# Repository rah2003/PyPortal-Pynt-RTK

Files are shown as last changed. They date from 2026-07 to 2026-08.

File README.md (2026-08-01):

# PyPortal-Pynt-RTK — Single-Board RTK Field Device

Third build in the RTK series, following the Metro ESP32-S3 build
([`rah2003/SWMaps-propertylines`](https://github.com/rah2003/SWMaps-propertylines),
branch `claude/esp32-rtk-bridge-firmware-yokgan`) and the interim two-MCU
RTK-Feather build (local, `C:\Projects\RTK-Feather`). This build collapses
everything onto one board: an Adafruit PyPortal Pynt drives the ArduSimple
simpleRTK2B Lite (u-blox ZED-F9P) over **F9P UART1**, keeping **UART2 free
for a future plug-in radio**.

## Hardware

| Role | Part |
|---|---|
| MCU + display | Adafruit PyPortal Pynt (#4465) — ATSAMD51J20 @ 120 MHz, 2.4" 320×240 ILI9341 TFT (8-bit parallel), resistive touch, microSD, 8 MB QSPI flash |
| WiFi | ESP32 AirLift co-processor (NINA-W102) on the Pynt, driven over SPI (WiFiNINA) |
| GNSS | ArduSimple simpleRTK2B Lite (u-blox ZED-F9P), UART1 via Pixhawk JST-GH — **moved over from the RTK-Feather rig** |
| Antenna | Calian/Tallysman HC977 helical (33-HC977-35, 35 dB LNA), triple-band + L-band, 3.3 V bias ~21 mA, no ground plane needed |
| Storage | PNY Elite 32 GB microSDHC UHS-I U1 (in the Pynt's slot) |
| Phone | iPhone + **SW Maps over BLE NUS** (Phase 5, verified 2026-07-28) and/or **QField over WiFi TCP** (verified 2026-07-19) — both links run simultaneously |

## Hard constraints (inherited + new)

1. **F9P UART2 / XBee socket is reserved** for a future plug-in radio. No
   firmware function may depend on it. (Base mode may *configure* RTCM3
   output on UART2 — config only, no wiring.)
2. **F9P UART1 is the Pynt's working port** (RTCM3 in; NMEA + UBX out) via
   the Pynt's D3/D4 hardware UART. ⚠ **The Pynt's D3/D4 sockets are
   reportedly silkscreen-swapped** vs. the classic PyPortal — verify with a
   scope/loopback before trusting labels (see `docs/QUESTIONS.md`).
3. ~~The AirLift cannot run WiFi and BLE simultaneously.~~ **Retired
   2026-07-28 (Phase 5):** the AirLift now runs the vendored
   `nina-fw 3.0.1-airlift` module firmware (BLE HCI multiplexed onto the
   SPI link) with the upstream WiFiNINA 2.1.1 + ArduinoBLE 2.1.0 host
   stack — WiFi + BLE simultaneous, proven in a 75-min soak on the
   assembled unit (`docs/coex-bench.md`). The `pynt-rover` env still
   builds the original WiFi-only Adafruit-fork stack, byte-identical,
   as the rollback path; `pynt-rover-coex` is the live configuration.
4. **The ESP32 AirLift and the microSD share the main SPI bus.** NTRIP/TCP
   traffic and RAWX log writes contend — the logging pipeline must tolerate
   SPI stalls (two-stage buffering, ported from the Feather build).
5. **The Lite's USB is an FTDI bridge onto UART1.** Never attach the
   u-center adapter while the Pynt drives UART1 — one driver at a time.

## Architecture (single MCU, cooperative superloop or light RTOS-less tasks)

```
                          ┌──────────── PyPortal Pynt (SAMD51) ────────────┐
 iPhone hotspot ──WiFi──► │ ESP32 AirLift ◄─SPI─► NTRIP client ─┐          │
                          │  (WiFi+BLE coex)                    ▼          │
 QField ◄───TCP/NMEA────► │  TCP server ◄──┬─ NMEA tee ◄─ UART (D3/D4) ◄───┼──► F9P UART1
 SW Maps ◄──BLE NUS─────► │  NUS notify ◄──┘      │       RTCM3 ▲──────────┘   (UART2: radio,
 browser ◄──HTTP :80────► │  web config GUI       │                            untouched)
                          │  UBX extractor ◄──────┘                        │
                          │       ▼                                        │
                          │  microSD (.ubx RAWX, shared SPI)               │
                          │  TFT 320×240 (8-bit parallel) + resistive touch│
                          └────────────────────────────────────────────────┘
```

Module lineage (ported/adapted copies, per the Feather precedent — not
submodules): `ringbuf.h`, `ubx_extractor`, `ntrip_client`, `gnss_config`,
`settings`/serial-menu from RTK-Feather & Metro. The Feather's two-MCU
`status_link` protocol disappears entirely. New modules: TFT/touch UI
(Adafruit_ILI9341 in 8-bit-parallel mode + touch driver), WiFiNINA transport
for NTRIP, TCP NMEA server, SD logger on shared SPI.

## Decisions (2026-07-11)

- **Toolchain:** PlatformIO, Arduino C++ (Adafruit SAMD51 core) — maximizes
  reuse of the proven Metro/Feather modules.
- **v1 scope:** Rover **and** Base mode, with RAWX `.ubx` logging to the
  Pynt's own microSD.
- **Phone link:** ~~SW Maps via WiFi TCP; no BLE ever on this hardware~~
  → since Phase 5: SW Maps over BLE NUS + QField over TCP, concurrently.
- **Touch UI:** status pages (fix quality, correction age, NTRIP state,
  logging, sats/SNR) + touch controls (log start/stop, rover/base switch,
  safe shutdown). Credentials/config via USB serial menu — no on-screen
  keyboard in v1. **Portrait orientation (240×320)** — enclosure comes
  after the electronics and will be built around portrait mounting.
- **Repo:** public GitHub, `PyPortal-Pynt-RTK`. Secrets via gitignored
  `secrets.h` (`secrets.example.h` committed), same as Feather.
- **Inherited defaults (from Metro via Feather):** caster
  `www.acorn-gnss.net:2101` (2026-07-19: the bare apex hostname the Metro
  build used lost its DNS A record — `www.` is the live caster now),
  mounts `VRS_SouthCentral_RTCM3`/`MS_RTCM3`, WiFi
  via iPhone personal hotspot, elevation mask 12°, constellations
  GPS+GLO+GAL+BDS (SBAS/QZSS off), F9P UART1 @ 115200.

## Repository layout

```
docs/
  QUESTIONS.md              Open/answered clarifying questions
  hardware/
    wiring.md               4-wire interconnect, label-swap check, SERCOM recipe
    power.md                Power tree decision (shape A/B) + checks P1-P4
    platform.md             Bus map, SPI contention math, TFT/touch notes
    ucenter-config.md       F9P re-verification (unit moved from Feather rig)
    checklists.md           Per-board bring-up + integration gates
  coex-bench.md             Phase 5 bench: spikes, soaks, findings, rollback
  web-config-spike.md       Web GUI plan + W0-W5 bench results
firmware/
  pynt/bringup/             Phase 1 serial-menu test suite
  pynt/rover/               Rover firmware (superloop: gnss, ntrip, tcp_nmea,
                            ble_nus*, web_config*, sd_logger, ui, serial_menu,
                            settings — * = coex env only)
  nina-fw-airlift/          Vendored arduino/nina-fw 3.0.1 + MOSI-14 patch
                            (the AirLift module firmware; AIRLIFT.md)
  spike/                    Spare-board spikes + esptool passthrough bridges
lib/                        Vendored ArduinoBLE 2.1.0 (patched) + Arduino_SpiNINA
tools/webui/                Web GUI source -> gzipped PROGMEM asset pipeline
platformio.ini              pynt-bringup, pynt-rover (WiFi-only fallback),
                            pynt-rover-coex (live: WiFi+BLE+web), spikes,
                            passthrough-* flash bridges
```

## Phases

- [x] **Phase 0 — Hardware verification pack** (`docs/hardware/`): wiring
      diagram (Pixhawk JST pinout → D3/D4, incl. the label-swap check),
      power tree (single-bank vs two-feed; decision pending measurements
      P1–P4), u-center re-verification checklist, bring-up checklists,
      platform/SPI-contention analysis — **verify wiring against these
      documents and current vendor docs before powering anything**.
- [x] **Phase 1 — Bring-up sketches**: serial test menu covering TFT +
      portrait rotations, touch raw dump, AirLift version/scan/join + TCP
      echo (the SW Maps path), SD write latency, D3/D4 UART loopback +
      TX-socket identify (the label-swap tests), live NMEA echo, free-RAM
      report. **Bench pass complete** (`docs/hardware/bringup-log.md`,
      2026-07-17): silkscreen swap confirmed real (sockets tape-labeled),
      touch pin off-by-one found and fixed (18/19/20/21), rotation 2
      chosen, corner calibration captured, WiFi/TCP/SD all healthy.
- [x] **Phase 2 — Rover firmware**: written and **compiling clean**
      (2026-07-11: RAM 9.7 % / flash 10.3 %, `pynt-rover` env). NTRIP
      state machine (ported Metro→Feather→here, polled instead of tasked)
      → RTCM3 → F9P UART1; GNSS config via SparkFun v3 VALSET; RAWX/SFRBX
      → SparkFun file buffer → time-named `.ubx` on SD (one bounded
      512 B write per loop pass, pre-allocated contiguous files, 8 s
      sync); portrait touch UI (fix-state header, POS/SYS pages, LOG /
      PAGE / PWR buttons with two-tap shutdown confirm); SW Maps TCP NMEA
      server on :10110; SD `/config.txt` settings + serial menu.
      **1-hour full-stack soak PASSED 2026-07-19** (bringup-log.md §3
      gate 4): 66 min, zero resets, RTK FIX from minute 2 to the end,
      NTRIP uninterrupted, 10.8 MB RAWX written (~10 MB/h). Found live:
      caster DNS moved to `www.`, nina-fw TCP accept is data-gated, and
      a client-dedup bug (fixed) — see Q19. Touch buttons + on-screen
      BUFH still unverified (headless soak).
- [x] **Phase 3 — Base mode**: written and **compiling clean** (2026-07-11:
      RAM 9.7 % / flash 11.1 %). Survey-in (dur/acc from settings) or
      fixed-LLH TMODE; RTCM3 out **configured on UART2 only** (MSM4 set
      1005/1074/1084/1094/1124/1230 — config only, the XBee socket stays
      empty and UART2 baud is left for the future radio to decide);
      NAV-SVIN progress in the header + SVIN line; `b_` log prefix; live
      rover/base switch via serial menu (`mode=base`). **Spot check
      PASSED 2026-07-19**: live switch both directions, survey-in valid
      at 300 s / 1.46 m on the defaults, UART2 untouched. (The `b_`
      prefix needed a same-day fix — the log now rotates on a live mode
      switch; rotation re-check pending next bench sit.)
- [ ] **Phase 4 — Polish**: logging analytics, light-sensor auto-dim,
      speaker fix/loss chime. (On-screen config keyboard **descoped** —
      the Phase 6 web GUI covers all credential/config entry.)
- [x] **Phase 5 — WiFi+BLE coexistence — DONE 2026-07-28**
      (`docs/coex-bench.md`, branch `coex/nina-fw-airlift`): vendored
      arduino/nina-fw 3.0.1 with a one-pin AirLift patch (SPI MOSI
      12→14), host stack swapped to upstream WiFiNINA 2.1.1 +
      ArduinoBLE 2.1.0 (vendored, 2-line SPI-HCI transport gate patch)
      + Arduino_SpiNINA. De-risked on a Metro M4 AirLift and a
      hand-wired HUZZAH32 rig before touching the Pynt (stock firmware
      backed up first; §8 rollback keeps `pynt-rover` untouched).
      75-min integration soak on the assembled unit: RAWX + NTRIP +
      TCP + BLE NUS concurrent, zero NTRIP teardowns, 50k TCP
      sentences no drops, ~58 min BLE streaming — **owner ran iOS
      SW Maps live over BLE** (Q19 closed, both phone paths).
      Notable firmware truths found and designed around: data-gated
      `server.available()` (fixed via `accept()`), `WiFi.end()` wedges
      STA rejoin, the NINA socket table leaks across `WiFi.end()`,
      `scanNetworks()` kills any live network, and this Pynt's UF2
      bootloader wedges when parked idle (flash via 1200-touch flow).
- [x] **Phase 6 — Web config GUI — v1 (W0–W5) DONE 2026-07-31**
      (`docs/web-config-spike.md`, branch `web-config`): on-board HTTP
      server (port 80, Basic auth, TRNG-generated passwords shown on
      the TFT WEB page) serving a gzipped-from-PROGMEM SPA — live
      status dashboard, WiFi provisioning with a touch-button AP mode
      (both AP transitions are reboots by design), GNSS tuning (rate /
      dynamic model / mask / GSV via live VALSET), caster management
      (live reconnect), logging control, BLE + System cards (instant
      admin-password rotation). W6 (mDNS, sourcetable browser, SD file
      manager, profiles) deferred.

## Reference builds

| | Metro (primary) | RTK-Feather (interim) | **This build** |
|---|---|---|---|
| MCU | ESP32-S3 (dual core) | HUZZAH32 + M0 Adalogger | SAMD51 (single) |
| WiFi | native | native (HUZZAH32) | ESP32 AirLift co-proc (SPI) |
| Display | — | 128×32 OLED + 3 buttons | 320×240 TFT + touch |
| Logging | on-board | second MCU + SD | on-board microSD (shared SPI) |
| Phone | BLE NUS | deferred | BLE NUS + WiFi TCP, concurrent |
| Config | serial | serial | web GUI + touch + serial |
| Status | Phases 1–3 built | retired (boards are coex spares) | Phases 0–3, 5, 6 done; field-proven |

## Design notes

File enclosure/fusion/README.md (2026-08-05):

# Fusion workflow

`pynt_rtk_enclosure.py` builds the rev A enclosure (Shell + Cover
components) as a fresh parametric document inside Autodesk Fusion. It is
a geometry port of `../pynt_rtk_enclosure.scad`; design rationale lives
in `docs/hardware/enclosure.md`. Edit the constants at the top of the
script and re-run to regenerate — it never touches the active document.

## Run it

1. Fusion → **Utilities → Add-Ins → Scripts and Add-Ins** (Shift+S)
2. Green **+** next to *My Scripts*, browse to this `enclosure/fusion/`
   folder
3. Select `pynt_rtk_enclosure` → **Run**

A dialog reports the key derived numbers (exterior size, pole-shoulder →
antenna-pad height for the SW Maps antenna-height entry).

## Fit-check with vendor CAD

`../vendor/` holds the manufacturers' own models — insert them with
**Insert → Insert CAD** and position against the enclosure:

| File | What | Source |
|---|---|---|
| `pyportal_pynt_4465.step` | PyPortal Pynt | Adafruit_CAD_Parts (GitHub) |
| `simpleRTK2B_Lite-00.step` | simpleRTK2B Lite | ardusimple.com |
| `ardusimple_usbc_carrier.step` | USB-C XBee carrier | ardusimple.com |
| `pyportal_pynt_4465.stl` | Pynt mesh (backup) | Adafruit_CAD_Parts |

The folder is gitignored (large binaries); re-download from the sources
above if missing.

## Test prints

Set `PART = 'base_test'` or `'bezel_test'` at the top of the script and
run — the trimmed body is exported automatically to
`enclosure/prints/<part>.stl`. `base_test` is the bottom 25 mm (nut
pocket fit, USB plug vs boss clearance, SD reach, vent grilles);
`bezel_test` is one top bezel corner (window chamfer vs touch reach,
eyebrow, one top-ear insert pocket). Same regions as the .scad `part`
selector. Print both front-face-down like the shell; `base_test` needs
a local support block under the nut boss's bed-facing face (a plain
90° side overhang — see the print notes in `docs/hardware/enclosure.md`
for why it can't be chamfered), `bezel_test` is support-free.

## Export for printing

Right-click **Shell** / **Cover** in the browser → *Save As Mesh* → STL,
or 3D Print. Print notes (material, orientation, the two test prints)
are in `docs/hardware/enclosure.md`.

## Before printing for real

- Carrier dimensions are settled: the owner's mini-USB FTDI carrier is
  identical to the USB-C carrier except the connector (confirmed
  2026-07-19), so the STEP-derived `CARRIER_*` defaults apply.
- `PYNT_MIRROR = -1` confirmed 2026-07-19: USB on the viewer's left
  looking at the screen.
- Cover screws are plain through-holes — use **pan-head** M3s (no
  countersinks modeled).

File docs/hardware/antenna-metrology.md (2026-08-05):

# Antenna Metrology — ARP & Phase-Center Offsets (2026-08-04)

Closes the 2026-08-03 team review's **P6** finding ("no ARP, no antenna
height, no phase-centre data anywhere"). Owner-confirmed 2026-08-04.

## ARP definition (this build)

**ARP = the nut-boss underside** — the D-shaped ring (679 mm²) around
the Ø17 pole hole at the bottom of the enclosure. It is simultaneously:

- the bottom face of the 5/8"-11 nut pocket's boss,
- the **global lowest surface of the assembled enclosure** (verified by
  exhaustive enumeration of every down-facing face in the as-printed
  meshes `enclosure/prints/b_shell_full.stl` + `b_band_full.stl`:
  zero vertices below it), and
- the **print-bed face** (both rev-B parts print nut-side down).

The pole stud passes through the Ø17 clearance hole; the 5/8"-11 nut is
captured in the hex pocket above; nothing seats internally — the pole
top bears on this same exterior face.

## Enclosure vertical stack (model frame: 0 = housing exterior floor)

| Plane | Height | Source |
|---|---|---|
| ARP (nut-boss face, print bed) | **−17.2** | `BOSS_H = nut 13.9 + 0.3 + floor 3.0` |
| Screw-head seats (recessed in funnel) | −2.0 | mesh |
| Housing exterior bottom (USB/SD face, 756 mm²) | 0.0 | mesh |
| Shell top exterior | +88.6 | `EXT_H` |
| **HC977 seat plane** (Ø44.8 recess floor in the lid pad) | **+89.1** | `EXT_H + pad 1.5 − recess 1.0` |
| Antenna pad top | +90.1 | mesh |

**A = ARP → antenna seat = 89.1 − (−17.2) = 106.3 mm.
Total case height (ARP → pad top) = 107.3 mm.**

Geometry facts (measured from the meshes, not just the source scripts):
pole axis and antenna boresight are **collinear** (hole/recess/SMA
centroids concentric within ≤0.3 mm of tessellation noise), both normal
to the ARP plane — **0° tilt, ~0 horizontal offset**. The axis sits at
X = 0, 31.0 mm behind the front face. Antenna clocking: the a=0 M2.5
hole points dead rearward (antenna "north" away from the screen).

## HC977 phase-center data (Calian datasheet Rev. 202203 + mechanical drawing)

Antenna: Calian/Tallysman **HC977**, part 33-HC977-35 (35 dB LNA),
s/n 20200624 (Q15). PCO along the antenna z-axis from its base
(= our seat plane):

- **L1: 32 mm** · **L2/L5: 37 mm** · PC variation **±3.0 mm** per band
  (note: L1 and L2/L5 are *distinct* nominal phase centers 5 mm apart —
  not one shared PC)
- Sources: datasheet spec table ("PCO (z-axis, mm): 32 (L1), 37 (L2)")
  and `HC977_MECHANICAL_DRAWING.svg` ("L1 = 32 mm, L2 / L5 = 37 mm"),
  both at <https://www.tallysman.com/product/hc977-triple-band-helical-antenna-with-l-band/>
- Antenna: Ø44.2 × 62.4 mm, 42 g, base mount 3× M2.5 (6 mm deep, 120°,
  Ø26.6 BCD) — **no native 5/8"-11 thread**; this enclosure IS the
  5/8"-11 adapter.

## The numbers a surveyor needs

```
ARP → L1  phase center = 106.3 + 32 = 138.3 mm   (±3.0)
ARP → L2/L5 phase center = 106.3 + 37 = 143.3 mm (±3.0)
horizontal PC offset from pole axis ≈ 0 (coaxial, 0° tilt)
```

Antenna height for RTK work = pole/ARP height + the offset above for
the band your software expects (L1 is the usual convention). For RINEX
post-processing of the RAWX logs: ANTENNA: DELTA H = ARP height; apply
the per-band PCOs from this table.

## Verification note (one-time caliper check, still open)

The stack above is **design-nominal from the print meshes**. FDM
first-layer squish and the HC977's base O-ring can move reality a few
tenths of a millimeter. To close: caliper the assembled case —
**ARP face → pad top should read 107.3 mm** (or ARP → recess floor
106.3 with the antenna off). Record the measured value here.

Annotated views (generated from the print meshes):
`pynt-arp-side-annotated.png`, `pynt-arp-top-annotated.png` (this
directory). Design source: `enclosure/` at the repo root.

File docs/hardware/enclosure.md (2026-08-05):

# Enclosure — Design Doc (rev A8, 2026-07-20)

3D-printed handheld/pole-top enclosure for the full stack: PyPortal Pynt
(portrait, rotation 2), simpleRTK2B Lite on its USB carrier board, HC977
helical antenna on the lid, 5/8"-11 survey-pole nut captured in the base.
CAD sources: `enclosure/pynt_rtk_enclosure.scad` (parametric OpenSCAD)
and `enclosure/fusion/pynt_rtk_enclosure.py` (Autodesk Fusion build
script, same geometry — see `enclosure/fusion/README.md`). **The
parameter blocks are the single source of truth for numbers** — keep the
two in sync; this doc explains the *why*. Vendor STEP models for
fit-checks live in `enclosure/vendor/`.

Owner decisions (2026-07-18): printed on owner's FDM printer; handheld
unit with internal survey-pole nut; antenna on top of enclosure via the
owner's SMA extension cable; battery bank external for now (bottom
attachment possible later); light-rain resistant, not sealed.

Rev A1 (2026-07-19, after first Fusion build): interior deepened
41.5 → 52 so the full Ø46 antenna pad (HC977 base Ø44.2) lands on the
lid — rev A truncated it at the back edge. SMA bulkhead hole is plain
round (owner's adapter has no D-flat; lock washer inside for
anti-rotation). Battery provisions moved from the front floor corners
to the rear floor behind the nut prism — at the front they collided
with the Pynt's lower mounting ears.

Rev A2 (2026-07-19, owner assembly critique): `pynt_mirror` confirmed
**−1** — USB lands on the viewer's **left** looking at the screen in
rotation-2 portrait. The Pynt's **bottom ears are now pinned, not
screwed** (Ø2.7 pins into the Ø3.0 ear holes): the bottom cover posts
sit ~1 mm off that screw axis, so neither a driver nor an insert iron
could ever reach; the top two ears keep M2.5 heat-set inserts, which
have straight access past the top posts (14 mm off-axis). Vent slots
became 3-finger **grilles** so they can't be mistaken for ports, and
the SD slot's front edge is aligned with the USB slot's.

Rev A3 (2026-07-19): all printed heat-set inserts standardized to
**M3, Ø4.0 pilot** (owner stocks 4/6/8 mm lengths; per-location
lengths in the BOM) — M3 screws are a close fit through the Pynt's
Ø3.0 ear holes. Bottom-battery provisions **removed**; a future
battery dock will be its own design. Added **3× M2.5 through-holes in
the lid** on the HC977's insert bolt circle for a positive antenna
hold-down, one hole aimed dead rearward as the antenna-north
reference (see 8).

Rev A4 (2026-07-19, first test-print findings): bezel_test PASSED on
screen-flush fit and boss height; base_test failed on the locating
pins (horizontal stubs print badly, won't enter the ear holes) and
the round Ø8 top bosses hit the glass side edge (owner measured
~2.5 mm hole-center→glass). Fixes: top bosses are now rectangular,
trimmed 2.2 mm inboard, wall-merged outboard, 45°-tapered bottoms,
**direct-thread M3 (Ø2.5 pilots, no inserts)**; the bottom edge drops
into a **capture channel** beside the SD body sized for the bottom
edge's 2.9 mm display stack (1.0 less than the glass — owner
measured). PCB plane unchanged → USB/SD slots unchanged. Reprint both
test parts.

Rev A5 (2026-07-19): the eyebrow's 45° underside is now **colinear
with the window's top chamfer** — one continuous plane from the
window's inner top edge to the eyebrow tip. The old shape sat ~1 mm
off the chamfer plane and printed as a visible step / double edge
(bezel_test finding).

Rev A6 (2026-07-19): bottom capture moved from the board's bottom edge
to the **ears** — two slots at the side walls with a 2.0 mm gap for
the bare 1.6 mm PCB tabs (0.2 clearance per side) and a 45° rear
lead-in. Assembly is now: **slide the board straight down** until the
ears seat, then drive the two top screws. The rev-A4 bottom-edge
channel beside the SD body is deleted (its 2.9 mm bottom-stack
measurement stays recorded in the component table). Same day: rear
wall reworked — vertical capture face to y 5.7 with the lead-in bevel
halved (owner request: give the board's rear real vertical backing),
outboard gap end filled for print support.

Rev A7 (2026-07-20, base_test fit findings): **zero board standoff**
— the Pynt's bottom edge now sits ON the interior floor (`pynt_y0 =
floor_t`; any gap made USB/SD unreachable — everything keyed to the
board moves down with it, so the frame stays correct). **Bottom wall
halved to 1.4** (`floor_t`) for plug/card reach — combined the
connectors sit ~2.9 closer to the outside face. **SD slot widened
2 mm toward the enclosure center only** (slot read ~2 mm off
outboard). **Teardrop profiles** on all horizontally-printed round
holes (pole, SMA, 3 antenna holes — apex up in the front-face-down
print) so their tops print uncompressed. Ear slots re-referenced to
the floor; the base fill under the ear is gone (no gap remains).
Caveat: the nut load path now crosses a 1.4 floor — verify on the
base_test reprint before trusting pole mounting.

Rev A8 (2026-07-20, owner decision): the REFERENCE print orientation
for **both enclosures is now NUT-SIDE DOWN** (bottom-up). The nut
boss prints flat on the bed (no more support patch under it — that
whole problem disappears); pole / SMA / antenna holes are vertical
now, so they reverted to plain round (a teardrop notch would spoil
the SMA gasket seat); the **teardrops moved to the z-axis holes**
(light pinhole, Pynt pilots, cover-post pilots), which print
horizontally in this orientation. Supports still needed in rev A
bottom-up: the shell's interior lid ceiling (a large flat span) and
the window's top edge (long bridge). The cover still prints flat.

## Rev B — the "D" shell (owner-specified, 2026-07-20)

`enclosure/fusion/pynt_rtk_enclosure_b.py` (Fusion-only; rev A kept).
Owner's markup, implemented literally: **plan view is a "D"** — the
front/Pynt half is identical to rev A (all vertical walls stay
vertical, zero edits to the front), and the square rear corners are
removed. From the **antenna centerline (z 31)** the full-width sides
transition via straight **tangent lines** to a rear **arc R26.8 about
the pole axis** (= the current antenna→body rear standoff, so the
rear-most point stays at z 57.8 and the antenna footprint is always
covered).

- **Case back** = a curved band, same 2.8 thickness, constant profile
  down the entire height, flush with the outer surface. Captured on
  all four edges: it stands on the shell floor; its top edge rides in
  a 1.0 groove under the integral lid; its vertical end edges carry
  **half-thickness tongues (R24–25.4, 3.6° span)** that slide into
  matching grooves rebated into the tangent walls — full-height
  lateral support both sides (first band test read loose — groove
  clearances **halved** to 0.075 radial per side, +0.2/+0.35° angular
  padding; **re-print confirmed a good fit**, 2026-07-25). Behind each
  band end a **1.0 anti-flex ledge** stands proud of the interior face
  (same 0.075 stop gap) so the band bears on it instead of deflecting
  inward; the rib hooks ~0.6 into the tangent wall past the groove end
  so it's braced full-height, and prints support-free nut-side down; and 2× M3×8 come up from BELOW through
  the floor (heads face down — rain-safe) into **M3×4 heat-set
  inserts** (Ø4.0 pilots) in bosses welded to the band — inserts set
  from the boss undersides before the band goes in. Pull the band
  straight back for full-width service access.
- **Carrier**: mount plane z 48.5 (assembly finding 2026-07-26: +1.0
  more standoff needed; gusset undersides steepen to ~51°, still
  support-free) — originally moved inside so
  the M3×4 teardrop pockets keep ≥1.0 outer skin (shallower bosses
  let the cuts show through the back — owner catch), and the grid is
  **raised 2.5** (`carrier_y0` 8.5) so the lower bosses clear the
  case-back insert bosses (interference — owner catch). Every boss
  carries a **45° gusset fin** tapering to the band's inner face, so
  the horizontal bosses print support-free. Stack front z 34.2; radio
  void intact.
- The old rear corner posts are gone with the corners. The **nut boss
  is a mini-D echoing the shell**: flat front at z 16.5 (USB plug
  clearance preserved), straight sides to the pole axis, rounded back
  R16.5 — same 2.4–2.5 walls around the hex pocket as the old prism.
  A **D-shaped funnel skirt** lofts from the boss bottom out to the
  housing outline at the base plane: planar tapers on the flats
  (~51°), lofted arc taper on the back (~59°), shared flat front
  plane at z 16.5 so the USB/SD/vent strip stays clear — and the
  underside becomes self-supporting in the bottom-up print. The
  case-back screws pass straight through the funnel as **plain
  clearance holes with Ø6.6 counterbores** (no added bosses — owner
  decision): at z 48.8 the head seat at y −2 is a complete ring, and
  the bore columns are cut clear down to **below the funnel surface's
  deepest point** (a shallower cut leaves an uncut crescent shelf
  inside the bore that blocks the screw head — owner caught it as a
  non-round mouth). Verified: Ø5.7–6.0 pan head travels the clean
  Ø6.6 column to the seat and back with ≥0.3 radial clearance.
  M3×8 reaches ~4 mm into the inserts. **Sharp exterior edges are
  chamfered**: 1.2 on the front vertical corners and top rim, 0.6 on
  the front strip's 90° edges (bottom line, strip sides, strip↔funnel
  crease at z 16.5 — owner markup); the shallow funnel/wall creases
  are excluded (any chamfer there fails to compute, and at ~40° they
  aren't truly sharp). Test-fit prints:
  `enclosure/prints/b_base_test.stl` (bottom 30 — funnel, boss,
  counterbores, ear slots, USB/SD, tongue grooves) and
  `b_band_test.stl` (band segment with insert bosses + tongues).
  All bottom penetrations and the whole front half carry over from
  rev A8 unchanged; lid pad/SMA/BCD holes unchanged on the pole axis.
- **Print**: both parts nut-side down. The band is a constant-section
  tube segment — zero support; the shell keeps rev A's caveats
  (interior lid ceiling + window top edge). Full print files:
  `enclosure/prints/b_shell_full.stl` (57.8 cm³) and
  `b_band_full.stl` (14.4 cm³), pre-oriented Z-up for the slicer;
  MK4S/PETG settings incl. the lid-ceiling support plan in
  `enclosure/prints/print-settings-mk4s-petg.md` (paint-only
  enforcers: interior ceiling, front strip underside, window lintel;
  0.25 contact Z, snug style, extract the block through the rear
  aperture).

## Concept

```
            HC977 helical (Ø44 base, 62 mm tall)
                 │  screws onto ↓
        ┌── SMA bulkhead jack through lid, on the pole axis ──┐
  ┌─────┴──────────────────────────────┐  ← lid/top face      │
  │  JST headroom (D3/D4 harness U-turn)│                      │
  │ ┌───────────┐  ┌──────────────────┐│                      │
  │ │ PyPortal  │  │ carrier + Lite   ││  ← removable back    │
  │ │ Pynt      │  │ stack on the     ││    cover (4× M3)     │
  │ │ portrait, │  │ back cover;      ││                      │
  │ │ screen in │  │ XBee radio void  ││                      │
  │ │ front face│  │ above the Lite   ││                      │
  │ └───────────┘  └──────────────────┘│                      │
  │  USB out ↓   SD ↓   [5/8-11 nut]───┼── pole axis ─────────┘
  └─────────────────┬──────────────────┘
                    └─ external hex boss under the base, nut captured
                       inside; survey pole threads in from below
```

- **Pole axis** (X = width center, 31 mm behind the front face) carries
  both the 5/8-11 nut below and the SMA bulkhead above, so the antenna
  sits plumb over the pole. It lands behind the box's geometric depth
  center because the bottom boss must clear the USB/SD exits at the
  front of the base — slightly nose-heavy in hand, irrelevant on a pole.
- **All signal wiring is internal.** Only four penetrations exist: SMA
  bulkhead (top, gasket-washer sealed — proper rain-proof joint),
  micro-USB power slot (bottom, faces down), microSD slot (bottom, faces
  down), light-sensor pinhole (front bezel). No side penetrations.

## Component facts the geometry is built on

All verified from vendor CAD unless flagged. Sources: Adafruit
`Adafruit PyPortal Pynt.brd` + `4465 PyPortal Pynt.step`
(github.com/adafruit/Adafruit-PyPortal-PCB, Adafruit_CAD_Parts);
ArduSimple `simpleRTK2B_Lite-00.STEP` + USB-C carrier
`AS-ADP-USBC-TO-XBEE-00-R00.step` (ardusimple.com); Calian HC977
datasheet Rev 202203.

| Component | Numbers that matter |
|---|---|
| PyPortal Pynt (#4465) | Body 66.8 × 43.2 × 1.57 mm — **not** the classic-PyPortal outline. Envelope incl. 4 mounting ears 66.8 × 53.2. Holes Ø3.0 on a 61.72 × 47.88 grid (M2.5). Stack: touch overlay +3.90 front / JSTs +4.80 back → 10.27 total. Viewing window 50.25 × 38.6, centered on the body. Micro-USB + microSD on one short edge (down, in rotation 2), D3/D4 JSTs on the other (up). Reset faces **backward**; light sensor looks through the PCB to the **front**. Owner-measured 2026-07-19: display stack at the bottom edge is 2.9 (1.0 less than the 3.9 glass stack); glass side edges ≈2.5 mm from the top ear hole centers. |
| simpleRTK2B Lite | PCB 27.68 × 41.53 × 1.0. Edge-launch SMA jack protrudes 9.5 past the SMA edge. JST-GH tallest top-side part (+4.35). Underside XBee pins protrude **5.97 below** the PCB. 3× Ø2.1 holes (unused here — the carrier is the mount). |
| USB carrier (ArduSimple XBee FTDI carrier, mini-USB variant) | PCB 41.0 × 26.0 × 1.6; 4 corner holes ~Ø3.6 on a **35.0 × 20.0** grid, 3 mm from each edge. Assembled carrier+Lite stack ≈ 15.3 tall incl. underside solder tails; Lite overhangs the non-USB end, SMA tip ≈ 17.2 past the carrier edge. Dimensions taken from the USB-C variant's STEP (AS-ADP-USBC-TO-XBEE-00) — **owner confirmed 2026-07-19 the mini-USB board is identical except the connector itself**, which is internal-only here, so the USB-C numbers apply as-is. |
| HC977 (33-HC977-35) | Radome: base Ø44.2, top Ø38.8, h 62.4, IP69K, 42 g. SMA male on base underside + 3× M2.5 inserts, 6 deep, 120°, on a **Ø26.6 bolt circle** (Calian mechanical drawing, confirmed 2026-07-28; O-ring on the base underside). Phase center above base: 32 mm (L1) / 37 mm (L2). 2.5–16 V bias — a passive SMA extension passes the F9P's 3.3 V untouched. |
| 5/8"-11 hex nut (steel) | Across flats 23.8, across corners ≈ 27.5, thickness ≈ 13.9. Plastic never carries the thread. |

## Layout decisions

1. **Pynt mounting (rev A4)**: the **top two ears screw** — M3×6
   **threading directly into Ø2.5 pilots** (no inserts: the glass side
   edge is only ~2.5 mm from the hole center, so there is no room for
   an insert-sized boss; M3 is a close fit through the Pynt's Ø3.0
   ear holes; driven from the back with the cover off, straight
   access 14 mm clear of the top posts). Bosses are **rectangular,
   trimmed to 2.2 mm inboard** of the hole center (≈1 mm wall beside
   the pilot, ~0.3 mm clear of the glass), merged into the side walls
   outboard, 45° taper on the bottom face (support-free in any print
   orientation). The **bottom ears slide down into capture slots** at
   the side walls: each slot is a 2.0 mm gap (0.2 clearance per side
   of the 1.6 PCB tab) between a front block (z 3–7.2, trimmed 2.0 mm
   inboard of the hole center to clear the glass) and a rear wall
   with a **vertical capture face (z 9.2) up to y 5.7** — real rear
   backing for the PCB's lower 1.4 mm — topped by a **halved 45°
   lead-in** (y 5.7 → 7.3) for the slide-down entry. The outboard end
   of the gap (past the ear tip, ~0.9 mm from the side wall) is
   filled to anchor the rear wall's printed underside; the remaining
   ~1.6 mm underside overhang over the gap prints clean. **End stops
   relieved to ±27.3 (2026-07-26)**: the first assembly bound one top
   screw — the symmetric stops centered the board while the pilots
   follow the STEP's hole grid (midpoint 0.19 off the body
   centerline), and M3 through the Ø3.0 ear holes has ~zero slop, so
   two conflicting datums can't coexist. The slots now only capture
   the ears vertically; the board centers laterally on the screws
   (start both before tightening). On the USB
   side the rear pieces also stop 0.25 mm outboard of the USB slot so
   the plug path stays clear (the front block, z ≤ 7.2, never
   conflicts — the USB slot spans z 8–13); the vent grilles sit at
   centers ±14.5 to clear the slot blocks. Assembly:
   slide the board straight down until the ears seat, then drive the
   top screws. No bottom screws or pins — the
   bottom cover posts sit ~1 mm off the ear screw axis (no driver
   access) and printed pins don't survive printing. Slots + top
   screws fully constrain the board; the PCB plane stays at z 7.4, so
   the USB/SD slots are unchanged. Standoff height 4.4 mm puts the
   touch overlay ~0.5 mm behind the front wall's inner face
   (foam-tape shim closes the gap and keeps rain from wicking around
   the glass edge) — confirmed flush on the bezel_test print.
2. **Carrier + Lite mount on the back cover**, not the shell: the cover
   prints flat with four M3 bosses at the carrier's 35 × 20 grid, so the
   whole GNSS stack comes out with the cover for service. Lite's SMA
   points **up** (toward the lid bulkhead), which puts the carrier's USB
   end **down** — u-center access is: remove cover, unplug the D3/D4
   pigtail (contention rule in `wiring.md`), plug USB. The port is
   deliberately *not* reachable from outside; opening the back puts the
   pigtail in your hand as a physical reminder of the one-driver rule.
3. **XBee radio void**: ≥12 mm is reserved above the Lite's top face for
   a future socketed XBee-format radio (a whip-antenna radio needs
   25–30 mm and would take a reprinted or bulged cover — accepted).
4. **D3/D4 harness** exits the Pynt's top edge into ~14 mm of headroom
   under the lid, U-turns, and drops to the Lite's JST-GH on the back
   cover. Sized for JST-PH plug depth (~7 mm) plus bend.
5. **Reset has no external hole** (rain win). Field reset = USB power
   cycle; bootloader double-tap happens on the bench with the cover
   off. The button faces the service side, reachable with a stick past
   the carrier.
6. **Light sensor pinhole** (Ø2.5) in the bezel's bare strip below the
   window — needed if Phase 4 auto-dim ever ships; plug it with a dab
   of clear epoxy if rain paranoia wins.
7. **Rain strategy**: eyebrow ridge across the front face above the
   screen window — its 45° underside is colinear with the window's
   top chamfer, one continuous plane with no step; window walls
   chamfered outward so the recessed overlay sheds; cover skirt overlaps the shell in a labyrinth; all
   other penetrations face down; two bottom 3-finger vent grilles
   (heat from the AirLift) double as drains — grille fingers so they
   read as vents, not ports.
8. **Antenna seat**: the lid carries a raised Ø46 pad with the SMA
   bulkhead jack (female, gasket washer outside, nut inside) at its
   center; the HC977's base lands on the pad so side loads don't ride
   on the connector alone. The pad is a **full circle** — the interior
   depth is sized so it fits ahead of the back face (axis 31 + r 23 +
   1 margin = 55 shell depth) and the antenna's whole base is
   supported. The bulkhead hole is **plain round** (Ø6.8 printed):
   the owner's SMA adapter has no D-flat, so anti-rotation comes from
   the lock washer under the inside nut. **Antenna hold-down +
   orientation**: 3× Ø3.1 through-holes on the HC977's insert bolt
   circle — **Ø26.6 per the Calian mechanical drawing** (3× M2.5,
   6 deep, 120°; corrected 2026-07-28 from the 28.0 placeholder that
   made it into the first full shell print — those holes sit 0.7 out
   and need ~0.5 elongated inward to salvage) — taking M2.5×8 screws
   from inside the lid into the antenna's own inserts. One hole aims
   dead **rearward** (+z): mount the antenna with its north reference
   at that screw so antenna-north faces opposite the screen. The HC977
   has no published NGS/IGS calibration or formal north-reference
   point — if the radome carries no N mark, designate the insert
   nearest the cable label as the reference and keep it consistent
   between sessions (azimuth PCV error is small but repeatable).
9. **Pole nut**: external hex boss under the base; the nut drops into a
   hex pocket through the interior floor opening (cover off), and a
   Ø17 clearance hole in the boss floor admits the pole stud. Load
   path: pole shoulder → boss floor → bottom wall. The boss's front
   face sits at z = 16.5, behind both the USB plug body (rear ≈ z 14.5
   for a typical overmold) and the SD card path — that clearance is
   what pushed the pole axis to 31 mm (the interior depth is set by
   the antenna pad instead — see 8).
   **Dry-fit your actual USB cable against a `base_test` print before
   committing** (fat overmolds exceed the 2 mm margin; a right-angle
   cable is the fallback).
10. **Battery attachment: removed** (rev A3, owner decision). A future
    battery dock will be a separate design; the nut boss flats and the
    pole thread remain the natural docking features. The rev A1/A2
    provisions (rear-floor bosses + cover lip notches) are deleted.

## Budget (from the .scad defaults — regenerate after any param change)

- Interior: 55.0 W × 83.0 H × 52.0 D
- Exterior shell: 60.6 W × 88.6 H × 57.8 D (plus 17.2 mm nut boss below,
  1.5 mm antenna pad above)
- Depth stack, front→back: 3.0 wall · 0.5 foam · 3.9 glass · 1.6 PCB ·
  4.8 JSTs · ~16 air · 12 radio void ending at the Lite's top face ·
  carrier+Lite stack 15.3 on 3.5 cover bosses · 2.8 cover (the radio
  void sits over the Lite's socket footprint; the JST-GH and SMA poke
  forward of it at the top edge — not a linear sum). Depth is set by
  the antenna pad (see 8), not the electronics stack.
- Any common printer bed fits it standing on the front face or split.

## Antenna height bookkeeping (for SW Maps)

Pole-shoulder plane (boss underside) → lid pad top ≈ 107 mm (read the
exact value from the .scad echo), + bulkhead/antenna-base stack ≈ 2 mm,
+ 32 mm L1 phase-center offset. So **APC ≈ pole length + ~141 mm** —
recompute from the final print + measured bulkhead stack and put the
result in SW Maps' antenna-height field, per the datasheet offsets.

## Print & hardware notes

- **Material: PETG or ASA** (outdoor UV + parked-car heat; PLA will
  creep at the nut boss). 40 %+ infill or 5 perimeters around the nut
  boss and screw bosses; 2.8 mm walls elsewhere.
- Shell prints front-face-down (window bridges are short; the eyebrow's
  45° underside chamfer is modeled, support-free). Cover prints flat,
  bosses up. **The nut boss is a plain prism** — its bed-facing front
  face (~33 × 17 mm at z 16.5) is a true 90° side overhang and needs a
  **local support block** (paint-on support in the slicer). 45° blends
  are geometrically impossible here: an additive wedge forward of the
  boss sits in the USB/SD plug path, and a subtractive chamfer (any
  direction) breaches the hex-pocket walls (2.4 mm). Everything else
  prints support-free. Applies to `base_test` too — same orientation,
  same support patch.
- Hardware BOM — printed inserts are **M3 heat-set, Ø4.0 pilot**
  (owner stock 4/6/8 mm): **M3×4** in the carrier bosses (blind
  pockets — longer inserts would break out), **M3×6 or ×8** in the
  cover posts (9 mm pilots). The Pynt top ears use **no inserts**:
  M3×6 screws thread directly into Ø2.5 pilots (no room for an insert
  beside the glass; the board is rarely removed). Screws: 2× M3×6
  (Pynt top ears), 4× M3×6 (carrier), 4× M3×10 pan (cover). Plus 3×
  M2.5×6 (antenna hold-down, into the HC977's *own* inserts — verify
  insert depth; through-thickness at the holes is 3.3 mm), 1× steel
  5/8"-11 hex nut, 1× SMA male↔female-bulkhead extension (owner has),
  foam tape for the glass perimeter, optional silicone washer under
  the bulkhead.

## Open items before first full print

- [x] ~~Caliper the carrier~~ — resolved 2026-07-19: owner confirmed the
      mini-USB carrier matches the USB-C carrier except the connector,
      so the STEP-derived `carrier_*` defaults stand. (Sanity-check the
      hole grid at the cover dry-fit anyway — it's a 10-second check
      with the screws in hand.)
- [x] ~~Confirm portrait handedness~~ — resolved 2026-07-19: USB is on
      the **viewer's left** looking at the screen (`pynt_mirror = -1`).
- [ ] Measure inserted-SD-card protrusion (Adafruit doesn't model it) →
      finger-recess depth.
- [x] ~~Measure the HC977 insert bolt circle~~ — resolved 2026-07-28
      from the **Calian mechanical drawing: BCD Ø26.6** (3× M2.5 deep
      6, 120°); `ant_bcd` corrected in all three models. The drawing
      does dimension it — the earlier "not in the datasheet" note was
      wrong (only the spec page omits it). Still check the radome for
      a north/index mark at mounting time.
- [ ] Reprint `base_test` (rev A6: ear capture slots, slide-down
      assembly) → ear slot fit + slide feel, nut pocket fit, USB plug
      clearance, SD reach. First prints confirmed USB/SD slot
      alignment.
- [ ] Reprint `bezel_test` (rev A4: trimmed tapered bosses,
      direct-thread Ø2.5 pilots) → boss-vs-glass clearance and M3
      direct-thread feel. First print confirmed screen-flush fit and
      the 4.4 boss height.
- [x] ~~P3/P4 power checks~~ — passed 2026-07-18 (P3 = 4.77 V under
      load, 30-min soak clean; `bringup-log.md` §3). The remaining
      pre-entombment gate is the Phase 2 **1-hour full-stack soak**.

## Antenna metrology (2026-08-04, owner-confirmed)

ARP = the nut-boss underside (print-bed face) — the global lowest
surface of the assembly (mesh-verified, nothing below it). Stack: ARP
−17.2 → HC977 seat +89.1 ⇒ **A = 106.3 mm**; total case height 107.3.
HC977 PCOs from the seat: L1 32 / L2·L5 37 (±3.0). **ARP → L1 PC =
138.3 mm; ARP → L2/L5 PC = 143.3 mm; coaxial with the pole, 0° tilt,
~0 lateral.** Full derivation + caliper-check protocol:
repo `docs/hardware/antenna-metrology.md`.

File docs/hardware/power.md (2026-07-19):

# Power Tree — decision doc (QUESTIONS.md Q8)

## Loads (measured/vendor figures)

| Load | Current | Source |
|---|---|---|
| SAMD51 @ 120 MHz | ~65 mA | typical M4 figure — measure at bring-up |
| TFT backlight (2.4") | ~40–80 mA | measure; PWM-dimmable (auto-dim is a Phase 4 feature) |
| ESP32 AirLift | ~250 mA peak (WiFi TX bursts), ~80 mA active | [Adafruit AirLift docs](https://learn.adafruit.com/adafruit-airlift-breakout) |
| ZED-F9P (Lite) | ~130 mA | ArduSimple/u-blox |
| HC977 antenna | ~21 mA typ (35 dB variant) | [Calian datasheet](https://www.tallysman.com/product/hc977-triple-band-helical-antenna-with-l-band/) |
| microSD write bursts | ~50–100 mA momentary | typical SDHC |

**System total ≈ 500–600 mA peak, ~350–450 mA typical.** Any single USB
bank port rated 1 A carries this with margin, and it is far above the
~50–100 mA auto-off threshold of picky banks — no keep-alive worries.

## Candidate shapes

### A. Single bank port, Lite fed through the Pynt (adopted — checks passed)

```
USB battery bank (1 port, ≥1 A)
 └── USB cable ──► Pynt micro-USB (5V VBUS)
                     ├── Pynt 3V3 reg ──► SAMD51 + TFT + AirLift + microSD
                     └── D4 JST VCC pin ──► Lite JST pin 1 (5V_IN)
                                              └── Lite's own 3V3 reg ──► F9P + antenna
Ground: D4 JST GND pin ──► Lite JST pin 6 (wired, not assumed)
```

One cable in the field, one thing to charge. The Lite regulates its own
3.3 V, so the ~150 mA GNSS load never touches the Pynt's 3.3 V regulator —
it only transits the Pynt's **5 V/VBUS copper**.

**Power/ground now come off the D4 JST connector itself** (not the I2C
STEMMA port as originally planned) — P1 below confirmed D3/D4 VCC reads
the same 5V as the STEMMA port, and D4 already carries a signal wire to
the Lite, so routing power off the same connector means the STEMMA port
stays fully unpopulated (this project has no I2C use). See `wiring.md`
for the full wire list.

**Blocking checks (completed at bring-up, 2026-07-17 —
`docs/hardware/bringup-log.md`):**

- [x] **P1 — D3/D4 JST power-pin voltage.** Measured 5V on both D3 and D4
      VCC pins, board powered from USB. This is what unlocked shape A's
      final form above — power sourced from D4 directly instead of a
      separate STEMMA connection.
- [x] **P2 — I2C STEMMA port 5 V confirmed.** Also measured 5V (jumper
      untouched, defaults intact) — but the port ended up unused per the
      D3/D4 decision above.
- [ ] **P3 — voltage drop under load.** Not yet done — do this at the
      power-only integration gate (Lite + antenna running, WiFi active,
      backlight full): measure at Lite JST pin 1, must stay ≥ 4.5 V.
- [ ] **P4 — 30-minute soak.** Not yet done — no brownout resets (SAMD51
      or F9P), no warm connectors.

### B. Two-feed fallback (zero doubt, more cabling)

```
USB battery bank (2 ports)
 ├── Port 1 ──► Pynt micro-USB
 └── Port 2 ──► USB breakout/pigtail ──► Lite JST pin 1 (5V_IN) + pin 6 (GND)
Common ground: REQUIRED — Lite pin 6 to Pynt GND (UART reference).
```

Adopt if any of P2–P4 fails. Port 2's ~150 mA load is above most banks'
auto-off floor but nearer to it — soak-test the actual bank (the Feather
project's bank-auto-off caution applies).

## Rules

1. **Never** feed the Lite from a Pynt 3.3 V pin (P-rail budget) or into
   the XBee socket VCC (it's an output).
2. The Pynt has **no battery charger** — there is no LiPo UPS story here.
   If the bank dies, everything dies together. Firmware treats "GNSS
   stream stopped" and undervoltage as flush-and-close triggers for the
   SD log regardless.
3. u-center USB adapter power is fine simultaneously with other supplies
   (ArduSimple-sanctioned) — the simultaneous-**data** prohibition in
   `wiring.md` is what matters.

## Smoke-test order (stop at any failure)

1. Bank + Pynt alone: boots, TFT lights, WiFi joins, SD mounts.
2. u-center pass on the Lite via its USB adapter, Pynt disconnected
   (`ucenter-config.md`) — config verified, adapter unplugged.
3. Bank + Pynt + Lite, **power wires only** (1 and 4): Lite power LED on,
   Pynt unaffected, run checks P2–P3.
4. Add data wires 2 and 3: NMEA visible in the Pynt's serial console.
5. Check P4 soak, then full-stack field-sim soak: NTRIP + logging +
   backlight 1 h; SD file grows; no resets.

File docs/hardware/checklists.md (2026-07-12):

# Per-Board Bring-Up Checklists

Work through these before any inter-board wiring. Sources cited so items
can be re-verified against current vendor docs.

## simpleRTK2B Lite (ZED-F9P) — moved from the RTK-Feather rig

- [ ] Physical inspection after de-rigging from the Feather stack: JST-GH
      connector intact, SMA snug, no bent XBee-header pins.
- [ ] JST **pin 1 marking** located (white square / printed "1"); pigtail
      pin-1 end tagged. Wire colors untrusted
      ([Pixhawk cable notes](https://www.ardusimple.com/product/pixhawk-cable-set/)).
- [ ] **Top XBee socket empty** and kept empty (UART2 = future radio;
      socket VCC is a 3.3 V output — never feed power in).
- [ ] HC977 antenna on SMA: hand-tight + ⅛ turn, sky view for fix tests.
      No ground plane needed (helical).
- [ ] u-center **re-verification** pass done (`ucenter-config.md`),
      config survives power cycle, adapter unplugged afterward.

## PyPortal Pynt

- [ ] Board boots on USB; CircuitPython or prior contents noted, then
      Arduino bootloader confirmed working (double-tap reset → PORTALBOOT
      drive). Record bootloader version (UF2 boot screen); update via
      Adafruit's bootloader-updater UF2 if older than the Arduino-core
      minimum.
- [ ] **Power measurements P1 + P2** (`power.md`): D3/D4 JST power-pin
      voltage recorded; I2C STEMMA port pin measures ~VBUS (5 V default
      jumper intact, [pinouts](https://learn.adafruit.com/adafruit-pyportal/pinouts)).
- [ ] TFT smoke test: fill screens, text at `setRotation(0)` and `(2)` —
      pick the portrait rotation whose "up" matches the planned cable
      exit; record it.
- [ ] Touch smoke test: raw X/Y ADC values at the four corners recorded
      (calibration constants for Phase 2).
- [ ] AirLift check: `WiFi.firmwareVersion()` ≥ NINA 1.7.7; hotspot join;
      TCP echo to a laptop on the hotspot network (proves the SW Maps
      path before SW Maps enters the picture).
- [ ] microSD: PNY Elite 32 GB formatted FAT32; SdFat init at
      `SD_CS` (pin 32); **card latency test** — 4 MB in 512 B appends,
      histogram of per-write latency, record worst case (feeds the
      `platform.md` buffer numbers with real data).
- [ ] **D3/D4 label-swap + UART loopback test** (`wiring.md`) — sockets
      tape-labeled from measurement, SERCOM0 recipe compiles and echoes.
- [ ] Free-RAM high-water mark printed by the bring-up sketch recorded.

## Integration gates (in order, from `power.md` smoke-test)

1. Pynt alone healthy (all items above).
2. Lite alone healthy on u-center.
3. Power-only union (wires 1+4) — checks P3/P4.
4. Data union (wires 2+3) — NMEA in the Pynt console at 115200.
5. 1 h full-stack soak: NTRIP + logging + backlight; no resets; SD grows.

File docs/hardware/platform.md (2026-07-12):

# Pynt Platform Notes — buses, contention, display, touch

## Bus map (who owns what)

| Bus | Peripherals | Notes |
|---|---|---|
| SERCOM0 UART (D3/D4) | ZED-F9P UART1 | ours; recipe in `wiring.md` |
| SERCOM2 SPI | **ESP32 AirLift + microSD** (separate CS) | the contention point — see below |
| SERCOM4 UART (`Serial1`/`SerialNina`) | ESP32 bootstrap/BLE serial | leave alone |
| SERCOM5 I2C (STEMMA) | ADT7410 temp sensor onboard; port unused by us (5 V pin doubles as the Lite's power source, `power.md` shape A) | free |
| 8-bit parallel (PA16–23 + ctrl) | ILI9341 TFT | dedicated — display traffic never touches SPI |
| Analog | resistive touch YD/XL/YU/XR = pins 17/18/19/20 | 4-wire, polled ADC |
| QSPI | 8 MB flash | available for config/assets if ever needed |

The TFT being on its own parallel bus is the Pynt's structural advantage:
UI refreshes cost CPU but zero SPI bandwidth.

## SPI contention analysis (AirLift × microSD)

Single superloop, one SPI transaction at a time — WiFiNINA socket reads
(NTRIP RTCM3 in, TCP NMEA out) and SdFat writes serialize naturally. The
risk is **latency, not corruption**: a slow SD write blocks NTRIP/TCP
servicing, and vice versa.

Budget, worst case:

- F9P UART1 output at 115200 ≈ 11.5 KB/s ceiling; actual RAWX + SFRBX +
  NMEA @ 1 Hz ≈ 1–2.5 KB/s in ~burst-per-epoch shape.
- The PNY Elite U1 card can stall a single write **100–250 ms**
  (class-U1 worst case; measured value comes from the Phase 1 card test).
- 250 ms stall at 11.5 KB/s ⇒ ≤ ~2.9 KB must buffer in the UART RX ring.

With 256 KB of RAM (vs. the Adalogger M0's 32 KB and ~6.7 KiB headroom),
we allocate a **32 KB UART RX ring buffer** (≈ 2.8 s at full line rate)
and a **32 KB SD staging buffer**, and the problem the Feather build had
to engineer around ceases to be tight. Two-stage buffering (UART ISR ring
→ staging → pre-allocated contiguous file, 512-byte aligned writes) is
still ported from Feather because it is the right shape, not because the
margins demand it.

NTRIP side of the same coin: RTCM3 in is ~0.5–1 KB/s; WiFiNINA's internal
socket buffer on the NINA side absorbs SD-write windows. Correction age
tolerance is seconds — a 250 ms hiccup is invisible.

## Display: ILI9341 over 8-bit parallel

- Bus: 8 data lines (Arduino 34–41 = PA16–23) + control (5–12, 24–26
  region; exact defines from
  [variant.cpp](https://github.com/adafruit/ArduinoCore-samd/blob/master/variants/pyportal_m4/variant.cpp)).
  SPI mode exists only via solder-jumper surgery — not planned.
- Driver: `Adafruit_ILI9341` has a parallel constructor
  (`tft8bitbus`, used by Adafruit's own PyPortal Arduino demos); fallback
  is `Adafruit_Arcada`, which knows the PyPortal variant wholesale.
  **Verify at first compile** — this is Q11's remaining tail.
- **Portrait 240×320** (owner decision, 2026-07-11): `setRotation(0)` or
  `setRotation(2)` — pick when cable-exit direction is known (enclosure
  comes after electronics). All UI layout targets 240 (w) × 320 (h).

## Touch: 4-wire resistive

- Pins: TOUCH_YD=17 (PB00), TOUCH_XL=18 (PB01), TOUCH_YU=19 (PA06),
  TOUCH_XR=20 (PB08) — plain ADC polling via `Adafruit_TouchScreen`.
- PA06 is also SERCOM0/PAD[2]; our UART uses only pads 0/1 — **no
  conflict** (noted so nobody "optimizes" the UART onto pads 2/3 later).
- Resistive + gloves = works (field-relevant); calibration constants and
  a debounce/hysteresis pass are Phase 2 UI work. Touch targets sized
  ≥ 48 px for field use.

## CPU/RAM budget sanity

120 MHz M4F, 256 KB RAM, 1 MB flash. Feather's HUZZAH32 rover build used
17 % RAM / 66 % flash on a 520 KB-RAM ESP32 doing strictly more radio
work (native WiFi stack in-MCU; ours lives on the NINA co-processor).
The Pynt adds the TFT framebuffer-less GFX path (no full framebuffer —
ILI9341 is drawn-through) and WiFiNINA's modest footprint. No red flags;
the Phase 1 bring-up sketch prints free-RAM high-water marks to confirm.

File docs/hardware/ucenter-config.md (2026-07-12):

# F9P Re-Verification Checklist (u-center over the Lite's USB adapter)

This Lite **moves over from the RTK-Feather rig** — it may already carry
the correct flash config. Re-verify rather than assume: run this checklist
as VALGET spot-checks first; only VALSET what differs.

**Bench rule (read first):** the Lite's XBee-to-USB adapter is an FTDI
bridge to **UART1** — the same port the Pynt uses. Do this with the
**JST-GH pigtail unplugged**. Never both. See `wiring.md`.

Setup: Lite on the XBee-to-USB adapter → classic u-center. Connection
baud: **115200 if the Feather-era config took; 38400 (F9P default) if the
board was ever factory-reset.** Use View → Generation 9 Configuration View
(VALSET/VALGET); apply to RAM, verify, then RAM+BBR+Flash.

## 1. Identity / firmware

- [ ] UBX-MON-VER: record FW version (want HPG 1.32+). Should match the
      Feather project log — if it doesn't, this is a different board.

## 2. UART1 port

| Key | ID | Value |
|---|---|---|
| `CFG-UART1-BAUDRATE` | `0x40520001` | **115200** |
| `CFG-UART1INPROT-UBX` | `0x10730001` | 1 (config/poll from the Pynt) |
| `CFG-UART1INPROT-NMEA` | `0x10730002` | 0 |
| `CFG-UART1INPROT-RTCM3X` | `0x10730004` | **1** (corrections in) |
| `CFG-UART1OUTPROT-UBX` | `0x10740001` | 1 |
| `CFG-UART1OUTPROT-NMEA` | `0x10740002` | 1 |
| `CFG-UART1OUTPROT-RTCM3X` | `0x10740004` | 0 (Rover; Base uses UART2) |

## 3. Raw-data messages on UART1 (for the Pynt's SD logger)

| Key | ID | Value |
|---|---|---|
| `CFG-MSGOUT-UBX_RXM_RAWX_UART1` | `0x209102a5` | 1 |
| `CFG-MSGOUT-UBX_RXM_SFRBX_UART1` | `0x20910232` | 1 |
| `CFG-MSGOUT-UBX_TIM_TM2_UART1` | (look up in Config View) | 1 — optional |

## 4. NMEA set on UART1 (SW Maps TCP + GGA-to-caster)

- [ ] GGA = 1, RMC = 1, GSA = 1, GST = 1 (accuracy figures for SW Maps)
- [ ] GSV = 1
- [ ] VTG = 0 unless wanted
- [ ] `CFG-NMEA-HIGHPREC` = 1 (7-digit lat/lon minutes)

## 5. Rates, dynamics, constellations

- [ ] `CFG-RATE-MEAS` = 1000 ms, `CFG-RATE-NAV` = 1 → 1 Hz.
- [ ] `CFG-NAVSPG-DYNMODEL`: 0 (portable) default.
- [ ] Elevation mask `CFG-NAVSPG-INFIL_MINELEV` = **12°** (inherited
      Metro answer).
- [ ] Constellations: GPS + GLO + GAL + BDS enabled; SBAS/QZSS off
      (inherited Metro answer) — spot-check `CFG-SIGNAL-*` group.

## 6. Ports we deliberately leave alone

- [ ] **UART2: do not disable, do not reconfigure** — Base mode will later
      configure RTCM3 output here (config only; socket stays empty).
- [ ] I2C/USB blocks: leave at defaults.

## 7. Save and verify

- [ ] Apply full set to Flash (RAM+BBR+Flash, Send).
- [ ] Power-cycle; reconnect at 115200; VALGET spot-check from the
      **Flash** layer (RAWX_UART1, BAUDRATE).
- [ ] Packet console: RAWX + SFRBX + NMEA set at 1 Hz, no other chatter.
- [ ] **Unplug the USB adapter before connecting the JST pigtail.**

## Recovery

Mis-configured into silence → USB adapter, UBX-CFG-CFG "Revert to default
configuration", then redo this checklist (reconnect at 38400 after reset).

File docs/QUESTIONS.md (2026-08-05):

# Open Questions

Status legend: ❓ needs owner answer · 📄 resolve from vendor docs in Phase 0 ·
✅ answered.

## Answered at kickoff (2026-07-11)

1. ✅ **Toolchain** — PlatformIO Arduino C++ (port Metro/Feather modules).
2. ✅ **v1 scope** — Rover + RAWX logging + Base mode, all in v1.
3. ⚠️ **Phone link** — SW Maps over WiFi TCP; BLE permanently out (AirLift
   can't do WiFi+BLE together). **Re-opened 2026-07-19 (see Q19): iOS
   SW Maps turns out to be Bluetooth-only — the TCP half of this answer
   doesn't exist on iPhone.** The firmware's TCP NMEA server stands; the
   phone app has to change.
4. ✅ **Repo** — public GitHub, `PyPortal-Pynt-RTK`.
5. ✅ **Touch UI depth** — status pages + touch controls; config stays on
   the USB serial menu (no on-screen keyboard in v1).
6. ✅ **Inherited defaults** — Metro's answers carry over wholesale: caster
   `acorn-gnss.net:2101` (mounts `VRS_SouthCentral_RTCM3`/`MS_RTCM3`),
   iPhone hotspot, 12° mask, GPS+GLO+GAL+BDS.

7. ✅ **Same Lite or second Lite?** — Answered 2026-07-11: the Lite +
   antenna **move over** from the RTK-Feather rig. F9P config largely
   carries over (UART1 @115200, constellations); re-verify with u-center
   before first bring-up rather than assuming flash contents.

## Open

8. 📄 **Power shape** — decision framework written
   (`docs/hardware/power.md`): shape A (single bank port, Lite fed 5 V
   from the Pynt's I2C STEMMA port) is preferred **pending bench
   measurements P1–P4**; shape B (two-feed) is the fallback. Closes when
   the measurements are recorded at bring-up.
9. 📄 **Pynt D3/D4 label swap** — forum reports say the Pynt's D3/D4
   sockets are silkscreened swapped vs. the classic PyPortal. Verify by
   loopback/scope during Phase 1 bring-up before wiring the Lite.
10. ✅ **D3/D4 SERCOM mapping in Arduino** — Resolved from
    [variant.cpp](https://github.com/adafruit/ArduinoCore-samd/blob/master/variants/pyportal_m4/variant.cpp)
    (2026-07-11): D3=PA04/D4=PA05, `PIO_SERCOM_ALT` → **SERCOM0 pads
    0/1**, which is free (`Serial1` = SERCOM4 → ESP32, SPI = SERCOM2,
    Wire = SERCOM5). Custom `Uart` recipe in `docs/hardware/wiring.md`;
    Phase 1 loopback is the ground-truth check.
11. ✅ **TFT driver in 8-bit parallel mode** — Resolved on paper
    (2026-07-11): data PA16–23 (pins 34–41) + control pins per variant;
    `Adafruit_ILI9341` `tft8bitbus` constructor (Adafruit's own PyPortal
    Arduino demos use it), `Adafruit_Arcada` as fallback. **Compiled clean
    2026-07-11** (Adafruit_ILI9341 1.6.3) — remaining tail is pixels on
    glass at bring-up.
12. 📄 **SPI contention budget** — Analysis written
    (`docs/hardware/platform.md`): 32 KB UART ring + 32 KB SD staging on
    the SAMD51's 256 KB makes the Feather's tight-margin problem roomy;
    closes when Phase 1 measures the real card's worst-case write latency
    with WiFi active.
13. ✅ **Cable stock** — Answered 2026-07-11: cabling will be on hand
    (JST-GH pigtail for the Lite, D3/D4-side leads). Exact connector
    inventory gets confirmed against the Phase 0 wiring diagram.
14. ✅ **microSD card** — Answered 2026-07-11 (photo): PNY Elite 32 GB
    microSDHC, UHS-I **U1** (≥10 MB/s sustained). Plenty of throughput for
    RAWX, but U1 cards can throw long single-write latency spikes — the
    Phase 1 slow-card burst test and the two-stage buffer sizing (Q12) are
    the guard.
15. ✅ **GNSS antenna** — Answered 2026-07-11 (photo): Calian/Tallysman
    **HC977 triple-band + L-band helical**, part 33-HC977-35 (35 dB LNA
    variant), s/n 20200624. Bias 2.2–16 VDC → fine on the F9P's 3.3 V
    antenna feed; ~21 mA typ; IP67; SMA. Helical → **no ground plane
    needed**. **Metrology recorded 2026-08-04** (closes review P6):
    ARP/phase-center offsets + enclosure stack in
    `docs/hardware/antenna-metrology.md` (ARP→L1 PC 138.3 mm,
    →L2/L5 143.3 mm, coaxial with the 5/8"-11 pole mount).
16. ✅ **Enclosure / assembly** — Answered 2026-07-11: enclosure gets
    built **after** the electronics work, and **portrait** is the optimal
    orientation → all touch-UI layout is designed for 240×320 portrait
    (`tft.setRotation()` — which of the two portrait rotations depends on
    cable exit, decided with the wiring diagram).
17. ✅ **RTK-Feather rig post-move** — Mooted by Q7: with the Lite and
    antenna moving over, the Feather rig loses its GNSS and is effectively
    retired as a complete rover (boards remain available as spares).
18. 📄 **Simultaneous WiFi + BLE on the AirLift** (owner question,
    2026-07-12). Arduino solved WiFi/BLE coexistence on NINA-W102 boards
    by moving BLE HCI onto the SPI link
    ([nina-fw 3.0.0 PR #111](https://github.com/arduino/nina-fw/pull/111);
    needs nina-fw 3.0.1 + WiFiNINA 2.0.0 + ArduinoBLE 2.0.0 —
    [CNX article](https://www.cnx-software.com/2026/03/06/wifi-and-bluetooth-le-can-now-be-used-simultaneously-on-arduino-boards-with-nina-w102-esp32-module/)).
    **Verified 2026-07-12: Adafruit's nina-fw fork (v3.3.0) has NOT
    adopted it** — its BLE HCI is still UART-only and mode-exclusive, and
    our host stack (Adafruit WiFiNINA fork for `setPins`) has no matching
    protocol. Decision: BLE stays out; the kickoff constraint stands.
    **Re-evaluate if** adafruit/nina-fw merges the HCI-over-SPI transport
    — the payoff scenario is the future UART2 radio (corrections by
    radio, phone by BLE, no hotspot). Note: the Pynt is not pin-blocked
    for a hybrid (ESP32 HCI UART is wired to SERCOM4 pins 0/1, separate
    from SPI) — the blocker is firmware, not wiring.
    **Update 2026-07-19 — scoped as Phase 5 (README)** rather than
    waiting on Adafruit: flash Arduino's nina-fw 3.x ourselves. The Pynt
    wires ESP32_GPIO0 (pin 6) + ESP32_RESETN (pin 7), so the documented
    AirLift passthrough-flash path works and the move is reversible.
    Three-part scope: nina-fw 3.x build/flash, host swap to Arduino
    WiFiNINA 2.0.0 (needs PyPortal pin defines — no setPins), ArduinoBLE
    2.0.0 SPI-transport patch + NUS peripheral for SW Maps. Became more
    attractive when Q19 found iOS SW Maps is BLE-only.
    **Update 2026-07-26 (branch `coex/nina-fw-airlift`):** stopped
    waiting for adafruit/nina-fw — arduino/nina-fw 3.0.1 is vendored
    with a one-pin AirLift patch (MOSI 12→14) in
    `firmware/nina-fw-airlift/`, host stack moves to upstream WiFiNINA
    2.1.1 + ArduinoBLE 2.1.0 (vendored, 2-line transport-gate patch) +
    Arduino_SpiNINA 0.0.2. De-risking on spare boards first
    (`docs/coex-bench.md`); the assembled Pynt keeps stock firmware and
    the `pynt-rover` env until Spikes A–C pass.
19. ✅ **iOS survey app for the TCP NMEA link** — **Answered 2026-07-19:
    QField connected to the Pynt's :10110 server and streamed NMEA on the
    first try** (it evidently transmits on connect, satisfying the
    data-gated accept below), so QField is the v1 phone app. SW Maps
    remains the Phase 5 payoff (BLE NUS). Original findings kept for the
    record:
    - **iOS SW Maps has no TCP/IP instrument support — Bluetooth LE
      only** (per SparkFun's RTK iOS guide). The kickoff Q3 answer
      assumed it; nobody had checked the iOS app. Apps that DO act as
      TCP clients to an NMEA server on iOS: **QField** (free),
      ArcGIS Survey123 / QuickCapture (Esri licensing).
    - **The AirLift's TCP accept is data-gated**: nina-fw does not
      surface a connected socket to `server.available()` until the
      client sends ≥1 byte (confirmed live: a silent client sat
      unaccepted for minutes; sending one test message accepted it
      instantly). A pure listen-only client may never be accepted, so
      whichever app is chosen must be tested for send-on-connect
      behavior. If the chosen app is listen-only too, fallback options:
      NMEA over **UDP broadcast** (no accept step at all; QField
      supports UDP), or documenting a "send anything once" step.
    Closes when an app is picked and verified streaming on the iPhone.
    **Root cause found 2026-07-27 (coex branch, from source):** the
    data-gating lives in the host library's `server.available()` path —
    `availServer(sock, accept=false)` makes nina-fw take its legacy
    data-gated branch on EVERY firmware, including 3.0.1. nina-fw 3.x
    adds a true-accept branch (`accept=1`), reached only via upstream
    WiFiNINA 2.x's new `server.accept()` API. Verified live on the
    HUZZAH32 soak rig: `available()` never surfaced a silent client;
    `accept()` surfaced it instantly. The coex rover build now uses
    `accept()` (gated in `tcp_nmea.cpp`); the shipping Adafruit-fork
    stack has no `accept()`, so QField's send-on-connect (or the UDP
    fallback) remains required there. Note: the Spike B bench note
    claiming silent accept worked was a misread — its test client
    pinged on connect.
    **CLOSED 2026-07-28 — both phone paths verified on the Pynt:**
    QField over TCP (2026-07-19, stock stack) and now **iOS SW Maps
    over BLE NUS** — owner connected SW Maps to `PyntRTK-rover` during
    the §7.5 coex soak (~58 min streaming, 37,628 sentences notified,
    clean reconnects; docs/coex-bench.md). The "Phase 5 payoff"
    originally deferred to the radio scenario arrived early via the
    coex firmware.
    **Bench corollary (2026-07-19):** u-center 25.06 can also join as a
    TCP network client (`tcp://<pynt-ip>:10110`) — but it connects
    silently, so the data-gated accept leaves it uncounted until it
    transmits once: poll any message (Messages View → UBX-MON-VER →
    Poll) and the stream starts. Note it is a **one-way NMEA monitor**
    there — the firmware discards inbound TCP bytes by design (network
    clients must not reconfigure the receiver), and the tee carries no
    UBX. If listen-only bench clients become routine, a UDP broadcast
    tee (no accept step) is the candidate Phase 4 polish item.
    **Update 2026-07-26 (Spike B):** the data-gated accept is a
    stock-Adafruit-1.7.x behavior — upstream nina-fw 3.0.1 accepted a
    silent client immediately (docs/coex-bench.md bench notes). If the
    Pynt moves to the coex stack (Q18/Phase 5), the workaround and the
    UDP-tee motivation largely evaporate; re-verify at section 7 step 2.

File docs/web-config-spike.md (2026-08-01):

# Web Config GUI — W0 spike + increment plan

Branch `web-config` (off `coex/nina-fw-airlift` — W5's BLE card needs
the coex stack). Locked decisions:

- **v1 scope = W0–W5** (Status, WiFi provisioning, GNSS, Corrections,
  BLE, Logging, System). W6 (mDNS, sourcetable browser, SD file
  manager, profiles) deferred.
- **AP provisioning entry: touch button only** (TFT WEB page → AP
  button). Never an automatic fallback.
- **Admin auth ON by default.** No hardcoded default passwords: the
  admin password and the AP WPA2 key are **generated on-device (SAMD51
  TRNG) at first web boot** and displayed on the TFT WEB page (PAGE
  button cycles POS → SYS → WEB). User "admin". Changeable from the
  web System card (W5); `adminpass=` / `appass=` in /config.txt.
- **STA web server always-on while surveying**, port **80**. Compile
  flag `ENABLE_WEB_CONFIG` (only `pynt-rover-coex` sets it) exists as
  the gate if the §7.5 concurrency soak ever demands it.
- Web GUI supersedes the previously-planned on-screen-keyboard touch
  work (descoped). The touch UI adds only: the WEB info page, and the
  AP-mode button.

Increment status:

| Increment | State |
|---|---|
| W0 spike | **sketch + this doc ready — needs the bench pass below** |
| W1 status dashboard | implemented (`web_config.cpp`, `tools/webui/`) |
| W2 WiFi provisioning + AP flow | **DONE — full round trip verified on the Pynt 2026-07-31** |
| W3 GNSS + Corrections cards | **DONE — benched on the Pynt 2026-07-31** |
| W4 Logging card | **DONE — benched on the Pynt 2026-07-31** |
| W5 BLE + System cards | **DONE — benched on the Pynt 2026-07-31** |

## W0 bench (Metro M4 AirLift, custom nina-fw already flashed)

```
pio run -e metro-spike-web -t upload && pio device monitor -b 115200
```

Menu: `1` STA+HTTP · `2` AP+HTTP · `b` BLE toggle · `h` hostname · `s` status.
Needs `firmware/spike/secrets.h` and the hotspot up. Record everything
in the results table at the bottom.

### W0.1 — HTTP serve + gzip-from-PROGMEM (browsers)

`1`, then from a phone browser: `http://<ip>/`.

- [ ] **iOS Safari** renders the dashboard page (tabs visible; footer
      says "connection lost — retrying…" — expected, `/api/status`
      only exists on the rover) → gzip + Content-Length path works
- [ ] **Android Chrome** same
- [ ] `curl -sv http://<ip>/ -o page.html` shows
      `Content-Encoding: gzip` and the file gunzips to the page

### W0.2 — accept behavior for HTTP

The spike uses `server.accept()` (the data-gated `available()` trap is
already proven — coex-bench notes 2026-07-27). Verify HTTP is happy:

- [ ] `nc <ip> 80` then wait 5 s, then type `GET / HTTP/1.1` + Enter
      twice — connection is accepted immediately (server responds after
      the request arrives; no data-gating stall)

### W0.3 — concurrent sockets

From a laptop: `curl -s http://<ip>/api/ping & curl -s http://<ip>/api/ping & curl -s http://<ip>/api/ping & wait`

- [ ] All three return JSON (serialized one-at-a-time is fine — no
      hangs, no connection-refused). Record how many parallel curls
      start failing (nina-fw socket budget; expect ~4-8 usable).
      **This bounds the W1 single-connection design's safety margin.**

### W0.4 — throughput

`curl -so /dev/null -w "%{speed_download}\n" http://<ip>/big` ×5.

- [ ] ≥ 20 KB/s sustained, no stalls/resets (the serial log prints the
      device-side ms for each). Record best/worst. 16 KiB is ~3× the
      whole real UI, so 20 KB/s ⇒ page interactive in ~1 s.

### W0.5 — AP mode on the custom firmware  ← W2 design gate

`2`. Expect `beginAP -> 7` (WL_AP_LISTENING).

- [ ] Phone sees WPA2 network **PyntRTK-setup** (pass `pynt-spike-99`),
      joins, browser loads `http://192.168.4.1/`
- [ ] Record the AP-mode IP the serial prints (expect 192.168.4.1)

### W0.6 — AP + BLE coexistence  ← W2 design gate

Still in AP mode: `b`.

- [ ] Record whether `BLE.begin()` succeeds and the phone (nRF Connect)
      sees **PyntRTK-web-spike** while the AP is up and serving HTTP
- [ ] Also run the STA variant: `1` then `b` (should match Spike B —
      expected PASS)
- Either W0.6 outcome is workable: PASS ⇒ W2 keeps BLE alive in AP
  mode; FAIL ⇒ W2 stops BLE NUS while provisioning (it's a minutes-long
  on-demand mode, entered by button — acceptable). **W2 is not designed
  until this answer is recorded.**

### W0.7 — setHostname

`h`, then `1` to rejoin, then check the router/hotspot's client list.

- [ ] Device appears as `pynt-w0-spike` (or record that the hotspot
      ignores DHCP option 12 — some phone hotspots do; then hostname is
      cosmetic-only and mDNS stays a W6 topic)

## W1 design (implemented this increment)

`firmware/pynt/rover/web_config.{h,cpp}`, eighth superloop module,
polled LAST (lowest-priority residual). Hand-rolled HTTP/1.1 state
machine: `server.accept()` → read request line + headers (bounded 512 B
per pass, 2 s deadline) → route → stream response (≤1 KiB per pass,
`Connection: close`, 8 s deadline) → next connection. One connection at
a time by design; W0.3 tells us how gracefully extras queue.

Routes: `GET /` (gzipped SPA, PROGMEM via
`tools/webui/build_assets.py` → `web_assets.h`, gitignored generated
file), `GET /api/status` (~450 B JSON snapshot of
g_gnss/g_link/g_log + uptime/mode). Everything else: 501 JSON stubs
(`/api/wifi|scan|gnss|ntrip|ble|log|system`) so the surface is visible.
HTTP Basic auth on every route.

New /config.txt keys (existing vocabulary/style, all gated so the
shipping build is byte-identical): `webenable webport hostname
adminpass appass measrate dynmodel nmeagsv` (+ coex-only `bleenable
blename`). Pre-existing keys reused as-is: `wifi1..4`/`pass1..4`
(the plan's wifi2/3 already existed), `ggaperiod` (= the plan's
gga_upload_s), `logubx` (= log_auto), `caster port mount user password
tcpport mode svindur svinacc fixedlat/lon/alt elevmask`.
**Persistence is SD `/config.txt` + optional secrets.h seed — there is
no NVS on this platform** (plan assumption corrected).

## Results (bench run 2026-07-28, Metro/COM8, scripted driver)

| Test | Result | Notes |
|---|---|---|
| W0.1 gzip serve | **PASS** (curl + iOS Safari) | `Content-Encoding: gzip`, 2197 B wire → 5719 B page; owner confirmed the dashboard renders in iOS Safari over the AP. Android: no device on hand — deferred (iOS is the target platform), re-check opportunistically |
| W0.2 accept | **PASS** | 5 s silent connect → request → 200 OK |
| W0.3 parallel curls | **FAIL in spike form** — 0/3, 0/6 | Sequential is solid; simultaneous connects all die against the spike's blocking one-at-a-time handler. Re-characterize against the rover's non-blocking module before drawing design conclusions; the SPA's 1 Hz retry masks transient failures either way |
| W0.4 /big throughput | **PASS** — 57.8–71.2 KB/s | 3× the 20 KB/s bar; whole UI (2.2 KB) ≪ 1 s |
| W0.5 beginAP | **PASS** — code 7 (WL_AP_LISTENING), IP 192.168.4.1 | Owner joined PyntRTK-setup (WPA2) from the iPhone and loaded the page at 192.168.4.1 |
| W0.6 AP+BLE | **PASS (both sides)** — `BLE.begin()` OK + advertising while AP up and serving; owner's nRF Connect saw AND connected to PyntRTK-web-spike while joined to the AP | **W2 unblocked: BLE need not stop during provisioning.** (nRF shows no data stream — correct: the spike advertises a bare peripheral, no NUS service; BLE data was proven on the rover during the §7.5 soak) |
| W0.7 hostname | **BLOCKED** by the `WiFi.end()` finding below | `setHostname()` accepted; rejoin never completed so no DHCP lease to inspect |

### Critical finding — `WiFi.end()` wedges STA rejoin

Two clean experiments, same session:

1. Unconditional `WiFi.end()` before the *first* `begin()` → **every
   join fails** (5/5). Guarding it (`if (netMode) WiFi.end()`) → first
   join succeeds instantly.
2. After a legitimate `end()` (mode switch path) → STA rejoin fails
   **5/5 again**, while `beginAP()` still works (code 7) and BLE is
   unaffected. So on nina-fw 3.0.1 + upstream WiFiNINA 2.1.1,
   **`WiFi.end()` permanently wedges STA-join until module reset**;
   AP bring-up survives.

Consequences:

- The **rover is unaffected** — ntrip.cpp never calls `WiFi.end()`
  (its retry loop just calls `begin()` again).
- **W2's AP↔STA transition must not use `WiFi.end()`.** Design options
  to test: `beginAP()` directly after STA (no end — worked in this
  session's sequence), and STA-after-AP via module reset (drive
  RESETN / SpiDrv re-init) as the exit path from provisioning. A
  reboot-into-STA after saving credentials is also acceptable UX for
  an on-demand provisioning mode and may be the simplest correct
  answer.
- W0.7 retest rides on whichever transition design wins.

## W2 bench — 2026-07-31, on the Pynt (pynt-rover-coex)

Full stack live during all of this: NTRIP connected, 3D fix ~25 SV,
RAWX logging, BLE advertising.

| Check | Result |
|---|---|
| Auth | **PASS** — 401 bare, 200 with creds (per-request recompute verified via serial `adminpass=` override) |
| GET / + /api/status | **PASS** — gzipped SPA + live JSON (all fields incl. ssid/ap) |
| **W0.3 re-test: parallel connects** | **RESOLVED — PASS**: 3/3 and 6/6 parallel requests return 200 against the non-blocking module; the spike's 0/3 was its blocking handler, not the firmware |
| POST /api/wifi | **PASS** — slot 4 saved to SD, listed, cleared |
| GET /api/scan in STA | **FINDING**: `scanNetworks()` during an active association DROPS the STA link (self-heals via the ntrip retry loop in ~30–60 s). Now gated: 409 in STA, allowed in AP mode; SPA surfaces the message. Verified 409 + association intact after the fix |
| W0.7 hostname | `setHostname("pynt-rtk")` applied before join — **owner: check the router's DHCP client table** |
| Boot | Clean with triage markers; hardened TRNG (bounded wait) — first-boot hang did not reproduce |

Flash-recovery note for this Pynt (bootloader quirk, worth knowing):
its UF2 bootloader goes bulk-transfer-dead when left IDLE in bootloader
mode (SAM-BA silent, MSC mounts but reads/writes hang — two different
copy tools, fresh double-taps, known-good cable all failed). The
reliable flash path is the **touch-flow**: boot the app (single reset
if needed), then `pio run -e pynt-rover-coex -t upload --upload-port
<app COM>` — PIO's 1200-touch + immediate bossac write works every
time (~12 s). Avoid parking this board in its bootloader.

Remaining W2 items (owner, phone in hand):
- TFT: PAGE → WEB page shows IP/HOST/ADMN/APSS/APPW; AP button enters
  provisioning (BLE stays up); join `pynt-rtk-setup` with the APPW
  key, browse http://192.168.4.1/, WiFi tab: scan (allowed there),
  save a network, then AP button again = exit + reboot to STA.
- Router DHCP table shows `pynt-rtk` (W0.7 close-out).
- Note: admin password currently overridden to a bench value; clear
  `adminpass=` in /config.txt (or wait for the W5 System card) to
  regenerate a TRNG one.

## W2 AP-flow bench — 2026-07-31, on the Pynt (three sessions, two findings)

**Final design: BOTH AP transitions are reboots.** The TFT AP button
saves a one-shot `bootap=1` to /config.txt and resets; at the next boot
`webConfigInit` clears the flag (crash/power-pull lands in STA), runs
the pre-AP scan (below), then `beginAP()` on the freshly reset module.
Exit = plain reboot. Entry/exit each cost a boot (~2 min with the SD
free-scan) — acceptable for an on-demand provisioning mode.

Two findings forced this design:

1. **The NINA's socket table does not survive `WiFi.end()`.** Switching
   STA→AP live left `WiFiServer::begin()` with no socket (`getSocket`
   starved by the STA session's leaked server/client socks):
   `srvStatus=0` (CLOSED) and `accept()` then returns phantom clients
   (~100/s flood, 38k–49k observed) — nina-fw's `availDataTcp` indexes
   its socket arrays with the host's stale sock number, out of bounds.
   Pre-stopping the server didn't help; only a module reset empties the
   table reliably. (Also seen: `WiFi.status()` leaking STA events —
   `WL_CONNECTION_LOST`, `WL_SCAN_COMPLETED` — while the AP runs, so
   AP-mode serving now ignores the status register entirely.)
2. **`scanNetworks()` kills whatever network is live — both modes.**
   STA: drops the association (recovers via the retry loop). AP: stops
   the AP beaconing permanently (`st` stuck at WL_SCAN_COMPLETED; the
   phone sees the network vanish; owner hit exactly this). The ONLY
   safe window is the AP-entry boot before `beginAP()` — radio idle.
   `/api/scan` now serves a cache filled in that window (12 entries,
   SSID/RSSI/enc); no live scan path exists anymore, in any mode.

**Round-trip verification (owner + wire log):** STA boot → AP button →
reboot → pre-AP scan cached 4 networks → `pynt-rtk-setup` up,
`srvStatus=1` (LISTEN) → phone joined (WPA2 key from TFT), Basic-auth
login, dashboard live over the AP (63 clean accepts ≈ the SPA's 1 Hz
poll) → Scan button returned the cached list instantly → saved the
owner's hotspot to slot 2 (`[web] wifi slot 2 updated`, persisted —
visible in /config.txt and /api/wifi after reboot) → AP button →
reboot → STA rejoined, NTRIP reconnected, GUI reachable at the STA IP.

W2 residuals: W0.7 hostname check (router DHCP table, owner);
Android-browser render (no device on hand); `WEB_AP_DEBUG` triage
prints remain in web_config.cpp behind their flag (off) for future
benches.

## W3 bench — 2026-07-31, on the Pynt

GNSS card: GET/POST `/api/gnss` (measrate 1/2/5 Hz, dynmodel
0/2/3/4/5/6, elevmask 0–45, GSV toggle) — POST persists to SD and
re-applies the full VALSET via the existing gnssRequestModeApply()
path; verified live (2 Hz/pedestrian/15°/GSV-off applied and read
back, then restored to project defaults). gnss_config now consumes
measRateHz/dynModel/nmeaGsv under ENABLE_WEB_CONFIG (shipping build
keeps the fixed 1 Hz/GSV-5 constants, byte-identical).

Corrections card: GET/POST `/api/ntrip` (caster/port/mount/user, blank
password = unchanged and never echoed, GGA period) — POST persists and
calls the new ntripRequestReconnect() (gated): drop socket, retry at
1 s. Verified live: reconnected to the caster with RTCM flowing within
8 s of the POST.

## W4+W5 bench — 2026-07-31, on the Pynt — v1 scope (W0–W5) COMPLETE

- **W4 `/api/log`**: GET live state (file/size/free/buffer high-water);
  POST toggles via the same sdLoggerSetEnabled path as the LOG touch
  button and persists `logubx` as the boot default. Verified: stop
  closed the file, start reopened logging.
- **W5 `/api/ble`**: GET state + linesTx/drops; POST saves
  bleenable/blename (applies at restart — no clean ArduinoBLE re-init
  on this transport). ble_nus now consumes both settings.
- **W5 `/api/system`**: GET hostname/port/uptime/build/AP-SSID; POST
  hostname (re-derives the AP SSID + setHostname live), admin password,
  AP password (min 8), and `regen=1` (TRNG both, read off the TFT).
  **Live password change verified: old creds 401 / new creds 200 on
  the very next request** — the per-request auth recompute at work.
  Browser re-prompts, as the card warns.

The web GUI v1 is feature-complete: status, WiFi provisioning with the
reboot-AP flow, GNSS tuning, caster management, logging control, and
system identity/access — all from a phone. W6 (mDNS, sourcetable
browser, SD file manager, profiles) remains deferred. Residuals: W0.7
router-DHCP hostname check (owner), Android render check, bench admin
password still set (regen from the System card when done benching).

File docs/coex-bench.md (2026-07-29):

# WiFi + BLE Coexistence Bench

Working doc for branch `coex/nina-fw-airlift`. Goal: prove simultaneous
WiFi + BLE on AirLift hardware with custom module firmware, de-risked on
spare boards before the assembled Pynt. Companion to
`firmware/nina-fw-airlift/AIRLIFT.md` (module firmware) and the
`VENDORED.md` notes in `lib/`.

> **STATUS 2026-07-27.** Spikes A and B **PASSED** on the Metro
> (sections 4–5, bench notes below). Spike C (Feather Wing soak) is
> **SUPERSEDED** by owner decision — see section 6 — and its
> SD-contention question folds into the Pynt integration soak. The
> Pynt may now be flashed, **only** via the section 7 sequence:
> backup first, rollback per section 8. The shipping `pynt-rover` env
> was never modified and remains the instant fallback.

Order of operations:

1. ~~Build the module firmware (section 2)~~ — **done 2026-07-26**.
2. ~~Metro M4 AirLift Lite: backup, flash, Spike A, Spike B~~ —
   **done 2026-07-26, all gates green**.
3. Pynt integration (section 7): backup → flash → `pynt-rover-coex`
   re-verification → BLE NUS module → combined integration soak.
4. Rollback at any point: section 8.

## 1. Pinned version set

| Piece | Version | Where |
|---|---|---|
| Module firmware | arduino/nina-fw **3.0.1** (`57d12f4`) + MOSI 12→14 | vendored `firmware/nina-fw-airlift/` |
| ESP-IDF (builds it) | **v4.4.8**, installed in WSL2 Ubuntu-22.04 at `/opt/esp-idf-v4.4.8` (Docker `espressif/idf:v4.4.8` equivalent) | this machine / AIRLIFT.md |
| WiFiNINA (host) | **2.1.1** (`272159c`) | `platformio.ini` git-tag pin |
| ArduinoBLE (host) | **2.1.0** (`281377b`) + 2-line gate patch | vendored `lib/ArduinoBLE/` |
| Arduino_SpiNINA (host) | **0.0.2** (`200cc35`), unpatched | vendored `lib/Arduino_SpiNINA/` |
| Adafruit SAMD core | **1.7.16** (PIO `framework-arduino-samd-adafruit 1.10716.0`) | pinned by platform `atmelsam` |
| esptool | **5.3.1** (dash-form commands: `read-flash`, `write-flash`); on the bench machine it lives in a scratch venv, driven via `flash_via_bridge.py` | laptop |

Rollback binaries: per-board `esptool read-flash` dumps (primary) and
stock `NINA_W102-1.7.x.bin` from
<https://github.com/adafruit/nina-fw/releases> (secondary).

## 2. Build the module firmware (no hardware needed)

**Done 2026-07-26** on this machine via WSL2 Ubuntu-22.04 + ESP-IDF
v4.4.8 (setup + exact commands: `firmware/nina-fw-airlift/AIRLIFT.md`).
Output already sits at
`firmware/nina-fw-airlift/NINA_W102-3.0.1-airlift.bin` — exactly
2,097,152 bytes, `0xE9` image magic at 0x1000 and 0x30000, "3.0.1"
version string embedded, committed on the branch. One image for all
boards, flashed at offset 0x0.

To rebuild from scratch: WSL path in AIRLIFT.md (verified), or Docker
`espressif/idf:v4.4.8` (equivalent, untested here). Either way the
flashable file is combine.py's **`_ALL.bin`** output.

## 3. Flashing procedure (any board)

The ESP32's serial bootloader is mask ROM — an interrupted or bad flash
is **always** recoverable by redoing this section. Reflash-risk, not
brick-risk.

1. `pio run -e passthrough-<board> -t upload` — the sketch straps the
   ESP32 into its ROM loader (GPIO0 low through a reset pulse) and
   bridges USB↔NINA UART at a fixed 115200.
2. Note the board's COM port (Device Manager, or `pio device list`).
3. **Backup first** (~3 min at 115200), then write. On Windows the stock
   esptool CLI does NOT work through the SAMD bridge — esptool forces
   DTR/RTS low and the CDC core then drops device→host bytes, and
   compressed writes die mid-stream (bench notes, 2026-07-26). Use the
   wrapper, from `firmware/nina-fw-airlift/`:

   ```bash
   python flash_via_bridge.py COMx read-flash 0 0x200000 <board>-stock-backup.bin
   ```

   ```bash
   python flash_via_bridge.py COMx write-flash --no-compress 0 NINA_W102-3.0.1-airlift.bin
   ```

   (On a non-Windows host the plain CLI form with
   `--before no_reset --after no_reset --baud 115200` may work as-is;
   the wrapper is always safe.)

4. After flashing, upload the next firmware env — its own boot resets
   the module into the new NINA firmware.

Per-board passthrough envs: `passthrough-metro`, `passthrough-feather`
(Wing pins via build flags), `passthrough-pynt` (used by the section 7
sequence).

## 4. Spike A — upstream WiFi stack alone (Metro) — PASSED

Prereqs: custom firmware flashed (section 3);
`firmware/spike/secrets.h` created from `secrets.example.h`; hotspot up.

```
pio run -e metro-spike-wifi -t upload && pio device monitor -b 115200
```

Pass gates — all four, else stop and debug before any BLE work:

- [x] No `AirLift not responding` (SPI link alive through the new firmware
      → the MOSI 12→14 patch is right)
- [x] `NINA firmware: 3.0.1` (stock would say 1.7.x)
- [x] Scan lists the hotspot SSID
- [x] Join succeeds; IP + RSSI keep printing at 5 s cadence, no drops
      while parked next to the phone

**All four passed 2026-07-26** — see bench notes below.

## 5. Spike B — WiFi + BLE simultaneously (Metro) — PASSED

```
pio run -e metro-spike-coex -t upload && pio device monitor -b 115200
```

Then, at the same time:

- Laptop on the hotspot: `nc <metro-ip> 10110` (or PuTTY raw) — expect
  the 1 Hz `COEX up=...` line; typed bytes echo back.
- Phone: nRF Connect / LightBlue → connect to **PyntRTK-coex** →
  subscribe to characteristic `6E400003-...` (NUS TX) — expect the same
  1 Hz line as notifications.

Pass gates:

- [x] TCP stream and BLE notifications run **concurrently** ≥ 15 min
- [x] `up=` counter never restarts (no watchdog/brownout resets)
- [x] `drops=0`, or any WiFi drop re-joins by itself
- [x] BLE disconnect/reconnect mid-run doesn't disturb the TCP side
- [x] Serial line stays clean (no SPI timeout spew)

**All five passed 2026-07-26** — see bench notes below.

## 6. Spike C — SUPERSEDED (folded into the section 7 soak)

**Owner decision 2026-07-27: not run standalone.** No SD breakout on
hand and no soldering the Wing's GPIO0 jumper; the shared-SPI
contention check moves into the Pynt integration soak (section 7.5).

Why this is acceptable risk rather than a skipped gate:

- **SD + AirLift WiFi contention on the Pynt is already proven** on the
  stock stack: the 1-hour Phase 2/3 rover soak passed with RAWX logging
  + NTRIP + TCP live (convbin RINEX verification, zero gaps), and the
  SPI-contention timing is documented in `docs/hardware/platform.md`
  and the bringup log (93.6 ms worst write, WiFi-only).
- **What coex adds is only BLE HCI multiplexed onto the same SPI
  command channel** — and exactly that multiplexing ran clean for
  34 minutes on real AirLift hardware in Spike B (zero SPI errors,
  zero resets). The Feather rig would have re-proven the combination
  on *different* silicon than the target; the Pynt soak proves it on
  the actual unit.
- **The Pynt is reflash-recoverable, not brickable** (mask-ROM
  bootloader, section 3), and the section 7 sequence takes a full
  stock-firmware backup before writing anything, with the section 8
  rollback returning to the known-good `pynt-rover` state in minutes.

The original standalone procedure is preserved in **Appendix A.1** for
anyone who later has the Wing on the bench and a soldering iron for its
GPIO0 jumper. The `feather-soak-coex` and `passthrough-feather` envs
remain in `platformio.ini` and compiling.

**Update 2026-07-27 — optional no-soldering path:** Spike C is
runnable after all, with a hand-wired **HUZZAH32** standing in for the
Wing (same ESP32 silicon family, same `NINA_W102-3.0.1-airlift.bin`,
flashed trivially over the HUZZAH32's own USB). Procedure, wiring
table, and a **do-NOT-stack** warning: **Appendix A.2**, env
`feather-soak-coex-huzzah`.

**Update 2 (same day): RUN AND PASSED** — 72-minute soak on the A.2
rig, all gates green (bench note below). Spike C is no longer a gap;
the section 7.5 integration soak now re-proves the same combination on
the target unit rather than proving it first.

## 7. Pynt integration (unlocked 2026-07-27)

Run the steps in order; stop at any failure and consult section 8.

### 7.1 Back up the Pynt's stock NINA firmware

```
pio run -e passthrough-pynt -t upload
```

then, from `firmware/nina-fw-airlift/` (note the Pynt's COM port; the
wrapper is required on Windows — see section 3):

```bash
python flash_via_bridge.py COMx read-flash 0 0x200000 pynt-stock-backup.bin
```

Sanity-check the dump before proceeding: 2,097,152 bytes, `0xE9` at
offset 0x1000. **Keep this file safe** — it is the primary rollback
(gitignored; park a copy off-machine).

### 7.2 Flash the custom firmware

```bash
python flash_via_bridge.py COMx write-flash --no-compress 0 NINA_W102-3.0.1-airlift.bin
```

Wait for `Hash of data verified` (~3 min uncompressed).

### 7.3 Switch to the coex env and re-verify WiFi-only behavior

```
pio run -e pynt-rover-coex -t upload
```

`pynt-rover-coex` builds the same rover source against the upstream
stack — WiFiNINA 2.1.1 + patched ArduinoBLE 2.1.0 + vendored
Arduino_SpiNINA, selected by `-DCOEX_UPSTREAM_NINA` (compiles out the
Adafruit-fork `WiFi.setPins()`; pins come from the pyportal_m4 variant
macros) and `-DBLE_NINA_SPI_TRANSPORT` (enables ArduinoBLE's SPI-HCI
transport). The shipping `pynt-rover` env is untouched.

Short attended bench (not the soak yet) — re-verify the behaviors that
were characterized against the Adafruit 1.x fork:

- [x] Boot clean: F9P detected, SD up, WiFi joins, NTRIP connects,
      RTK fix arrives, display sane
- [ ] `WiFi.begin()` stall window: RAWX timeline across a forced
      rejoin (hotspot off/on) shows only the bounded gap the 4096-byte
      SERCOM ring was sized for
- [x] **Silent-TCP-client accept — RESOLVED from source 2026-07-27,
      verify on the Pynt:** `server.available()` is data-gated on every
      nina-fw (the gate lives in the host's `availServer(accept=false)`
      call); upstream's new `server.accept()` API takes nina-fw 3.x's
      true-accept path. `tcp_nmea.cpp` now uses `accept()` under
      `COEX_UPSTREAM_NINA` (verified live on the soak rig). Bench
      check: a listen-only client (u-center / `nc` without typing)
      connects to :10110 and streams immediately. Details in Q19.
- [x] Serial `status` healthy: worst-loop time and free RAM in line
      with the stock-stack numbers

### 7.4 Add the BLE NUS rover module — WRITTEN 2026-07-27, needs bench

Implemented as `firmware/pynt/rover/ble_nus.{h,cpp}` — the seventh
polled superloop module, `FEATURE_BLE`-gated (default 0; only
`pynt-rover-coex` sets `-DFEATURE_BLE=1`). Spike B's proven service,
verbatim where it matters: same NUS UUIDs, one-sentence-per-notification
framing (120-byte characteristic, sentences never split), advertising as
**PyntRTK-rover**. NMEA reaches it through a tee in `tcp_nmea.cpp`'s
existing drain — BLE runs ALONGSIDE the TCP server (QField on TCP, iOS
SW Maps on BLE), including when WiFi is down (the future radio
scenario). Discipline: the tee only queues into an 8-line drop-oldest
ring; all SPI work happens in `bleNusPoll()` after gnss/ntrip/tcp, max
3 notifications per pass, zero bus traffic with no subscriber;
`BLE.begin()` failure degrades to WiFi-only with a log line. Status
surfaces as the POS page's ninth line (`BLE off/advert/conn/stream`)
and in the serial `status` report (state + linesTx + drops).

Verified compiling: `pynt-rover` byte-identical footprint
(140184 B RAM / 120044 B flash, unchanged); `pynt-rover-coex`
142868 B RAM (54.5 %) / 149772 B flash (+~2.7 KB / +~29 KB for
ArduinoBLE + module).

Bench items for this module (fold into 7.3/7.5):

- [ ] `BLE.begin()` succeeds after `ntripInit()` on the Pynt (Spike B
      proved the ordering on the Metro; confirm on this unit)
- [ ] iOS SW Maps discovers **PyntRTK-rover**, connects as a BLE GNSS
      instrument, and gets a position — the actual Q19 payoff
- [ ] Full NMEA set at 1 Hz (~8–12 sentences/epoch) drains within the
      3-per-pass cap with `bleDrops` staying ~0 while subscribed (the
      loop runs kHz-fast, so an epoch's burst should clear in
      milliseconds — verify, don't assume)
- [ ] Worst-loop time with a subscriber attached stays in line with the
      stock numbers (each notify is one bounded SPI command)

### 7.5 Integration soak — the combined gate (replaces Spike C)

Everything at once, ≥ 1 hour: **SD RAWX logging** (rover cadence:
bounded 512 B writes per loop pass, 8 s sync) + **NTRIP corrections
over WiFi** (live caster, RTK fix held) + **TCP NMEA** (QField or a
logging `nc` client) + **BLE NUS to a phone** (SW Maps on iOS if it
accepts the stream, else nRF Connect logging NUS TX).

Pass metrics — all of them, measured, recorded in the bench notes:

- [x] **≥ 60 min**, uptime monotonic — zero watchdog/brownout resets
- [ ] **SD integrity:** post-soak, the `.ubx` parses clean in u-center
      / RTKLIB `convbin` (every UBX frame checksum-valid — this is the
      CRC check on every payload) with **zero epoch gaps** outside
      documented WiFi-rejoin windows; file size consistent with the
      logged duration
- [x] **NTRIP:** zero correction-stale teardowns while the hotspot is
      up; any genuine hotspot handoff recovers unaided; correction age
      < 10 s steady-state; RTK fix (or float, per sky view) held
- [x] **TCP:** client stays connected the full soak, zero dropped
      connections; silent-accept behavior as verified in 7.3
- [x] **BLE:** stays connected/subscribed throughout (operator-initiated
      bounces allowed, must reconnect and must not perturb TCP/NTRIP —
      the Spike B gate, now under load); notify latency bounded — 1 Hz
      NMEA lines arrive within ~2 s, no multi-second stalls
- [ ] **Memory/loop stability:** free RAM flat across the hour (no
      monotonic decline = no leak) and worst-loop time bounded, both
      via the serial `status` report at start / mid / end
- [ ] **Worst SD write latency recorded:** `______ ms` (WiFi-only
      baseline was 93.6 ms; expect the same order with BLE HCI added
      to the bus)

All green ⇒ the coexistence stack is proven on the target unit; Phase 5
(SW Maps polish, UART2 radio scenario) proceeds on this branch. Any
red ⇒ section 8, analyze from the logs, re-approach.

## 8. Rollback (any time, in minutes)

The two halves are independent — module firmware and host env — and
both revert cleanly; the shipping env was never modified on this
branch.

1. **Module firmware back to stock:** `pio run -e passthrough-pynt -t
   upload`, then from `firmware/nina-fw-airlift/`:

   ```bash
   python flash_via_bridge.py COMx write-flash --no-compress 0 pynt-stock-backup.bin
   ```

   (No backup at hand? Secondary: the stock `NINA_W102-1.7.x.bin` from
   <https://github.com/adafruit/nina-fw/releases>, same command.)

2. **Host back to the shipping stack:**

   ```
   pio run -e pynt-rover -t upload
   ```

   `pynt-rover` still builds against the pinned Adafruit WiFiNINA fork
   exactly as it passed the Phase 2/3 soak — byte-identical env, never
   touched by the coex work.

That pair restores the unit to its last known-good field state.

## Bench notes / results

(append dated notes here as sections close, bringup-log style)

### 2026-07-28 — Section 7 run: Pynt flashed, §7.3 green, §7.5 soak PASS

**7.1/7.2.** Stock backup `pynt-stock-backup.bin` taken via
`passthrough-pynt` + `flash_via_bridge.py` (2,097,152 B, 0xE9 @0x1000;
embedded version string shows the Pynt shipped with Adafruit nina-fw
**1.6.1** — the bringup-log blank, finally filled). Custom
`NINA_W102-3.0.1-airlift.bin` written `--no-compress`, hash verified.

**7.3.** `pynt-rover-coex` boot: SD ok, F9P detected, WiFi joined,
TCP bound, **BLE advertising as PyntRTK-rover**, RAWX logging.
Silent-TCP-accept: **PASS on target** — pure listener received 106
NMEA sentences in 10 s without sending a byte (`server.accept()`
path). Two operational notes: the Pynt's SD had **no /config.txt**
(credentials re-entered via serial menu, persisted), and first boot
stalls ~20 s in the 32 GB card's free-space scan before the loop
starts — benign, don't mistake it for a hang.

**7.5 integration soak — 75 min, RAWX + NTRIP + TCP + BLE NUS all
concurrent:**

- **NTRIP:** connected once, **zero reconnects/teardowns** the whole
  run; corrections applied continuously (GGA quality field: 994 s
  DGPS → 3,506 s **FLOAT**; RTK-fixed not reached — bench antenna sky
  view, gate wording "fix or float per sky view" satisfied; re-attempt
  fixed with open sky).
- **TCP:** 50,304 NMEA lines to a silent listener, **zero reconnects,
  max inter-line gap 1.0 s**.
- **BLE NUS:** three streaming sessions ≈ 58 min total with two
  bounces, every reconnect clean, **37,628 sentences notified**;
  `bleDrops=224` (~0.6 %, drop-oldest at epoch bursts coinciding with
  SD stalls — §7.4's "verify don't assume" item answered: not zero,
  functionally invisible to a live-position consumer; bump
  kQueueLines/kMaxNotifyPerPass if it ever matters).
- **SD:** same file all run, 5,045,080 B written (matches the ~1.1
  kB/s RAWX rate × 4,500 s); post-soak convbin parse = optional
  owner step.
- **Loop health:** 75/75 one-per-minute worst-loop reports (no
  resets); median worst-pass ≈ 132 ms, max 512 ms (SD latency spikes,
  bounded, no growth trend; 32 KiB SERCOM ring ≈ 13 s of margin).

**Simultaneous WiFi + BLE is proven on the assembled Pynt.** Q18's
original constraint is dead on this branch.

**Owner confirmation (same day): the soak's BLE client was iOS
SW Maps** connected to `PyntRTK-rover` as a Bluetooth GNSS instrument
— the Q19 payoff, delivered. Q19 closed with both phone paths live
(QField/TCP + SW Maps/BLE).

### 2026-07-26 — Metro flashed (section 3) + Spike A PASS (section 4)

Metro M4 AirLift Lite, app port **COM9** (bootloader enumerates
separately as COM7).

**Flashing.** The section 3 esptool commands failed as written on this
host, twice over, both host-side — the module and procedure are fine:

1. *CLI can't connect through the bridge.* esptool on Windows forces
   DTR+RTS low before opening the port (`loader.py` "avoid unwanted
   chip reset"); the Adafruit SAMD CDC core discards device→host bytes
   while neither line is asserted, so the ROM loader's sync replies
   never reach esptool ("No serial data received"). Proven by raw
   pyserial probe with DTR/RTS asserted: loader answers instantly.
   Fix: `flash_via_bridge.py` (parked next to the bin) — opens the port
   itself, then `esptool.main(esp=...)`.
2. *Compressed write dies deterministically.* `write-flash` (default
   deflate) aborted at exactly compressed offset 294912 (block 19) on
   two runs, even with 30 s timeouts — content-dependent transport
   failure somewhere in the host→device path. `--no-compress` wrote all
   2,097,152 bytes clean, ~188 s, `Hash of data verified`.

Backup `metro-stock-backup.bin` taken first (2,097,152 B, 0xE9 magic at
0x1000, ~192 s read). esptool 5.3.1 in a scratch venv (NOT on PATH on
this machine, contrary to the section 1 table).

**Spike A.** `metro-spike-wifi` + 240 s scripted capture
(`spikeA-metro-2026-07-26.log` next to the bin):

- `NINA firmware: 3.0.1` at t=1.0 s; no SPI errors at any point.
- Scan listed hotspot `Airport` (−82 dBm) — plus a scan-print cosmetic
  quirk: the neighboring printer's long SSID ran into the next entry on
  one line (`...9120eAirport`), worth re-checking string termination in
  the scan path if it ever matters; per-entry RSSI was sane.
- Join → IP 192.168.0.168 at t=9.6 s.
- 47/47 status lines at 5 s cadence over 240 s, `drops=0`, RSSI
  −73…−87 dBm, uptime counter monotonic (no resets).

Spike B (`metro-spike-coex`) is next; it needs the phone running nRF
Connect / LightBlue plus a laptop `nc` client on the hotspot, so it
wasn't run unattended.

### 2026-07-26 — Spike B PASS (section 5): WiFi + BLE simultaneous

34-minute attended soak, same Metro/COM9. Logs parked next to the bin
(`spikeB-metro-serial-2026-07-26.log`, `spikeB-metro-tcp-2026-07-26.log`).
Serial side: scripted capture from boot; TCP side: scripted client from
this PC (wired side of the Airport LAN), 1 Hz stream logged + a ping
sent every 60 s to prove two-way echo. BLE side: phone on nRF Connect,
subscribed to NUS TX on **PyntRTK-coex**.

- Boot: NINA 3.0.1, WiFi join at t=4.9 s (IP 192.168.0.168), TCP server
  bound, `BLE.begin()` OK and advertising at t=5.3 s — WiFi + BLE
  co-resident on the one SPI link, no mode switch.
- `up=` monotonic 5 s → 2075 s, zero non-monotonic steps (no watchdog /
  brownout resets). `drops=0` the whole run. RSSI −72…−84 dBm.
- TCP: connected at up≈32 s, **zero disconnects over 33 min**, 2002
  1 Hz lines received, **34/34 pings echoed**.
- BLE: connected up=177 s → 1239 s (17.7 min continuous, concurrent
  with TCP — gate met on that stretch alone), user-initiated bounce,
  reconnected up=1291 s → end. The bounce didn't perturb TCP at all
  (echo + stream continuous through the window).
- Serial: only the boot banner and expected events — zero SPI timeout
  spew across 2071 consecutive status lines.
- ~~**Bonus finding:** the TCP client was accepted **without sending a
  byte** — upstream nina-fw 3.0.1's `server.available()` is NOT
  data-gated.~~ **CORRECTED 2026-07-27:** misread — the Spike B test
  client pinged on connect, which is what satisfied the (still
  data-gated) `available()` path. The real mechanism, found from
  source during the A.2 soak bring-up: `server.available()` sends
  `accept=false` and is data-gated on ALL nina-fw versions; nina-fw
  3.x's true accept is reached only via upstream's new
  `server.accept()` API. See Q19 and the 7.3 checklist item.

### 2026-07-27 — Decision: Spike C superseded, Pynt unlocked

Owner call (no SD breakout on hand, no soldering the Wing's GPIO0
jumper): the standalone Feather soak is dropped and its SD-vs-radio
contention check folds into the section 7.5 integration soak on the
Pynt itself. Rationale recorded in section 6; original procedure
preserved in Appendix A. Sections 7 (step-by-step unlock) and 8
(rollback) rewritten accordingly.

### 2026-07-27 — Spike C PASS via the A.2 HUZZAH32 rig (72-min soak)

Rig: Feather M0 Adalogger (COM4) + hand-wired HUZZAH32 (COM3) running
`NINA_W102-3.0.1-airlift.bin` (flashed over its own USB after a full
4 MB stock backup, `huzzah32-stock-backup.bin`). Bring-up needed the
`feather-wire-probe` twice (miswired CS, then a disturbed READY wire)
and surfaced the `server.accept()` finding (separate bench note).
Monitors: scripted serial capture + a pure-listener TCP client from
this PC; BLE via phone (nRF Connect on **PyntRTK-soak**).

All A.1 gates green over **72 min** (final: `writes=4369 up=4376s`):

- **No resets:** writes counter monotonic across all 144 reports;
  1 write/s ≈ uptime throughout.
- **SD:** `sdErrors=0`; **worst write 109.7 ms** (vs 93.6 ms Pynt
  WiFi-only baseline — same order, one U1-class latency spike; well
  inside the platform.md buffer margins).
- **WiFi:** `drops=0` for the entire run; RTCM-sized TCP traffic
  unaffected.
- **TCP:** one connection held 70+ min — **4262 lines at 1 Hz, zero
  reconnects, max inter-line gap 1.6 s**; accepted as a silent
  listener via `server.accept()` within one loop pass.
- **BLE:** five connect sessions totaling ≈48 min (longest 20.5 min
  continuous), interleaved with deliberate bounces — every disconnect
  re-advertised and re-accepted, TCP/SD/WiFi undisturbed through all
  of them.
- `soak.bin` post-read on a card reader (expected ≈ 2.24 MB =
  4369 × 512 B): left to the owner, optional — the CRC-stamped records
  and `sdErrors=0` already cover the integrity gate's intent.

**Consequence: the shared-SPI contention question is answered on spare
hardware after all — SD + WiFi + BLE coexist cleanly on one bus with
the custom firmware and upstream stack. Section 7 (Pynt) proceeds with
one less unknown.**

## Appendix A — standalone Spike C procedures

### A.1 — original AirLift FeatherWing procedure

<details>
<summary>Superseded 2026-07-27 — kept for a future bench that has the
AirLift FeatherWing with its GPIO0 jumper soldered closed and a spare
SD-equipped host. The <code>feather-soak-coex</code> and
<code>passthrough-feather</code> envs still build.</summary>

This was the Pynt's dress rehearsal: SD writes + WiFi TCP + BLE notify
contending on one SPI bus for an hour, on spare silicon.

Hardware prep:

- [ ] **Close the Wing's GPIO0 solder jumper.** Needed twice over: the
      passthrough uses GPIO0 (pin 10) to enter the ROM loader, and
      WiFiNINA 2.x polls GPIO0 as the module's data-ready IRQ during
      normal operation (stock Adafruit stack never did — this is new).
- [ ] Wing stacked on the Adalogger (Wing CS/BUSY/RESET/GPIO0 =
      pins 13/11/12/10; onboard SD CS = 4).
- [ ] FAT32 microSD in the Adalogger slot (a spare — `soak.bin` gets
      truncated each boot).
- [ ] Flash the **Wing's** ESP32: `passthrough-feather` + section 3
      commands (own backup file: `wing-stock-backup.bin`).

Run:

```
pio run -e feather-soak-coex -t upload && pio device monitor -b 115200
```

Connect a `nc` client and a BLE subscriber (device name **PyntRTK-soak**)
as in Spike B, then leave it for ≥ 60 min.

Pass gates:

- [ ] ≥ 60 min, `up=` never restarts
- [ ] `sdErrors=0`, writes ≈ uptime seconds (one 512 B record/s + sync
      every 8th — the rover's cadence)
- [ ] Worst SD write latency recorded here: `______ ms` (Pynt bench saw
      93.6 ms WiFi-only; expect same order under coex)
- [ ] WiFi drops recover unaided; BLE stays subscribable throughout
- [ ] `soak.bin` readable afterwards, size ≈ writes × 512

</details>
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

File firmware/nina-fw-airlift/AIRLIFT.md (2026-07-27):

# nina-fw 3.0.1-airlift — vendored ESP32 module firmware

Vendored copy of **arduino/nina-fw, tag `3.0.1`** (commit `57d12f460aceb0d4f81102a7186ddfdbebe0bd5e`), the firmware that runs *on the AirLift's ESP32 (NINA-W102)*, not on the SAMD host.

Why this exists: nina-fw 3.0.x is where Arduino made WiFi + BLE
**simultaneous** — no boot-time WiFi-or-BLE strap, BLE controller in VHCI
mode, BLE HCI multiplexed onto the same SPI command server WiFi uses, and
ESP-IDF software coexistence on (`CONFIG_SW_COEXIST_ENABLE=y` /
`CONFIG_ESP32_WIFI_SW_COEXIST_ENABLE=y` in `sdkconfig`). Adafruit's own
nina-fw fork never adopted any of that (see `docs/QUESTIONS.md` Q18).

## The one source change

`arduino/libraries/SPIS/src/SPIS.cpp`, last line: SPI slave **MOSI 12 → 14**.
Adafruit AirLift boards route host-MOSI to ESP32 GPIO14 (GPIO12 is the
MTDI flash-voltage strap on their layout); MISO 23, SCK 18, CS 5 and
READY/BUSY 33 are identical to upstream. The image carries no other
host-board knowledge, so **one .bin serves the Metro M4 AirLift Lite, the
AirLift FeatherWing, and the PyPortal Pynt**.

## Building the monolithic .bin

Toolchain: **ESP-IDF v4.4.8** (the 3.0.1 README's manual instructions
still name the ancient IDF v3.3.1; its Docker tag `espressif/idf:v4.4.8`
is authoritative for 3.0.x). The build needs Linux — this is the legacy
GNU-make IDF build, which was never supported on native Windows.

**Verified path (2026-07-26, WSL2 Ubuntu-22.04, this repo's tree):**
one-time setup as root inside WSL —

```bash
apt-get install -y git wget flex bison gperf python3 python3-pip python3-setuptools python3-venv cmake ninja-build ccache libffi-dev libssl-dev dfu-util libusb-1.0-0 build-essential
git clone --depth 1 --branch v4.4.8 --recursive --shallow-submodules https://github.com/espressif/esp-idf.git /opt/esp-idf-v4.4.8
/opt/esp-idf-v4.4.8/install.sh esp32
```

then per build (copy the tree onto the Linux filesystem — building
straight on `/mnt/c` is slow):

```bash
cp -r /mnt/c/Projects/PyPortal-Pynt-RTK/firmware/nina-fw-airlift /root/nina-build
cd /root/nina-build && . /opt/esp-idf-v4.4.8/export.sh
RELEASE=1 make -j$(nproc)
python combine.py NINA_W102-3.0.1-airlift
cp NINA_W102-3.0.1-airlift_ALL.bin /mnt/c/Projects/PyPortal-Pynt-RTK/firmware/nina-fw-airlift/NINA_W102-3.0.1-airlift.bin
```

Docker alternative (same toolchain, untested here): from this directory,
`docker run --rm -v "$PWD":/data espressif/idf:v4.4.8 sh -c 'cd /data && RELEASE=1 make && python combine.py NINA_W102-3.0.1-airlift'`.
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

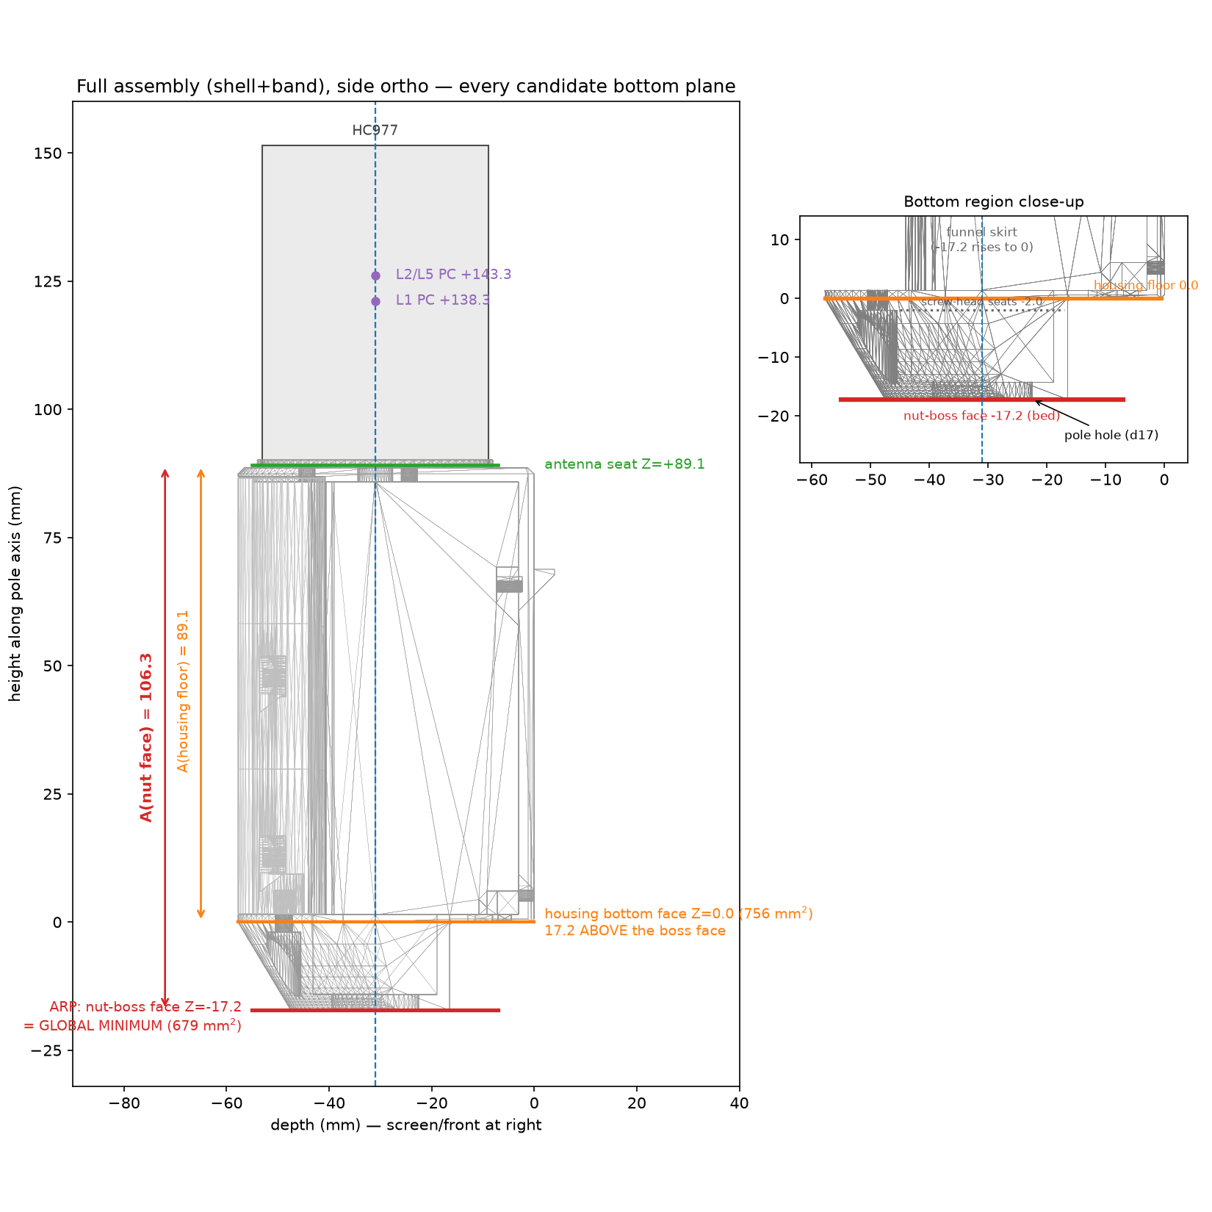
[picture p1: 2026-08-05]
docs/hardware/pynt-arp-side-annotated.png

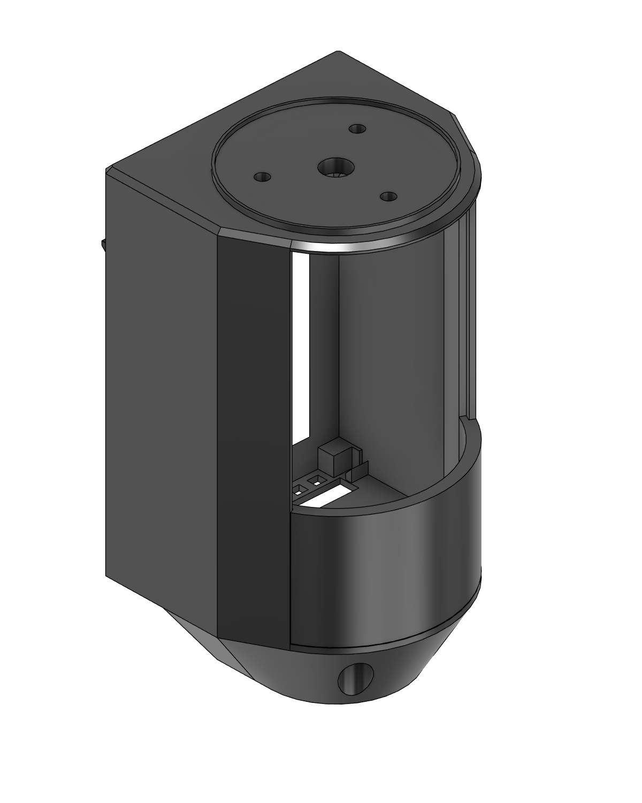
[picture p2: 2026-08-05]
docs/hardware/enclosure-d-rear.png

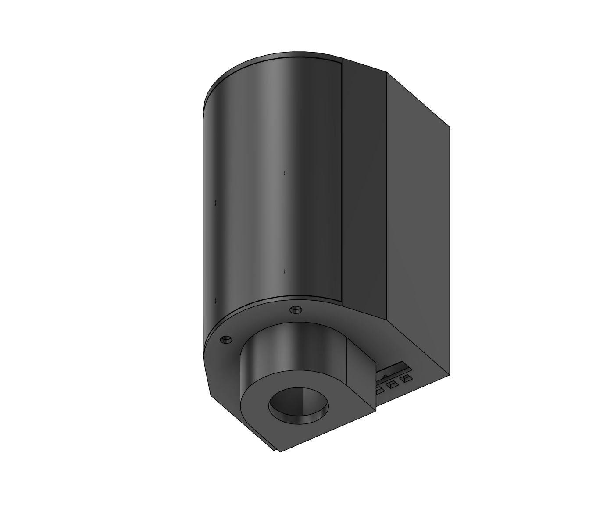
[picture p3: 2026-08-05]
docs/hardware/enclosure-d-bottom-iso.png

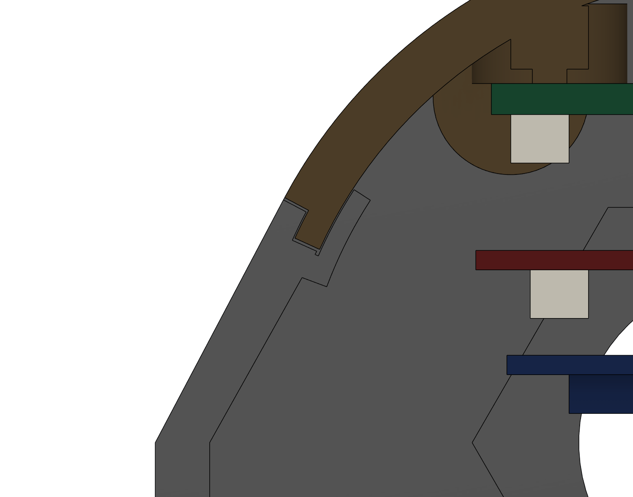
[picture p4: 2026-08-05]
docs/hardware/enclosure-d-ledge-closeup.png

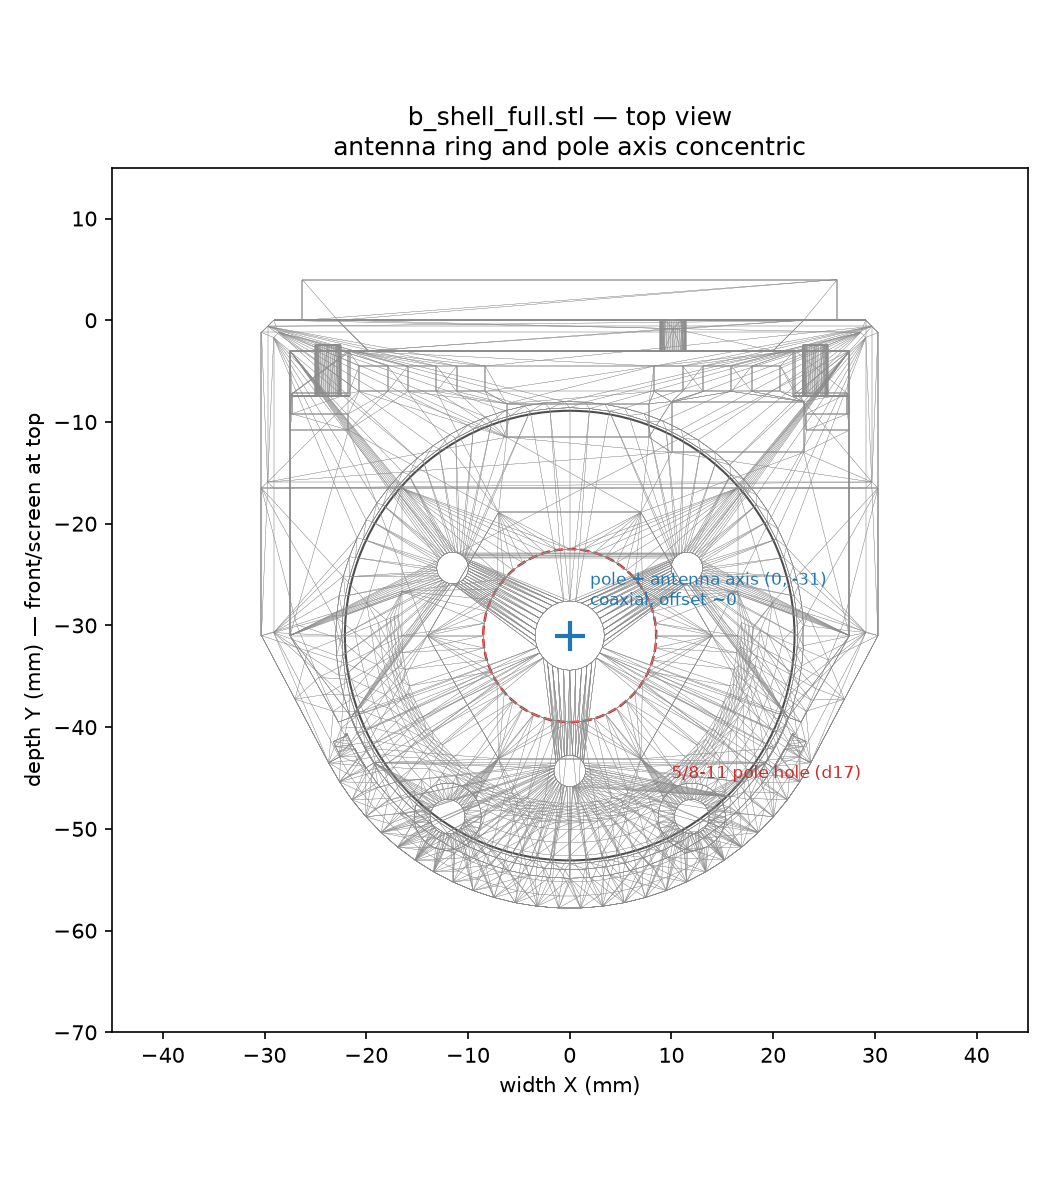
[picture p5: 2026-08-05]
docs/hardware/pynt-arp-top-annotated.png

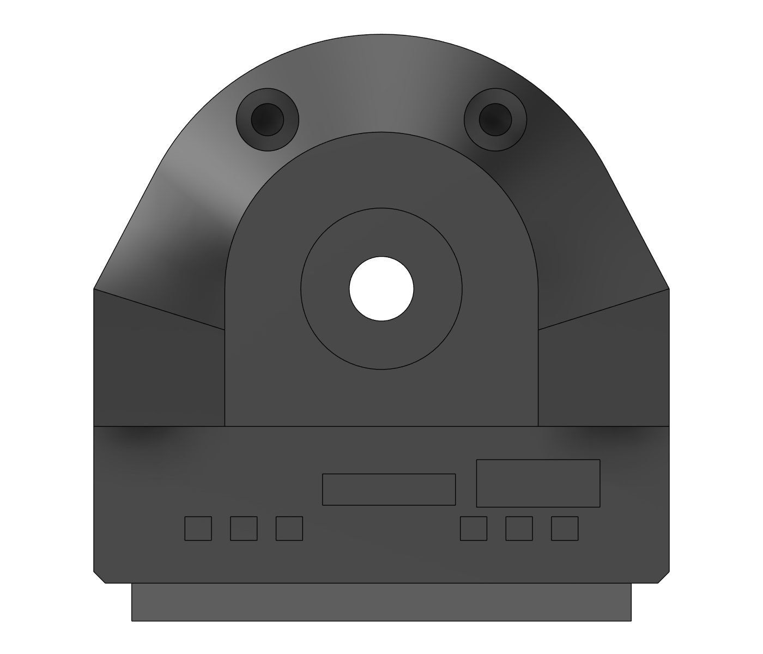
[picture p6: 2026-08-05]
docs/hardware/enclosure-d-bottom.png

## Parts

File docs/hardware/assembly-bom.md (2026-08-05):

# Final assembly — full parts list (rev B "D" enclosure)

Status 2026-07-28: full shell + band print confirmed good on the MK4S in
PETG (organic supports). ANT_BCD resolved from the Calian drawing:
**Ø26.6** — the first full shell printed with the 28.0 placeholder, so
its 3 antenna holes sit 0.7 mm out (salvage: elongate ~0.5 inward, or
reprint from the corrected `b_shell_full.stl`).

## Printed parts (PETG, nut-side down)

| # | Qty | Part | Source |
|---|---|---|---|
| P1 | 1 | Shell D — main enclosure (integral lid, D-funnel, nut boss) | `enclosure/prints/b_shell_full.stl` |
| P2 | 1 | Case back D — curved band with carrier bosses | `enclosure/prints/b_band_full.stl` |

## Electronics

| # | Qty | Part | Notes |
|---|---|---|---|
| E1 | 1 | Adafruit PyPortal Pynt | slides into the ear slots, screen at the front window |
| E2 | 1 | ArduSimple simpleRTK2B **Lite** (ZED-F9P) | plugs into the carrier's XBee headers |
| E3 | 1 | ArduSimple XBee-to-USB carrier (**mini-USB** FTDI) | mechanical mount for the Lite, screwed to the band; USB is internal/service-only (one-driver rule — never together with the JST link) |
| E4 | 1 | HC977 helical GNSS antenna | on the lid, full Ø46 base supported; north hole aims rearward |

## RF chain

| # | Qty | Part | Notes |
|---|---|---|---|
| R1 | 1 | SMA female bulkhead adapter, plain round thread | through the lid hole; anti-rotation via lock washer (no D-flat) |
| R2 | 1 | bulkhead nut + lock washer | comes with R1 |
| R3 | 1 | SMA extension cable | bulkhead (inside) → Lite's SMA jack |

## Fasteners & inserts

| # | Qty | Part | Where |
|---|---|---|---|
| F1 | 6 | M3×4 heat-set insert (Ø4.0 pilots) | 2 in the band's floor-screw bosses (set from the undersides, **before** the band goes in), 4 in the carrier bosses |
| F2 | 2 | M3×8 pan-head | up through the funnel counterbores into F1 — clamps the band to the floor |
| F3 | 4 | M3×6 pan-head | carrier board → carrier boss inserts |
| F4 | 2 | M3×6 pan-head | Pynt top ears → direct-thread into the Ø2.5 pilots (no inserts — no room beside the glass) |
| F5 | 3 | M2.5×8 | through the lid into the HC977's integral inserts — BCD **Ø26.6**, 6 mm deep, 120° (Calian drawing); ~4.7 mm engagement |
| F6 | 1 | 5/8"-11 hex nut (survey standard) | dropped into the boss pocket before pole mounting; captured, not glued |

## Cables & power

| # | Qty | Part | Notes |
|---|---|---|---|
| C1 | 1 | Pixhawk JST-GH ↔ D3/D4 harness (built, tape-labeled) | 4 conductors: Lite pin 1/6 → D4 VCC/GND (5 V power), Lite pin 3 (TX) → D3 signal, D4 signal → Lite pin 2 (RX) — see `wiring.md` |
| C2 | 1 | USB cable, micro-B | power bank → Pynt micro-USB, through the bottom USB slot |
| C3 | 1 | USB battery bank, 1 port ≥1 A | external — carried, not enclosed (future dock is a separate design) |

## Future / not installed

| Part | Why listed |
|---|---|
| XBee radio in the Lite's top socket | UART2 + the socket are reserved for it; the enclosure's radio void already clears the stack |
| mini-USB cable for the carrier | service/u-center config only, case open, JST link disconnected first |

## Assembly order

1. Set all 6 heat-set inserts (F1) into the printed parts.
2. Drop the 5/8"-11 nut (F6) into the boss pocket.
3. Bulkhead (R1/R2) into the lid, lock washer inside; connect the SMA
   extension (R3) and leave it dangling.
4. Slide the Pynt (E1) down the ear slots; **start both top screws
   (F4) before tightening either** — the board centers on the screws
   (the slots no longer end-stop it laterally).
5. Connect the D3/D4 harness (C1) to the Pynt.
6. Screw the carrier (E3) to the band bosses (F3); seat the Lite (E2);
   connect its JST end of C1 and the SMA extension (R3).
7. Band in: top edge up into the lid groove, tongues into the side
   grooves (anti-flex ledges back them), drop onto the floor; 2× M3×8
   (F2) up through the funnel.
8. Antenna (E4) on the lid pad, north rearward, 3× M2.5×8 (F5).
9. Route C2 through the USB slot to the power bank.

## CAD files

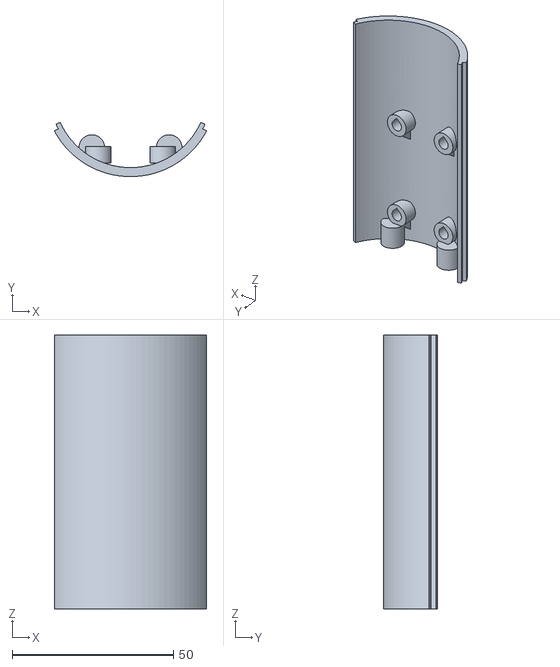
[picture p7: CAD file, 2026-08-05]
enclosure/prints/b_band_full.stl
47.3 x 16.8 x 85.0

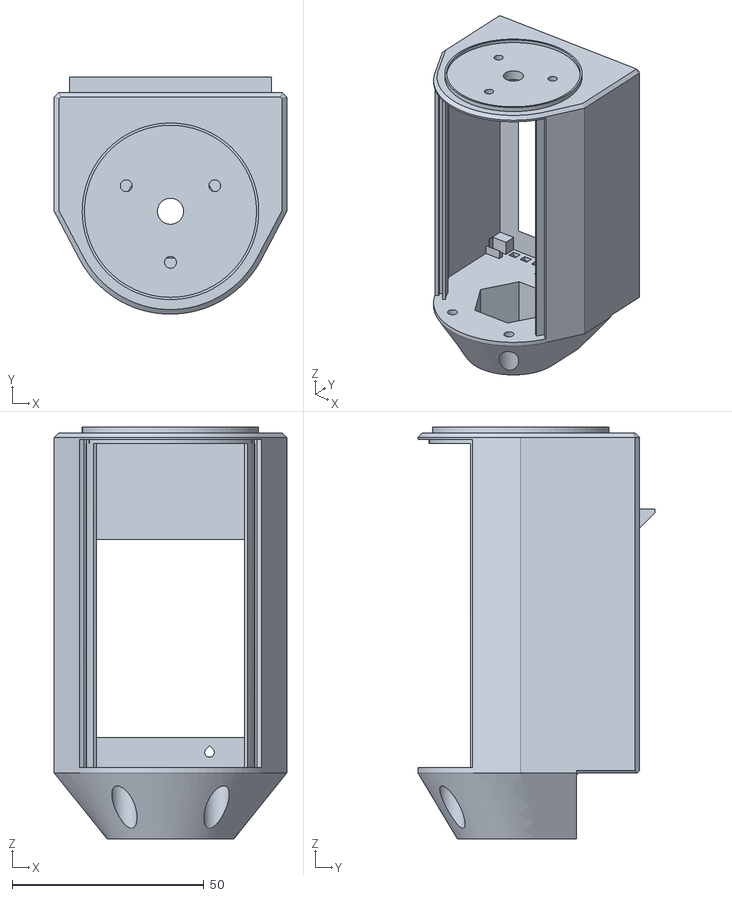
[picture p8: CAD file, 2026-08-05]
enclosure/prints/b_shell_full.stl
60.6 x 61.8 x 107.3

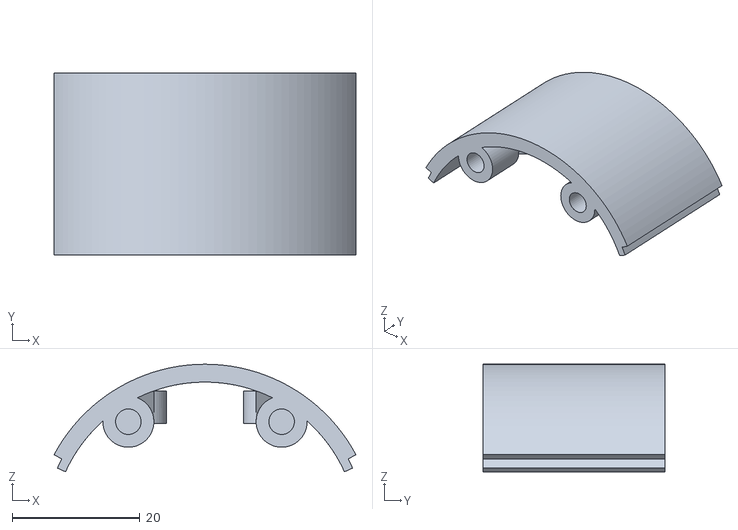
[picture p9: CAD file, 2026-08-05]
enclosure/prints/b_band_test.stl
47.3 x 28.5 x 16.8

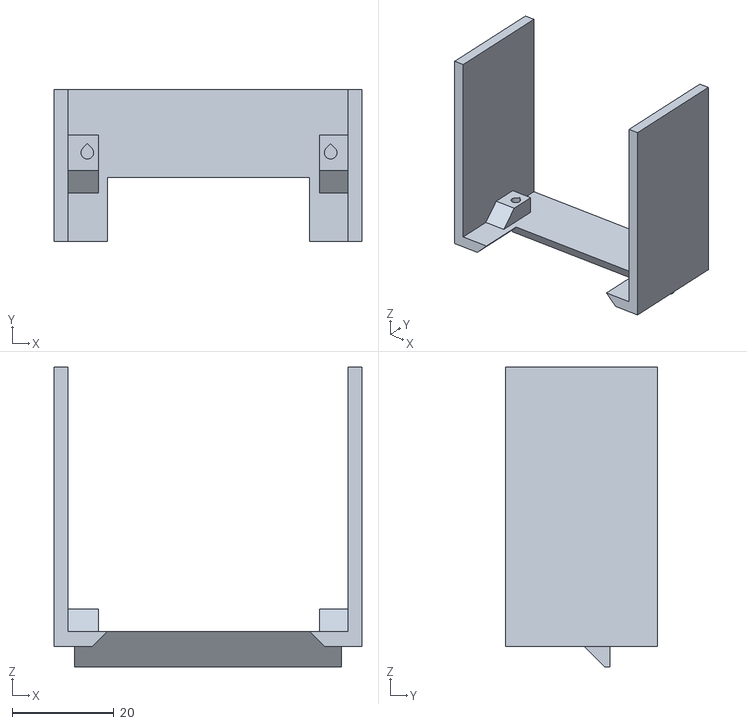
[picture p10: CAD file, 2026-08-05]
enclosure/prints/bezel_test.stl
60.6 x 30.0 x 59.0

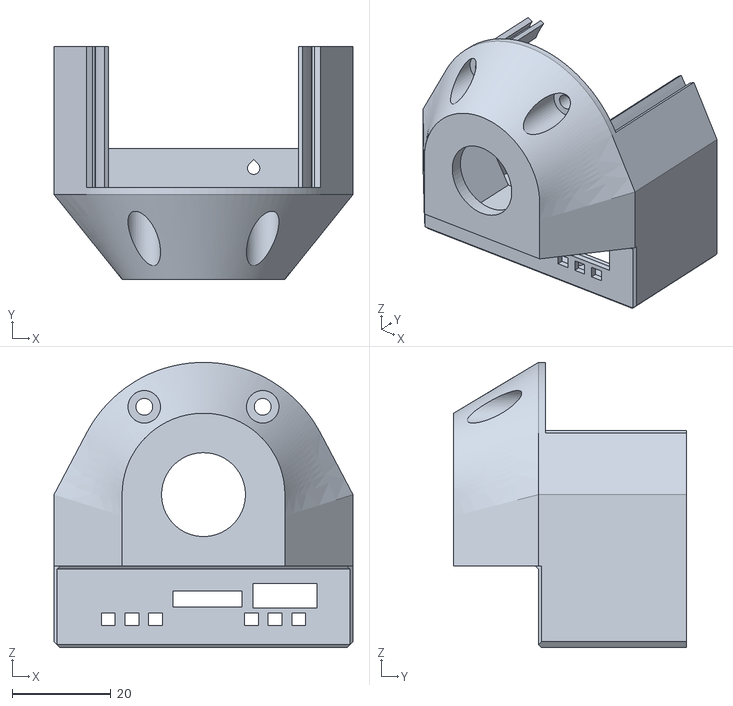
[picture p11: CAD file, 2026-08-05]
enclosure/prints/b_base_test.stl
60.6 x 47.2 x 57.8

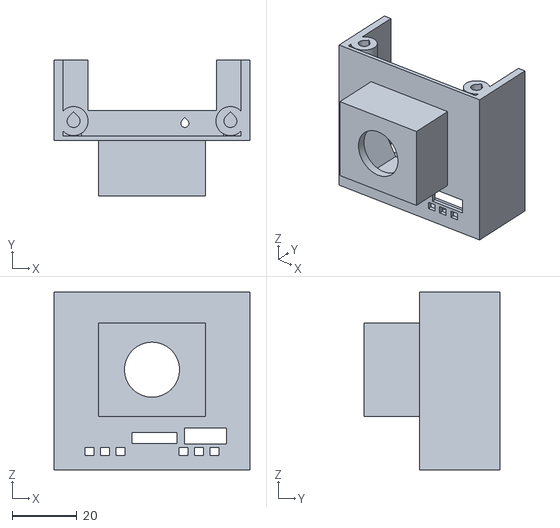
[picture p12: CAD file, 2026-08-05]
enclosure/prints/base_test.stl
60.6 x 42.2 x 55.0

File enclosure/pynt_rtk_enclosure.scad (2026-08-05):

// PyPortal Pynt RTK — enclosure rev A
// Parametric OpenSCAD. See docs/hardware/enclosure.md for rationale.
//
// Frame: X = width (0 at center), Y = height (0 at exterior bottom face,
// +up), Z = depth (0 at exterior front face, +rearward).
// Render: set `part` below (or -D 'part="shell"' on the CLI), F6, export STL.
//
// Dimension provenance: Adafruit PyPortal Pynt .brd/.step, ArduSimple
// simpleRTK2B Lite + USB-C carrier .step, Calian HC977 datasheet 202203.
// carrier_* comes from the USB-C carrier STEP; owner confirmed 2026-07-19
// the mini-USB board on hand is identical except the connector itself.

part = "assembly"; // "shell" | "cover" | "assembly" | "base_test" | "bezel_test"

$fn = 64;
fudge = 0.15;          // printer XY compensation per side, tune to your machine

/* ---------- shell ---------- */
wall     = 2.8;
front    = 3.0;        // front (bezel) wall
cover_t  = 2.8;
floor_t  = 1.4;        // rev A7: bottom wall halved for USB plug / SD card reach
int_w    = 55.0;
int_h    = 83.0;
int_d    = 52.0;       // fits the full Ø46 antenna pad: axis_z + 23 + 1 <= shell_d

ext_w    = int_w + 2*wall;            // 60.6
ext_h    = int_h + 2*wall;            // 88.6
shell_d  = front + int_d;             // 55.0
total_d  = shell_d + cover_t;         // 57.8

/* ---------- pole / antenna axis ---------- */
// Behind the front face. Chosen so the nut boss's front face (axis_z - 14.5)
// clears both the SD card path (z<11.5) and the USB plug body (z<14.5).
axis_z   = 31.0;

/* ---------- PyPortal Pynt (#4465), exact from Adafruit CAD ---------- */
// Board frame: Xb along the 66.8 edge (0 = USB/SD edge, faces DOWN in
// rotation 2), Yb along the 43.2 edge. Ears: Yb -5.207..48.006.
pynt_mirror   = -1;    // confirmed 2026-07-19: USB lands on the viewer's
                       // LEFT (+x) looking at the screen in D2 portrait
pynt_len      = 66.802;
pynt_body_w   = 43.180;
pynt_yc       = pynt_body_w/2;        // 21.59, mirror line
pynt_y0       = floor_t;              // rev A7: ZERO standoff — board bottom edge
                                      // sits ON the floor (USB/SD reach)
pynt_holes_Xb = [2.540, 64.262];
pynt_holes_Yb = [-2.540, 45.339];
// depth stack
foam_gap      = 0.5;   // foam tape between glass perimeter and front wall
glass_h       = 3.9;   // PCB front face -> top of touch overlay
pcb_t         = 1.6;
z_pcb_front   = front + foam_gap + glass_h;   // 7.4
z_pcb_back    = z_pcb_front + pcb_t;          // 9.0
pynt_back_h   = 4.8;   // JST sockets, tallest back-side parts
// viewing window (bezel opening), board coords + margin
win_Xb = [8.49, 58.74];
win_Yb = [2.19, 40.79];
win_margin = 0.6;
// features on the bottom (USB/SD) edge, board Yb coords
usb_Yb_c   = 5.08;   usb_slot_w = 13.0;  usb_slot_z = [8.0, 13.0];
sd_Yb_c    = 19.8;   sd_slot_w  = 12.0;  sd_slot_z  = [8.2, 11.5];  // front edge aligned w/ USB
lightsensor_XbYb = [3.94, 11.43];      // pinhole through front wall

function bx(Yb) = pynt_mirror * (Yb - pynt_yc);   // board Yb -> enclosure X
function by(Xb) = pynt_y0 + Xb;                   // board Xb -> enclosure Y

/* ---------- carrier + Lite stack (mounted on the back cover) ---------- */
carrier_l       = 41.0;   // along Y, USB end DOWN
carrier_w       = 26.0;   // along X, centered
carrier_hole_dy = 35.0;   // hole grid (3 mm in from each edge)
carrier_hole_dx = 20.0;
carrier_y0      = 6.0;    // bottom edge of carrier above interior floor
carrier_boss_h  = 3.5;    // clears 1.35 mm solder tails
stack_h         = 15.3;   // carrier PCB bottom -> Lite JST-GH top (from CAD)
lite_top_off    = 9.6;    // carrier PCB bottom -> Lite PCB top face
radio_void      = 12.0;   // reserved fwd of Lite top for future XBee radio

/* ---------- antenna / SMA bulkhead (lid) ---------- */
sma_hole_d   = 6.5;      // round bulkhead — owner's adapter has no D-flat
ant_pad_d    = 46.0;     // HC977 base is 44.2
ant_recess_d = 44.8;
ant_pad_h    = 1.5;
ant_recess_h = 1.0;
ant_bcd      = 26.6;     // HC977 3x M2.5 insert bolt circle, per the Calian
                         // mechanical drawing (3x M2.5 deep 6, 120 deg)

/* ---------- 5/8"-11 pole nut boss ---------- */
// Hex pocket axis along Y; hexagon corners point along ±X, flats face ±Z
// (that combination clears the USB plug in Z and keeps 2.4 mm walls).
nut_af       = 23.83;    // across flats
nut_t        = 13.9;
nut_pocket_af= nut_af + 0.4;
nut_R        = nut_pocket_af / sqrt(3);   // circumradius ≈ 13.99 (±X extent)
boss_floor   = 3.0;
boss_h       = nut_t + 0.3 + boss_floor;  // 17.2 below the base
boss_hx      = 16.5;     // half-width  (pocket corners 13.99 + wall)
boss_hz      = 14.5;     // half-depth  (pocket flats 12.11 + wall)
pole_hole_d  = 17.0;     // clearance for the 5/8-11 stud

/* ---------- cover ---------- */
lip_h       = 3.0;
lip_t       = 2.0;
post_d      = 9.0;
post_h      = 12.0;
post_x      = int_w/2 - 3.25;             // corner posts, buried into the walls
post_dy     = int_h/2 - 3.25;
insert_d_m3  = 4.0;    // ALL printed inserts are M3 (owner stock: 4/6/8 mm
                       // lengths; 4 mm in Pynt/carrier bosses, 6-8 in posts)

/* ---------- derived / sanity checks ---------- */
z_lite_top = shell_d - carrier_boss_h - lite_top_off;    // Lite top face
echo("EXTERIOR W x H x D", ext_w, ext_h, total_d);
echo("pole shoulder -> antenna pad top (mm)", boss_h + ext_h + ant_pad_h);
echo("Lite top at z", z_lite_top, "; radio void reaches z", z_lite_top - radio_void);
assert(z_lite_top - radio_void > z_pcb_back + pynt_back_h + 1,
       "radio void collides with the back of the Pynt");
assert(axis_z - boss_hz > usb_slot_z[1] + 1.5, "nut boss too close to the USB plug");
assert(axis_z - boss_hz > sd_slot_z[1] + 1.5,  "nut boss blocks the SD card path");
assert(axis_z + boss_hz <= total_d + 0.01,     "nut boss past the cover's back face");
assert(axis_z + ant_pad_d/2 + 1 <= shell_d + 0.01,
       "antenna pad hangs past the shell's back face");
assert(ant_bcd/2 + 2 < ant_recess_d/2, "antenna screw holes outside the recess");

/* ================= modules ================= */

module rrect(w, h, r) { offset(r) offset(-r) square([w, h], center=true); }
module post_positions() {
  for (sx=[-1,1], sy=[-1,1])
    translate([sx*post_x, ext_h/2 + sy*post_dy, 0]) children();
}
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

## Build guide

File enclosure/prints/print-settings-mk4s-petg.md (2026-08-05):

# Rev B full print — Prusa MK4S / PETG settings

Files (pre-oriented: Z-up = print orientation, both land nut-side /
floor-side down in the slicer — no manual rotation needed):

| File | Part | Volume | Height on bed |
|---|---|---|---|
| `b_shell_full.stl` | Shell D (main enclosure, integral lid + funnel + boss) | 57.8 cm³ | 107.3 mm |
| `b_band_full.stl` | Case back D (curved band + carrier bosses) | 14.4 cm³ | 85.1 mm |

Profiles: **Original Prusa MK4S, 0.4 nozzle, "0.20mm SPEED"** structural
base (drop to 0.15 QUALITY if you want a crisper window edge — adds ~2 h).
Filament: **Prusament PETG defaults** — nozzle 240 °C, bed 85 °C, fan
20–50 %, no cooling first 3 layers.

| Setting | Value |
|---|---|
| Perimeters | 3 (2.8 walls = 3 loops + light infill) |
| Top / bottom layers | 5 / 4 |
| Infill | 15 % gyroid |
| Brim | **5 mm** on the shell (it stands on the ~33 mm boss footprint until the funnel widens — tall part, small first contact); 4 mm on the band |
| Seam | Rear, aligned/painted on the rear arc centerline (hidden against the pole) |
| Supports mode | **"For support enforcers only"** — paint them; do NOT use auto/everywhere |

## Supporting the top of the main enclosure (the lid ceiling)

The integral lid's **interior ceiling** is the one large flat overhang:
a ~55 × 51 mm D-shaped roof at **103 mm above the bed**, spanning the open
cavity. Supports for it tower ~84 mm up from the interior floor, so they
must be allowed to land **inside the part** ("support on build plate
only" = OFF).

Paint an enforcer across the whole interior ceiling, then:

| Support setting | Value | Why |
|---|---|---|
| Style | **Organic** (owner-confirmed on the full print) or Snug | Organic printed the ceiling cleanly on the MK4S; Snug remains the fallback if a future print's ceiling reads ropey |
| Top contact Z distance | **0.25 mm** (go 0.30 if it still welds) | PETG fuses to PETG at the default 0.2 |
| Interface layers | 3 top / 2 bottom | Flat ceiling needs a dense roof to avoid sag between pillars |
| Interface pattern spacing | 0.2 mm | Near-solid interface under the ceiling |
| Support/object XY separation | **0.8 mm** | Keeps pillars from bonding to the interior walls and bosses |
| Interface loops | Off | Easier extraction |
| Pattern spacing | 2.5 mm | Stiff enough at 84 mm tall without becoming a solid brick |

**Extraction path:** print the shell *without* the band installed slot —
the whole rear arc aperture is open, so after printing the support block
tilts and slides out **rearward** through the case-back opening in one
piece. Don't fish it through the window.

Two smaller enforcer zones while you're painting:

- **Front strip underside** (the USB/SD/vent strip, first 16.5 mm behind
  the front face): it's a flat downward face 17 mm above the bed —
  outside the funnel's footprint, so it gets no material below it. Paint
  it; these supports stand on the build plate and snap off easily.
- **Window lintel** (top edge of the screen opening + eyebrow): ~47 mm
  span in the vertical front wall. PETG will bridge it, but the visible
  edge sags; a thin painted strip keeps it crisp.

**Do NOT support** (all designed self-supporting nut-side down — add
blockers if the slicer sneaks anything in):

- D-funnel and boss flanks (≥45° slopes) and the screw counterbores
- Hex nut pocket ceiling (bridges the Ø17 pole-hole ring — proven on the
  base test)
- Teardrop holes (that's what the teardrops are for)
- Band tongue grooves, lid top groove, anti-flex ledge gaps — supports in
  the 0.075 clearances would ruin the confirmed fit; drop blockers in
- Carrier bosses on the band (gusset fins carry them)
- SMA bulkhead, pole and antenna holes (plain round by design — gasket
  seats, and they print vertically here anyway)

## Case back band

No supports at all — it's a constant cross-section arc standing on its
bottom edge; carrier bosses are carried by their 45° gussets and the
insert bosses sit at the bottom. Just give it the 4 mm brim (tall, thin
footprint) and keep it inboard on the sheet so the arc doesn't catch the
nozzle wipe.

## After the print

- 6× M3×4 heat-set inserts: 2 in the band's floor-screw bosses (set from
  the boss undersides) + 4 in the carrier boss pockets.
- Check the band tongue fit dry before inserts — clearances are the
  confirmed 0.075 set; if this batch of PETG shrinks differently, scale
  the band X/Y by +0.1–0.2 % rather than reprinting the shell.

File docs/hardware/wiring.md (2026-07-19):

# Full-System Wiring — Pynt ↔ simpleRTK2B Lite

Only **four conductors** connect the two boards (power, TX, RX, ground) —
the Feather build's parallel tap and status link are gone; the Pynt does
everything on one MCU.

**Inherited vendor facts (verified for the Feather build, unchanged):**

- The Lite has **no native USB** — its XBee-to-USB adapter is an FTDI
  bridge onto **UART1**, the same F9P port the Pynt uses. The Pixhawk JST,
  bottom XBee header, and "USB/u-center" are all one port
  ([hookup guide](https://www.ardusimple.com/simplertk2blite-hookup-guide/),
  [ArduSimple Q&A](https://www.ardusimple.com/question/xbee-to-usb-adapter-connection-to-simplertk2blite/)).
- JST-GH pinout, from the F9P's perspective: **1 = 5V_IN, 2 = UART1 RX
  (F9P input), 3 = UART1 TX (F9P output), 4/5 = NC, 6 = GND**. Pin 1 is
  the white square / printed "1" on the PCB; **never trust pigtail wire
  colors** ([Pixhawk cable notes](https://www.ardusimple.com/product/pixhawk-cable-set/)).
- No I2C pads on the Lite — UART1 is the only MCU data path.

## System diagram

```mermaid
graph LR
  subgraph LITE["simpleRTK2B Lite (ZED-F9P)"]
    JST["Pixhawk JST-GH<br/>1:5V_IN 2:U1RX 3:U1TX 6:GND"]
    XBTOP["Top XBee socket = UART2<br/>EMPTY — reserved for future radio"]
    SMA["SMA → HC977 helical<br/>(3.3V bias, ~21 mA)"]
  end
  subgraph PYNT["PyPortal Pynt (SAMD51)"]
    D3["D3 JST — tape-labeled RX<br/>signal (PA04), SERCOM0 pad 0<br/>GND + VCC pins unused"]
    D4["D4 JST — tape-labeled TX<br/>signal (PA05), SERCOM0 pad 1<br/>GND + VCC pins carry power"]
    USB["micro-USB ← battery bank"]
  end

  JST -- "NMEA + UBX (RAWX/SFRBX) → 3.3V" --> D3
  D4 -- "RTCM3 + UBX cfg → 3.3V" --> JST
  D4 -- "5V (VCC pin)" --> JST
  D4 -- "GND pin" --- JST
```

**I2C STEMMA port is left fully unpopulated** — this project has no I2C
use, and D3/D4's own VCC/GND pins measured the same 5V as the STEMMA
port's (bring-up P1/P2, `docs/hardware/bringup-log.md`), so there's no
reason to route a third connector.

## Wire list (every conductor — sourced from just the D3 and D4 connectors)

| # | From | To | Signal | Level |
|---|---|---|---|---|
| 1 | Pynt **D4 JST VCC pin** (pin 2) | Lite JST **pin 1** (5V_IN) | power | 5 V, measured (Lite accepts 4.5–5.5 V) |
| 2 | Pynt **D4 JST GND pin** (pin 1) | Lite JST **pin 6** | ground | 0 V |
| 3 | Lite JST **pin 3** (F9P UART1 **TX**) | Pynt **D3 JST signal pin** (PA04, tape-labeled RX) | NMEA + UBX (RAWX/SFRBX) | 3.3 V |
| 4 | Pynt **D4 JST signal pin** (PA05, tape-labeled TX) | Lite JST **pin 2** (F9P UART1 **RX**) | RTCM3 corrections + UBX config | 3.3 V |

Wires 1 and 2 both come off the D4 connector alongside its signal wire —
three wires off one JST pigtail. D3's own GND/VCC pins go unused; only
its signal pin is wired. This replaces the earlier I2C-STEMMA-for-power
plan in `power.md` shape A now that D3/D4 VCC is confirmed 5V on
hardware — see `power.md` for the updated diagram.

Signal-integrity note: the Pynt's D3/D4 lines each pass through a **1 kΩ
series protection resistor + 3.6 V zener**
([pinouts](https://learn.adafruit.com/adafruit-pyportal/pinouts)). At
115200 baud (bit time 8.7 µs) into the F9P's high-impedance CMOS input the
RC formed with pin capacitance is nanoseconds — no effect. Don't raise the
baud past 230400 without re-checking edges on a scope.

## ⚠ D3/D4 label-swap check (do this before wiring the Lite)

Forum reports say the **Pynt's D3/D4 silkscreen is swapped** vs. the
classic PyPortal ([Adafruit forums](https://forums.adafruit.com/viewtopic.php?t=168933)).
Procedure (Phase 1 bring-up sketch has this test):

1. Jumper the two JST **signal** pins together (D3 socket ↔ D4 socket).
2. Run the UART loopback test: firmware TXs a known pattern on the
   SERCOM0 UART and checks RX echo.
3. If loopback passes, remove the jumper, then run the "which socket is
   TX?" probe: firmware idles TX high and pulses it once per second;
   a multimeter/scope on each socket identifies the physical TX socket.
4. **Label both sockets with tape** per the measurement. Only then wire
   the Lite (its RX ← our measured TX).

Wrong guess consequence: harmless (both ends are 3.3 V UARTs and the
Pynt's pins are series-protected) — it just won't talk. But finding that
out *after* the enclosure is built is why we tape-label now.

## UART recipe (Arduino / Adafruit SAMD core)

Arduino pins 3/4 = PA04/PA05, `PIO_SERCOM_ALT` capable
([variant.cpp](https://github.com/adafruit/ArduinoCore-samd/blob/master/variants/pyportal_m4/variant.cpp)).
PA04 = SERCOM0/PAD[0] (ALT), PA05 = SERCOM0/PAD[1] (ALT); SAMD51 UART TX
must sit on pad 0 → **firmware pin 3 = TX, firmware pin 4 = RX** (this is
the `GNSS_TX_PIN`/`GNSS_RX_PIN` numbering in `pins.h`, unchanged by the
label-swap finding below). What *does* change is which physical socket
that firmware pin comes out on: the swap check found firmware pin 3
(TX) is physically the socket silkscreened **D4**, and firmware pin 4
(RX) is silkscreened **D3** — hence the tape labels used everywhere else
in this doc:

```cpp
Uart SerialGNSS(&sercom0, /*RX*/ 4, /*TX*/ 3,
                SERCOM_RX_PAD_1, UART_TX_PAD_0);
// SAMD51 SERCOMs have four IRQ lines — all must be forwarded:
void SERCOM0_0_Handler() { SerialGNSS.IrqHandler(); }
void SERCOM0_1_Handler() { SerialGNSS.IrqHandler(); }
void SERCOM0_2_Handler() { SerialGNSS.IrqHandler(); }
void SERCOM0_3_Handler() { SerialGNSS.IrqHandler(); }
// after SerialGNSS.begin(115200):
pinPeripheral(3, PIO_SERCOM_ALT);
pinPeripheral(4, PIO_SERCOM_ALT);
```

SERCOM budget (from
[variant.cpp](https://github.com/adafruit/ArduinoCore-samd/blob/master/variants/pyportal_m4/variant.cpp)):
SERCOM2 = SPI (AirLift + microSD), SERCOM4 = `Serial1`/`SerialNina`
(ESP32 boot/BLE serial — **do not repurpose**), SERCOM5 = Wire (I2C
STEMMA). **Free: SERCOM0 (ours), SERCOM1, SERCOM3.** Note SERCOM1's pads
(PA16–PA19) are physically consumed by the TFT's 8-bit data bus, so
SERCOM3 is the only real spare. Pad math is from the SAMD51 datasheet mux
table — the Phase 1 loopback is the ground-truth verification.

## NEVER-connect list (one driver per line)

1. **XBee-to-USB adapter + JST pigtail simultaneously.** The adapter's
   FTDI is a second driver on F9P UART1 RX. u-center sessions happen with
   the pigtail unplugged (or wire 2 detached). Multiple *power* sources
   are sanctioned by ArduSimple; the prohibition is **data contention**.
2. **Top XBee socket stays empty** — UART2 is the future radio's. Its
   VCC pin is a 3.3 V/250 mA *output*; never feed power in.
3. **Do not power the Lite from a Pynt 3.3 V pin.** The Lite regulates
   its own 3.3 V from 5V_IN; the Pynt's 3.3 V rail already carries the
   SAMD51 + TFT + AirLift (see `power.md`).
4. ~~D3/D4 JST power pins: connect nothing until measured~~ — **measured
   2026-07-17: both read 5V** (`power.md` P1, confirmed in
   `bringup-log.md`). D4's VCC/GND pins are now the chosen power/ground
   source for the Lite; see the wire list above.

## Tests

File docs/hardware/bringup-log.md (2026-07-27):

# Bench Bring-Up Log

Working copy for the bench pass — fill in as you go, alongside
`checklists.md` (source of truth for *what* to check) and `wiring.md` /
`power.md` / `ucenter-config.md` (source of truth for *how*).

Date started: ____________  Date completed: ____________

---

## 1. simpleRTK2B Lite (ZED-F9P) — u-center re-verification

- [x] Physical inspection: JST-GH intact, SMA snug, no bent XBee pins
- [x] JST pin 1 located and marked on the pigtail
- [x] Top XBee socket confirmed empty
- [x] HC977 antenna mounted (hand-tight + 1/8 turn), sky view for fix tests
- [x] u-center connected via XBee-to-USB adapter, **pigtail unplugged**
- [x] Connection baud used: `115200` (Feather-era config took, as expected)
- [x] UBX-MON-VER recorded 2026-07-19 — **HPG 1.51, protver 27.50** —
      without u-center: the rover firmware now queries MON-VER over UART1
      at boot and prints it (`[gnss] ZED-F9P fw HPG 1.51 protver 27.50`).
      u-center can't connect while the Pynt drives UART1 (its USB adapter
      bridges the same port — README constraint 5), so this is the
      go-forward way to read the version.
- [x] **UART1 keys verified/set via VALGET→VALSET→VALGET (Flash-confirmed):**
      baud 115200 ✅; UBX in=1 ✅; NMEA in was **1→ fixed to 0** ✅;
      RTCM3X in=1 ✅; UBX out=1 ✅; NMEA out=1 ✅; RTCM3X out was
      **1→fixed to 0** ✅ (this is Rover — RTCM3X out belongs on UART2 in
      Base mode, not here)
- [x] **RAWX / SFRBX messages: both were 0→fixed to 1**, confirmed in Flash
      and visible live in the packet console (RAWX ~1/s, SFRBX bursting
      several/s — normal). TIM_TM2 left off (optional, not needed)
- [x] **NMEA set on UART1: GGA/RMC/GSA/GST/GSV all fixed 0→1**; VTG was
      briefly mis-queued to 1, corrected to 0; HIGHPREC=1 ✅ — all
      confirmed in Flash
- [x] **Rate: MEAS=1000ms ✅, NAV was unset in first pass → fixed to 1** —
      confirmed in Flash (true 1 Hz)
- [x] Dynamics = 0 (Portable) ✅ — already correct, no fix needed
- [x] **Elevation mask was 10°→fixed to 12°**; constellations
      GPS/GLONASS/Galileo/BeiDou all already =1 ✅; SBAS already =0 ✅;
      **QZSS was 1→fixed to 0** — all confirmed in Flash
- [x] UART2 left untouched (never queried/changed)
- [x] Saved to Flash (RAM+BBR+Flash checked on every VALSET)
- [x] **Power-cycled — all fixes survived reconnect at 115200.** VALGET
      re-check not repeated post-cycle (relying on pre-cycle Flash
      confirmations + successful reconnect at the configured baud)
- [x] Packet console reviewed live: RAWX (1/s) + SFRBX (bursty) + configured
      NMEA set all present. **One unaccounted extra: `NMEA-GNGLL` is on**
      (never in the checklist's target set) — harmless bandwidth-wise,
      left on by owner decision rather than spending another VALSET round
      trip; not a logging/protocol risk either way
- [ ] USB adapter not yet unplugged — **do this before wiring the pigtail
      to the Pynt** (data-contention rule in `wiring.md`)

**Section 1 status: CLOSED**, pending only the physical adapter-unplug
step before integration wiring begins.

Notes / anomalies:

- This Lite came over from the Feather rig "maybe already configured" —
  in practice it was **not** correctly configured for this project's
  Rover/RAWX-logging needs: RTCM3X-out and NMEA-in were both backwards
  (Base-mode-ish leftovers), RAWX/SFRBX logging was entirely off, and the
  elevation mask + QZSS were both off-target. The VALGET-first approach
  caught all of it before assuming "it probably still has the old config."
- `NMEA-GNGLL` chatter — see checklist line above. Revisit only if SD
  logging bandwidth ever becomes tight (unlikely per `platform.md`'s
  budget math).

---

## 2. PyPortal Pynt — bring-up sketch (`pio run -e pynt-bringup -t upload`)

- [ ] Bootloader confirmed (double-tap reset → `PORTALBOOT`); version recorded: `_______________`
- [ ] Bring-up firmware flashed, serial monitor open at 115200

**Power (multimeter, USB-powered, nothing wired to the Lite yet)**
- [x] P1 — D3 JST power pin voltage: `5` V
- [x] P1 — D4 JST power pin voltage: `5` V
- [x] P2 — I2C STEMMA 5V pin voltage: `5` V (want ~VBUS/5V) — confirmed

**`t` — TFT**
- [x] Three fills clean, no tearing; fill time recorded: `_______` ms (not recorded)
- [x] rotation 0 "UP^" points to: `USB connector side`
- [x] rotation 2 "UP^" points to: `JST connectors side`
- [x] **Chosen rotation for the build:** `2` (JST connectors up — matches planned cable exit)

**`p` — Touch (re-captured 2026-07-17 after the pin fix, rotation 2)**
- [x] Corner top-left (TL): x=825 y=835 z=250
- [x] Corner top-right (TR): x=157 y=849 z=500
- [x] Corner bottom-left (BL): x=837 y=130 z=1700
- [x] Corner bottom-right (BR): x=202 y=126 z=585
- [x] **Valid calibration constants — touch pin fix confirmed on hardware.**
      Note for Phase 2 `ui.cpp`: both axes read **inverted** vs. typical
      screen convention at rotation 2 — X is high-on-left/low-on-right
      (TL≈825→TR≈157), Y is high-on-top/low-on-bottom (TL≈835→BL≈130).
      Map/invert accordingly when converting raw touch to screen
      coordinates, don't assume a direct 0-at-top-left mapping.

**`w` / `W` — AirLift**
- [x] NINA firmware version: `_______________` (not recorded)
- [x] Hotspot SSID visible in scan
- [x] WiFi join succeeded
- [x] TCP echo test — connected, echo confirmed successful

**`s` — microSD**
- [x] Card formatted FAT32, init OK at SD_CS
- [ ] Latency histogram (bucket counts not recorded — only worst-case captured)
- [x] Worst single write: `93.6` ms

**`l` / `x` — D3/D4 label-swap**
- [x] Signal pins jumpered, loopback (`l`) = PASS
- [x] TX-identify (`x`) run (re-confirmed on retest): **physical socket D4 = steady 3.3V, physical socket D3 = 0V**
- [x] **Result: silkscreen IS swapped, as the forum reports warned.** UART TX
      idles high (3.3V) between the once-per-second byte writes — the pulse
      itself is a microsecond-scale burst a multimeter can't catch, so a
      steady 3.3V reading on the driven line is the *expected*, correct
      signature of TX, not a measurement failure. Firmware's `GNSS_TX_PIN`
      (Arduino pin 3) is physically brought out on the socket silkscreened
      **D4**; `GNSS_RX_PIN` (Arduino pin 4) is on the socket silkscreened
      **D3**.
- [x] **Sockets tape-labeled**: physical **D4 socket → TX**, physical **D3 socket → RX** (opposite of silkscreen). Use these tape labels, not the board printing, when wiring the Lite (`wiring.md` wire #2 goes to the tape-labeled TX socket, wire #3 from the tape-labeled RX socket).

**`r` — Free RAM**
- [x] Free-RAM low-water mark after all tests: `186008` bytes

Notes / anomalies:

- Touch (`p`): all four corners returned y=0, reproduced on a second run
  (not sampling noise). Traced into the Adafruit TouchScreen library
  (`getPoint()` in `TouchScreen.cpp`): with this constructor order
  (`TouchScreen ts(TOUCH_XL, TOUCH_YU, TOUCH_XR, TOUCH_YD, 300)`), X is read
  via `analogRead(TOUCH_YU)` (pin 19) and **Y is read via
  `analogRead(TOUCH_XR)` (pin 20 / PB08)**. Checked the pyportal_m4
  `variant.cpp` pin table directly — pin 20 is a genuine ADC-capable pin
  (`ADC_Channel2`, `PIN_ATTR_ANALOG`), so this is not a bad pin assignment
  in `pins.h`. X varies correctly across corners while Y pins to one rail
  every time, which is the classic signature of a **floating/disconnected
  analog input**, not a code or pin-mapping bug. Suspect the touch
  overlay's FPC/ribbon connector isn't fully seated, or a cold joint /
  broken trace on the lead that reaches pin 20 (PB08). **Next step is
  physical inspection** — reseat the touch panel's connector and check
  continuity from Arduino pin 20 to the touch overlay's X- lead — not a
  firmware change.
- TX-identify (`x`): re-confirmed on retest, same result both times — this
  is the correct, expected signature of TX (UART idles high; the
  once-per-second pulse is microseconds long and invisible to a
  multimeter). Silkscreen swap confirmed real; tape labels applied (see
  above). Not an anomaly — closed.

---

## 3. Integration gates (stop at any failure)

1. [x] Section 1 + Section 2 both fully healthy
2. [x] **All four wires connected at once** (per the D3/D4-sourced wiring
       in `wiring.md`: power+ground+TX off D4, RX off D3) rather than
       power-only first — Lite power LED on, Pynt unaffected
   - [x] P3 — voltage at Lite JST pin 1 under load (WiFi active, backlight
         full): **4.77 V** (≥ 4.5 V floor — comfortable margin)
   - [x] P4 — 30-min soak: **complete, no issues** (no brownout resets on
         either board)
3. [x] **Data union** (2026-07-19): `n` test shows live NMEA (`$GBGSV`,
       `$GNGLL`, `$GNGST`, etc.) in the Pynt console at 115200,
       interleaved with unreadable binary — **that binary is
       UBX-RXM-RAWX/SFRBX rendering as raw bytes in a text terminal,
       exactly as expected** since both are configured on for logging
       (section 1). Confirms both the NMEA and UBX binary paths are live,
       not a data-corruption signal.
4. [x] **1-hour full-stack soak**: NTRIP + logging + backlight running
       together, no resets, SD file confirmed growing — **PASS 2026-07-19**
       (66 min captured, details below)

**Section 3 status: all gates CLOSED (gate 4 soak PASS 2026-07-19).**

### Gate 4 runbook — 1-hour full-stack soak (`pynt-rover`)

**Software pre-flight (done 2026-07-19, no board attached):** bench touch
calibration + rotation 2 applied to `ui.cpp` from the section-2 'p'
values; both envs rebuild clean (rover RAM 9.7 % / flash 11.1 %). The two
remaining README bench items (`server.available()` semantics, bounded
`WiFi.begin()` stall) are runtime observations with mitigations already
in code — watch for them below, nothing to change beforehand.

**Setup (in order):**
- [x] u-center USB adapter physically unplugged from the Lite (wiring.md
      data-contention rule); wires 1-4 connected per the tape labels,
      antenna sky view, iPhone hotspot up
- [x] Credentials: `secrets.h` created from the example (wifi1/pass1 +
      caster user/password); macro names verified against settings.cpp
- [x] Flash + monitor: flashed over COM5; session captured by a pyserial
      logger with elapsed-time stamps + `status` injected every 10 min

**Watch during the hour (`status` every ~10 min):**
- [x] `ntrip=` reached connected at 00:20 and never dropped (zero
      `[ntrip]` error lines across the 66-min run)
- [x] `bytes=` grew monotonically 0.26 → 11.37 MB; `sd=ok` throughout,
      zero SD errors
- [x] `[main] worst loop` bounded: steady-state 32-50 ms; isolated ~1.1 s
      spikes (17:51, 23:51, 24:50 — SD/NINA ops, absorbed by design);
      first-minute 10.9 s = the blocking `WiFi.begin()` window. ⚠ That
      join measured **10.9 s, not the ~4 s the 4096 B SERCOM ring was
      sized for** — harmless at boot (logging hadn't started), but a
      mid-session WiFi rejoin would gap the RAWX stream. Carried forward.
- [x] TCP client streamed NMEA (laptop test client). **Two findings**,
      both recorded in QUESTIONS.md Q19: nina-fw accept is data-gated
      (a listen-only client sits unaccepted until it sends ≥1 byte —
      confirmed live), and the dedup in `tcp_nmea.cpp` compared clients
      via operator-bool (fork has no operator==), so only the first
      client could ever be accepted — fixed and flashed post-soak.
- [x] Touch: LOG / PAGE / PWR buttons all functioned correctly
      (2026-07-19, owner-verified) — **bench 4-corner calibration +
      inverted-axis mapping confirmed good on hardware**
- [x] No resets: **zero boot banners** in the log, per-minute reports
      continuous, `bytes=` never restarted

**Record at the end:**
- [x] Duration: `66` min captured; resets: `0`
- [x] Final `.ubx` size: `11,365,704` B (~10.3 MB/h — the runbook's
      1.5-2.5 MB/h sanity guess was far low for 32-SV multi-band RAWX;
      still only ~0.25 GB/day against a 32 GB card, no concern)
- [x] RTK fix achieved: `yes` — carr=2 by the 02:01 status and held to
      66:04 (TTFF < 2 min from cold boot including hotspot join)
- [x] Worst loop over the hour: `10.9 s` (boot WiFi join); `1.1 s`
      steady-state peak. `BUFH` not captured — `status` doesn't print
      it (SYS TFT page only); read it on-screen next bench sit
- [x] Post-soak: `.ubx` parse **verified 2026-07-19** — the original
      soak file was lost to the SD corruption (unsafe eject), so a fresh
      4-min capture (`r_054749.ubx`, 823 KB, closed cleanly via
      `log off`) was played back in u-center: RAWX 1688-1720 B at 1 Hz
      (~30 SV multi-band) + SFRBX bursts, all well-formed. The clean
      close → clean read also supports the unsafe-eject theory for the
      earlier corruption.

**Base-mode spot check (Phase 3 close-out, after the rover soak passes):**
- [x] **PASS 2026-07-19** — `mode=base` via serial menu applied live
      (`[gnss] applying mode: base` within 1 s); survey-in ran a
      textbook convergence, 9.16 m → 1.46 m mean accuracy, **valid at
      exactly dur=300 s** (the svindur/svinacc defaults); `mode=rover`
      switched back live and re-applied cleanly. UART2/XBee socket
      stayed empty throughout (config-only rule).
      One gap found: the **`b_` log prefix did not appear** — the
      prefix is chosen only at file open and nothing rotated the log on
      a live mode switch, so the boot-time `r_` file kept collecting.
      Fixed same day (serial_menu.cpp cycles the logger on a `mode=`
      change) and flashed; rotation itself not yet re-verified on
      hardware — one-minute check next bench sit: `mode=base`, confirm
      `[sd] logging to /YYYYMMDD/b_*.ubx`, `mode=rover`.

Notes / anomalies:

- Wiring was done as a single four-wire pass rather than the
  power-only-then-data sequencing the gate list originally implied.
  Retroactively confirmed both P3/P4 (power) and the data path are
  healthy, so no re-work needed — just noting the actual order for
  anyone reading this log later.
- **First soak attempt aborted at ~2 min (2026-07-19):** NTRIP TCP
  connect failed repeatedly — root cause was not the firmware but DNS:
  the inherited caster hostname `acorn-gnss.net` no longer has an A
  record at the apex (provider change since the Metro era); only
  `www.acorn-gnss.net` resolves (verified listening on :2101 from the
  bench PC before switching). Default fixed in `settings.h`, README +
  QUESTIONS.md Q6 note updated, reflashed, soak restarted clean.
- **Host-side USB stall, minutes ~30 → 55:14:** no serial delivered to
  the logging PC for ~25 min, then everything arrived in one burst (all
  lines stamped 55:14) and the three queued `status` commands were
  answered on arrival. The device itself never blinked: per-minute
  worst-loop reports all present with normal values, SD bytes grew
  continuously, NTRIP never reconnected, fix unchanged. Attributed to
  Windows USB suspend/driver buffering, not firmware. Post-recovery
  statuses (62:01, 66:04) arrived on schedule.
- **Soak binary note:** the hour ran the pre-dedup-fix `tcp_nmea.cpp`
  (the operator== bug was found mid-soak); the fixed binary was flashed
  immediately after the soak ended, before the base-mode spot check.

---

## Field notes (operational, learned on the bench)

- **SD card must be inserted before power-on.** `sd.begin()` runs once
  at boot with no retry — a hot-inserted card is never initialized
  (no logging, no /config.txt, SYS page shows SD FAIL) until a power
  cycle. Corollary of the same design: safe-eject is PWR two-tap (or
  `log off`) *before* pulling the card. Hot-insert retry is a Phase 4
  candidate if this ever bites in the field.

## Open items carried forward (2026-07-19, post-soak)

- ~~**iOS phone app** (QUESTIONS.md Q19)~~ **CLOSED 2026-07-19: QField
  connected and streamed on the first try** — it sends on connect, so
  the data-gated accept is satisfied. QField is the v1 phone app.
- ~~**`WiFi.begin()` blocks ~10.9 s**~~ **CLOSED 2026-07-19:
  SERIAL_BUFFER_SIZE raised 4096 → 32768 (~13 s of F9P output) — a
  mid-session rejoin no longer gaps the RAWX stream.
- ~~**Touch buttons unverified**~~ **CLOSED 2026-07-19: all three
  buttons function correctly** (owner-verified). **BUFH read
  2026-07-19: typically 9,000-14,000 B** against the 32,768 B SparkFun
  file buffer — ~43 % peak occupancy, comfortably inside the
  platform.md contention budget. Closed.
- **RINEX conversion verified (convbin, demo5 v2.5.1)**: the 823 KB
  capture converted to RINEX 3.04 with **304 obs epochs in a 304 s
  span — zero dropped epochs at 1 Hz** — dual-frequency on all four
  constellations (G L1C/L2X, R L1/L2, E E1/E5b, C B1I/B2I) + 38 nav
  messages, with NTRIP + TCP server running concurrently during the
  capture. The logging pipeline is post-processing-grade.
- **SD card read back corrupted on the PC (2026-07-19)** after the
  first full bench day; reformatted (keep FAT32) and lost the soak
  `.ubx`. Most likely cause: card pulled while the device was powered
  with a log file open — logging auto-starts whenever GNSS time is
  valid, and the logger syncs on an 8 s cadence, so a pull can land
  mid-write and damage the FAT. **Safe-eject procedure: PWR two-tap →
  wait for "SAFE TO POWER OFF" → cut power → then pull the card.**
  (LOG-button off also closes the file, but shutdown is the guarantee.)
  Watch for recurrence with the procedure followed — if it corrupts
  again on a clean shutdown, suspect the card itself (PNY U1) and
  retest with a fresh card before blaming the SPI path. **Follow-up
  same day: post-reformat 4-min capture closed with `log off` read back
  perfectly in u-center — consistent with unsafe eject, not a bad card.**
- ~~**`b_` prefix rotation fix flashed but not re-verified**~~ **CLOSED
  2026-07-19**: re-check session confirmed `mode=base` closes the `r_`
  file and opens `b_045917.ubx`, and `mode=rover` rotates back. Same
  session verified the MON-VER boot report (HPG 1.51 / 27.50) and the
  new `ip=` status + SYS-page IP:port display, and exercised the NTRIP
  retry path live (5 rejects at boot → connected → stable).
- **Post-soak `.ubx` sanity**: eject the card, open
  `/20260720/r_031723.ubx` (10.8 MB soak log) on the laptop — RTKLIB or
  u-center should parse RAWX/SFRBX cleanly.

## Open items carried forward

(anything discovered during bring-up that needs a QUESTIONS.md entry or a doc update)

- **Touch Y-axis stuck at 0** (see note in section 2). Initial suspicion
  (library senses Y via `analogRead(TOUCH_XR)`, pin 20/PB08) was corrected
  by the new `y` raw-pin diagnostic test (`main_bringup.cpp`,
  `testTouchRawDump()`), which drives each axis and reads both
  opposite-axis electrodes at once instead of trusting the library's
  single-sense-pin math.
  **Result (two live captures, unpressed vs pressed):**
  unpressed `YU≈717 YD≈7 | XL≈459 XR≈450`; pressed
  `YU≈140 YD≈2-8 | XL≈1023 XR≈1017-1023`. YU tracks touch correctly
  (matches the already-good X readings). **YD stays flat near 0 in both
  states, and — the key signal — both XL *and* XR jump to ~1023 together
  the instant of touch instead of settling at a graded value.** Both sense
  pins pinning high together under touch (not just one) means the fault is
  on the **drive/ground side, not a sense pin**: Y-phase drives YU=HIGH,
  YD=LOW to form the gradient, and if YD isn't making a good low-reference
  connection, any touch just pulls toward the healthy HIGH (YU) side
  instead of a real graded voltage — exactly this signature.
  **ROOT CAUSE FOUND — not a hardware fault at all.** Pulled Adafruit's
  official "Adafruit PyPortal Pynt Pinout.pdf"
  (github.com/adafruit/Adafruit-PyPortal-PCB) and cross-checked against
  `pins.h`. The chip ports were right (PB00/PB01/PA06/PB08) but every
  touch pin's **Arduino number was off by exactly one**:

  | Signal | Official pin | `pins.h` had |
  |---|---|---|
  | TOUCH_YD (PB00) | 18 | 17 |
  | TOUCH_XL (PB01) | 19 | 18 |
  | TOUCH_YU (PA06) | 20 | 19 |
  | TOUCH_XR (PB08) | 21 | 20 |

  So `TOUCH_YD` was actually driving whatever's really on pin 17 (not the
  touch panel), which explains everything: driving "YD" LOW never
  established a real ground reference for the Y-axis gradient, so any
  touch just pulled the sense pins toward the healthy HIGH side — exactly
  the both-pins-jump-to-1023 signature the `y` test caught. "X" looked
  fine because pins.h's `TOUCH_YU` (19) is really the panel's XL
  electrode — still a genuine touch electrode, so it happened to produce
  plausible-looking numbers by coincidence.
  **Fix applied 2026-07-17:** both `firmware/pynt/bringup/pins.h` and
  `firmware/pynt/rover/pins.h` corrected to 18/19/20/21. Both environments
  rebuild clean.
  **CONFIRMED FIXED ON HARDWARE 2026-07-17.** Re-flashed `pynt-bringup`,
  re-ran `p`: y now varies across the full range with touch position
  (observed x=298-829, y=123-878, z=209-1998 across several presses) —
  no longer pinned. **Closed.**

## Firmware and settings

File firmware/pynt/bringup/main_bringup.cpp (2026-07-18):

// PyPortal-Pynt-RTK — Phase 1 bring-up test suite
//
// Serial-menu bench tool covering every item in
// docs/hardware/checklists.md ("PyPortal Pynt" section). Each test prints
// PASS-looks-like guidance so the checklist can be worked top to bottom.
//
// Ancestry: structure follows RTK-Feather's per-board bring-up sketches;
// the GNSS UART recipe is docs/hardware/wiring.md's SERCOM0 mapping.

#include <Arduino.h>
#include <wiring_private.h>  // pinPeripheral()
#include <Adafruit_GFX.h>
#include <Adafruit_ILI9341.h>
#include <TouchScreen.h>
#include <WiFiNINA.h>
#include <SdFat.h>

#include "pins.h"
#if __has_include("secrets.h")
#include "secrets.h"
#define HAVE_SECRETS 1
#else
#define HAVE_SECRETS 0
#endif

// ---- GNSS UART on SERCOM0: TX=D3(PA04,pad0) RX=D4(PA05,pad1) ----
Uart SerialGNSS(&sercom0, GNSS_RX_PIN, GNSS_TX_PIN,
                SERCOM_RX_PAD_1, UART_TX_PAD_0);
void SERCOM0_0_Handler() { SerialGNSS.IrqHandler(); }
void SERCOM0_1_Handler() { SerialGNSS.IrqHandler(); }
void SERCOM0_2_Handler() { SerialGNSS.IrqHandler(); }
void SERCOM0_3_Handler() { SerialGNSS.IrqHandler(); }

static void gnssUartBegin() {
  SerialGNSS.begin(GNSS_BAUD);
  pinPeripheral(GNSS_TX_PIN, PIO_SERCOM_ALT);
  pinPeripheral(GNSS_RX_PIN, PIO_SERCOM_ALT);
}

Adafruit_ILI9341 tft(tft8bitbus, TFT_D0, TFT_WR, TFT_DC, TFT_CS,
                     TFT_RST, TFT_RD);
// Electrode polarity is a convention guess (pins.h) — 'p' test validates.
TouchScreen ts(TOUCH_XL, TOUCH_YU, TOUCH_XR, TOUCH_YD, 300);
SdFat sd;

static bool tftUp = false;

extern "C" char *sbrk(int);
static int freeRam() {
  char top;
  return &top - reinterpret_cast<char *>(sbrk(0));
}

static bool keyPressed() {  // drains and reports any pending USB input
  bool hit = false;
  while (Serial.available()) { Serial.read(); hit = true; }
  return hit;
}

// ---------------------------------------------------------------- tests

static void testTft() {
  Serial.println(F("[t] TFT: init + fills + both portrait rotations"));
  pinMode(TFT_BACKLIGHT, OUTPUT);
  digitalWrite(TFT_BACKLIGHT, HIGH);
  if (!tftUp) { tft.begin(); tftUp = true; }
  uint32_t t0 = millis();
  tft.fillScreen(ILI9341_RED);
  tft.fillScreen(ILI9341_GREEN);
  tft.fillScreen(ILI9341_BLUE);
  Serial.print(F("  three full fills took ")); Serial.print(millis() - t0);
  Serial.println(F(" ms (parallel bus datum for platform.md)"));
  static const uint8_t kPortraitRotations[2] = {0, 2};
  for (uint8_t r : kPortraitRotations) {
    tft.setRotation(r);   // the two portrait candidates (240x320)
    tft.fillScreen(ILI9341_BLACK);
    tft.setTextColor(ILI9341_WHITE);
    tft.setTextSize(3);
    tft.setCursor(10, 10);
    tft.print(F("rot "));
    tft.print(r);
    tft.setCursor(10, 50);
    tft.print(F("UP^"));
    Serial.print(F("  rotation ")); Serial.print(r);
    Serial.println(F(": note which physical edge 'UP^' points to"));
    delay(2500);
  }
  Serial.println(F("  PASS = clean fills, readable text, no tearing."));
  Serial.println(F("  Record the rotation whose UP matches the planned cable exit."));
}

static void testTouchDump() {
  Serial.println(F("[p] touch raw dump — press corners; any serial key exits"));
  while (!keyPressed()) {
    TSPoint p = ts.getPoint();
    if (p.z > 100) {  // crude pressure gate
      Serial.print(F("  x=")); Serial.print(p.x);
      Serial.print(F(" y=")); Serial.print(p.y);
      Serial.print(F(" z=")); Serial.println(p.z);
    }
    delay(50);
  }
  Serial.println(F("  Record 4-corner raw values in checklists.md."));
}

// Bypasses the TouchScreen library's math entirely. The library computes Y
// by driving YU/YD and sensing only through XR (pins.h TOUCH_XR) — if that
// single sense pin is bad, Y reads stuck regardless of the drive pins'
// health. This test drives each axis and reads BOTH opposite-axis
// electrodes at once, so a dead sense pin shows up next to a live one
// under the *same* drive condition — isolating sense-pin vs drive-pin
// faults instead of just reporting the library's already-broken output.
static void testTouchRawDump() {
  Serial.println(F("[y] touch raw pin diagnostic — press/drag around the panel; any serial key exits"));
  Serial.println(F("  Xdrive senses YU+YD (both should move together as you slide X)"));
  Serial.println(F("  Ydrive senses XL+XR (both should move together as you slide Y)"));
  Serial.println(F("  A pin stuck near 0 or 1023 while its neighbor moves = that pin/node is dead"));
  while (!keyPressed()) {
    // --- X-drive phase: drive XL/XR, sense YU and YD together ---
    pinMode(TOUCH_YU, INPUT);
    pinMode(TOUCH_YD, INPUT);
    pinMode(TOUCH_XL, OUTPUT);
    pinMode(TOUCH_XR, OUTPUT);
    digitalWrite(TOUCH_XL, HIGH);
    digitalWrite(TOUCH_XR, LOW);
    delayMicroseconds(20);
    int yu = analogRead(TOUCH_YU);
    int yd = analogRead(TOUCH_YD);

    // --- Y-drive phase: drive YU/YD, sense XL and XR together ---
    pinMode(TOUCH_XL, INPUT);
    pinMode(TOUCH_XR, INPUT);
    pinMode(TOUCH_YU, OUTPUT);
    pinMode(TOUCH_YD, OUTPUT);
    digitalWrite(TOUCH_YU, HIGH);
    digitalWrite(TOUCH_YD, LOW);
    delayMicroseconds(20);
    int xl = analogRead(TOUCH_XL);
    int xr = analogRead(TOUCH_XR);

    Serial.print(F("  Xdrive: YU=")); Serial.print(yu);
    Serial.print(F(" YD=")); Serial.print(yd);
    Serial.print(F("   |   Ydrive: XL=")); Serial.print(xl);
    Serial.print(F(" XR=")); Serial.println(xr);
    delay(200);
  }
}

static bool wifiPinsSet = false;
static void wifiEnsurePins() {
  if (!wifiPinsSet) {
    WiFi.setPins(SPIWIFI_SS, SPIWIFI_ACK, ESP32_RESETN, ESP32_GPIO0,
                 &SPIWIFI);
    wifiPinsSet = true;
  }
}

static void testWifiVersionScan() {
  Serial.println(F("[w] AirLift: firmware version + scan"));
  wifiEnsurePins();
  if (WiFi.status() == WL_NO_MODULE) {
    Serial.println(F("  FAIL: no module — check SPIWIFI pin set (pins.h)"));
    return;
  }
  Serial.print(F("  NINA firmware: "));
  Serial.println(WiFi.firmwareVersion());
  Serial.println(F("  (want >= 1.7.7 per checklists.md)"));
  int n = WiFi.scanNetworks();
  Serial.print(F("  networks: ")); Serial.println(n);
  for (int i = 0; i < n && i < 10; i++) {
    Serial.print(F("   ")); Serial.print(WiFi.SSID(i));
    Serial.print(F("  ")); Serial.print(WiFi.RSSI(i));
    Serial.println(F(" dBm"));
  }
}

static void testWifiJoinEcho() {
#if !HAVE_SECRETS
  Serial.println(F("[W] needs secrets.h (copy secrets.example.h)"));
#else
  Serial.println(F("[W] join + TCP echo server on :10110 (any key exits)"));
  wifiEnsurePins();
  Serial.print(F("  joining ")); Serial.println(WIFI_SSID);
  if (WiFi.begin(WIFI_SSID, WIFI_PASS) != WL_CONNECTED) {
    for (int i = 0; i < 20 && WiFi.status() != WL_CONNECTED; i++) delay(500);
  }
  if (WiFi.status() != WL_CONNECTED) {
    Serial.println(F("  FAIL: no join"));
    return;
  }
  Serial.print(F("  IP: ")); Serial.println(WiFi.localIP());
  Serial.println(F("  from a laptop on the same hotspot: nc <ip> 10110"));
  WiFiServer server(10110);
  server.begin();
  while (!keyPressed()) {
    WiFiClient client = server.available();
    if (client && client.available()) {
      String line = client.readStringUntil('\n');
      client.print(F("echo: "));
      client.println(line);
      Serial.print(F("  echoed: ")); Serial.println(line);
    }
  }
  WiFi.disconnect();
  Serial.println(F("  done (proves the SW Maps TCP path)"));
#endif
}

static void testSdLatency() {
  Serial.println(F("[s] SD: init + 4 MB append test + latency histogram"));
  if (!sd.begin(SD_CS, SD_SCK_MHZ(12))) {
    Serial.println(F("  FAIL: init — card seated? FAT32?"));
    return;
  }
  sd.remove("bringup.bin");
  FsFile f = sd.open("bringup.bin", O_WRONLY | O_CREAT);
  if (!f) { Serial.println(F("  FAIL: open")); return; }
  static uint8_t buf[512];
  for (size_t i = 0; i < sizeof buf; i++) buf[i] = (uint8_t)i;
  // buckets (ms): <1, 1-5, 5-10, 10-50, 50-100, 100-250, >250
  uint32_t bucket[7] = {0};
  uint32_t worstUs = 0;
  const uint32_t kWrites = 8192;  // 4 MiB
  for (uint32_t i = 0; i < kWrites; i++) {
    uint32_t t0 = micros();
    if (f.write(buf, sizeof buf) != sizeof buf) {
      Serial.print(F("  FAIL: short write at ")); Serial.println(i);
      f.close();
      return;
    }
    uint32_t dt = micros() - t0;
    if (dt > worstUs) worstUs = dt;
    uint32_t ms = dt / 1000;
    bucket[ms < 1 ? 0 : ms < 5 ? 1 : ms < 10 ? 2 : ms < 50 ? 3
           : ms < 100 ? 4 : ms < 250 ? 5 : 6]++;
  }
  f.close();
  static const char *label[7] = {"<1ms", "1-5", "5-10", "10-50", "50-100",
                                 "100-250", ">250ms"};
  for (int i = 0; i < 7; i++) {
    Serial.print(F("  ")); Serial.print(label[i]);
    Serial.print(F(": ")); Serial.println(bucket[i]);
  }
  Serial.print(F("  worst single write: "));
  Serial.print(worstUs / 1000.0f, 1);
  Serial.println(F(" ms — feed this into platform.md's buffer math"));
}

static void testUartLoopback() {
  Serial.println(F("[l] UART loopback — jumper the two D3/D4 JST SIGNAL pins"));
  gnssUartBegin();
  while (SerialGNSS.available()) SerialGNSS.read();
  const char pattern[] = "PYNT-RTK-LOOPBACK-0123456789";
  SerialGNSS.print(pattern);
  SerialGNSS.flush();
  delay(50);
  char rx[sizeof pattern] = {0};
  size_t n = 0;
  while (SerialGNSS.available() && n < sizeof pattern - 1)
    rx[n++] = (char)SerialGNSS.read();
  if (n == sizeof pattern - 1 && memcmp(rx, pattern, n) == 0) {
    Serial.println(F("  PASS: pattern echoed intact at 115200"));
    Serial.println(F("  SERCOM0 recipe verified (QUESTIONS.md Q10 closed)"));
  } else {
    Serial.print(F("  FAIL: got ")); Serial.print(n);
    Serial.println(F(" bytes — jumper on? right sockets? (label swap!)"));
  }
}

static void testTxIdentify() {
  Serial.println(F("[x] TX identify: 1 Hz pulses on the TX line (any key exits)"));
  Serial.println(F("  probe each JST signal pin; the pulsing one is TX -> tape-label it"));
  gnssUartBegin();
  while (!keyPressed()) {
    SerialGNSS.write((uint8_t)0x55);  // brief edge burst
    SerialGNSS.flush();
    delay(1000);
  }
}

static void testNmeaEcho() {
  Serial.println(F("[n] NMEA echo from the F9P (wires 2+3 connected; any key exits)"));
  gnssUartBegin();
  uint32_t bytes = 0, lines = 0, t0 = millis();
  while (!keyPressed()) {
    while (SerialGNSS.available()) {
      char c = (char)SerialGNSS.read();
      Serial.write(c);
      bytes++;
      if (c == '\n') lines++;
    }
    if (millis() - t0 >= 5000) {
      Serial.print(F("\r\n  [")); Serial.print(bytes / 5);
      Serial.print(F(" B/s, ")); Serial.print(lines / 5);
      Serial.println(F(" lines/s]"));
      bytes = lines = 0;
      t0 = millis();
    }
  }
}

static void reportRam() {
  Serial.print(F("[r] free RAM: "));
  Serial.print(freeRam());
  Serial.println(F(" bytes (record the low-water mark after other tests)"));
}

static void menu() {
  Serial.println();
  Serial.println(F("== PyPortal-Pynt-RTK bring-up (docs/hardware/checklists.md) =="));
  Serial.println(F(" t  TFT fills + portrait rotations"));
  Serial.println(F(" p  touch raw dump"));
  Serial.println(F(" y  touch raw PIN diagnostic (isolates dead pin)"));
  Serial.println(F(" w  AirLift version + scan"));
  Serial.println(F(" W  WiFi join + TCP echo :10110 (needs secrets.h)"));
  Serial.println(F(" s  SD 4MB write + latency histogram"));
  Serial.println(F(" l  UART loopback (D3-D4 jumpered)"));
  Serial.println(F(" x  TX-socket identify pulses"));
  Serial.println(F(" n  live NMEA echo from F9P"));
  Serial.println(F(" r  free-RAM report"));
  Serial.println(F(" ?  this menu"));
}

void setup() {
  Serial.begin(115200);
  uint32_t t0 = millis();
  while (!Serial && millis() - t0 < 4000) {}
  menu();
}

void loop() {
  if (!Serial.available()) return;
  char c = (char)Serial.read();
  while (Serial.available()) Serial.read();  // drain CR/LF
  switch (c) {
    case 't': testTft(); break;
    case 'p': testTouchDump(); break;
    case 'y': testTouchRawDump(); break;
    case 'w': testWifiVersionScan(); break;
    case 'W': testWifiJoinEcho(); break;
    case 's': testSdLatency(); break;
    case 'l': testUartLoopback(); break;
    case 'x': testTxIdentify(); break;
    case 'n': testNmeaEcho(); break;
    case 'r': reportRam(); break;
    case '\r': case '\n': break;
    default: menu(); break;
  }
}

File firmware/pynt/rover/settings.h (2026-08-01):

// Device configuration. Descended from RTK-Feather's settings.h; the
// persistence mechanism changes with the hardware: the Pynt has its own
// microSD, so the Metro "SD /config.txt" mechanism (which the Feather
// couldn't host) comes back — /config.txt on the card is the store, with
// an optional compiled-in secrets.h seed for bench work. No locks: the
// single superloop means the serial menu and every reader share a thread.
#pragma once
#include <Arduino.h>

#include "features.h"  // ENABLE_WEB_CONFIG / FEATURE_BLE gate fields below

constexpr int kMaxWifiNetworks = 4;

enum class DeviceMode : uint8_t { Rover = 0, Base = 1 };

struct Settings {
  // --- WiFi (tried in order) ---
  char wifiSsid[kMaxWifiNetworks][33] = {{0}};
  char wifiPass[kMaxWifiNetworks][65] = {{0}};

  // --- NTRIP caster --- defaults inherited from Metro via Feather.
  // 2026-07-19: the bare apex lost its DNS A record (provider change) —
  // only www. resolves now; verified listening on :2101 before switching.
  char casterHost[65] = "www.acorn-gnss.net";
  uint16_t casterPort = 2101;
  char casterMount[49] = "VRS_SouthCentral_RTCM3";  // alt: MS_RTCM3
  char casterUser[49] = {0};  // never defaulted — see secrets.example.h
  char casterPass[49] = {0};
  uint16_t ggaPeriodS = 10;

  // --- Mode ---
  DeviceMode mode = DeviceMode::Rover;

  // --- Base mode (Phase 3) --- survey-in by default; a nonzero
  // fixedLat/fixedLon switches to fixed-position TMODE.
  uint16_t svinMinDurS = 300;        // CFG-TMODE-SVIN_MIN_DUR
  uint32_t svinAccLimit01mm = 50000; // CFG-TMODE-SVIN_ACC_LIMIT, 0.1 mm units (50000 = 5 m)
  double fixedLatDeg = 0;            // 0 = use survey-in
  double fixedLonDeg = 0;
  double fixedAltM = 0;              // ellipsoidal height for CFG-TMODE-HEIGHT

  // --- GNSS ---
  uint8_t elevMaskDeg = 12;  // inherited Metro answer

  // --- Logging / phone link ---
  bool logUbx = true;       // log from boot; the LOG touch button toggles
  uint16_t tcpPort = 10110; // SW Maps NMEA server port

#if FEATURE_BLE
  // --- BLE NUS (coex stack only) ---
  bool bleEnable = true;
  char bleName[25] = "PyntRTK-rover";
#endif

#if ENABLE_WEB_CONFIG
  // --- Web config GUI (coex stack only; docs/web-config-spike.md) ---
  bool webEnable = true;      // STA server always-on while surveying
  uint16_t webPort = 80;
  char hostname[33] = "pynt-rtk";   // DHCP hostname (WiFi.setHostname)
  char adminPass[17] = {0};   // empty = generate at first web boot (TRNG),
  char apPass[17] = {0};      // shown on the TFT WEB page; web System card
                              // can change them. Never hardcoded defaults.
  bool bootAp = false;        // one-shot: enter AP provisioning at next boot.
                              // Set+saved by the TFT AP button, cleared at
                              // boot before entering AP. Both AP transitions
                              // are reboots: the NINA's socket table doesn't
                              // survive WiFi.end() honestly (bench 2026-07-31
                              // — leaked socks starve getSocket, bind fails,
                              // phantom-accept storm), so AP mode only ever
                              // starts on a freshly reset module.
  // --- GNSS knobs surfaced by the W3 card (keys parsed + persisted now;
  // gnss_config consumption lands with W3 — flagged in the plan) ---
  uint8_t measRateHz = 1;     // CFG-RATE-MEAS (1..5 sane on F9P all-const)
  uint8_t dynModel = 0;       // CFG-NAVSPG-DYNMODEL (0=portable,2,3,4..)
  bool nmeaGsv = true;        // GSV on UART1 (the bandwidth knob)
#endif
};

extern Settings g_settings;

void settingsLoad();   // SD /config.txt -> g_settings (secrets.h seeds bench defaults)
bool settingsSave();   // g_settings -> SD /config.txt (false if no card)
void settingsPrint(Stream& out);  // passwords masked
bool settingsApplyKeyValue(const char* key, const char* value);

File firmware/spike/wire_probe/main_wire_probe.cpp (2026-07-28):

// Wire probe for the HUZZAH32-as-nina rig (coex-bench Appendix A.2).
// Flash to the M0 when the soak reports "nina module not responding":
// re-runs a pin-by-pin diagnosis every 5 s (wiggle wires and watch).
//
// What each stage proves, using nina-fw/Arduino_SpiNINA's own
// choreography (READY idles LOW when the slave is armed; the slave
// drives READY HIGH within ~5 ms of CS asserting — spi_drv.cpp
// spiSlaveSelect — and while processing a command):
//   1. boot trace   — RESET wire + module boot (READY HIGH during boot,
//                     LOW once nina-fw arms its SPI slave)
//   2. CS ack       — CS wire + READY wire (READY reacts to CS edge)
//   3. fw version   — SCK, MOSI, MISO wires (bit-banged GET_FW_VERSION,
//                     expect E0 B7 ... "3.0.1" back)
// Pins come from the same -D set as the soak env; SPI pins are the M0's
// hardware SPI header, driven as plain GPIOs (bit-bang, ~50 kHz).
#include <Arduino.h>

#ifndef SPIWIFI_SS
#error "build via the feather-wire-probe env (-D pin set)"
#endif

namespace {

constexpr uint8_t PIN_CS = SPIWIFI_SS;
constexpr uint8_t PIN_READY = SPIWIFI_ACK;
constexpr uint8_t PIN_RST = SPIWIFI_RESET;
constexpr uint8_t PIN_SCK_BB = PIN_SPI_SCK;
constexpr uint8_t PIN_MOSI_BB = PIN_SPI_MOSI;
constexpr uint8_t PIN_MISO_BB = PIN_SPI_MISO;

uint8_t xfer(uint8_t out) {
  uint8_t in = 0;
  for (int8_t b = 7; b >= 0; b--) {
    digitalWrite(PIN_MOSI_BB, (out >> b) & 1);
    delayMicroseconds(4);
    digitalWrite(PIN_SCK_BB, HIGH);  // slave samples MOSI on this edge
    delayMicroseconds(4);
    in = (uint8_t)((in << 1) | digitalRead(PIN_MISO_BB));
    digitalWrite(PIN_SCK_BB, LOW);
  }
  return in;
}

bool waitReady(bool level, uint32_t timeoutMs) {
  uint32_t t0 = millis();
  while (digitalRead(PIN_READY) != (level ? HIGH : LOW)) {
    if (millis() - t0 > timeoutMs) return false;
  }
  return true;
}

void probe() {
  Serial.println(F("---- probe pass ----"));

  // 1. reset + boot trace
  digitalWrite(PIN_CS, HIGH);
  digitalWrite(PIN_RST, LOW);
  delay(10);
  digitalWrite(PIN_RST, HIGH);
  uint32_t t0 = millis();
  int last = digitalRead(PIN_READY);
  Serial.print(F("[1] READY at reset: "));
  Serial.println(last ? F("HIGH") : F("LOW"));
  uint8_t transitions = 0;
  while (millis() - t0 < 2500 && transitions < 8) {
    int now = digitalRead(PIN_READY);
    if (now != last) {
      Serial.print(F("    t="));
      Serial.print(millis() - t0);
      Serial.print(F("ms -> "));
      Serial.println(now ? F("HIGH") : F("LOW"));
      last = now;
      transitions++;
    }
  }
  if (digitalRead(PIN_READY) == LOW)
    Serial.println(F("[1] PASS: READY idles LOW (module armed)"));
  else {
    Serial.println(F("[1] FAIL: READY not LOW after boot — READY wire"
                     " (D11 -> \"33\") or RESET wire (D12 -> \"RST\")"));
    return;  // later stages meaningless
  }

  // 2. CS ack: nina-fw attaches a FALLING interrupt on CS (GPIO5, internal
  // pullup) that drives READY HIGH immediately — authoritative CS-wire test
  digitalWrite(PIN_CS, LOW);
  bool ack = waitReady(true, 5);
  digitalWrite(PIN_CS, HIGH);
  if (ack) Serial.println(F("[2] PASS: READY acks CS (CS + READY wires good)"));
  else {
    Serial.println(
        F("[2] FAIL: no READY reaction to CS — CS wire (D13 -> \"SCK\"/GPIO5)"));
    // 2b. beacon: toggle CS for 4 s so the wire can be found physically.
    // If the HUZZAH32's red LED blinks now, the wire sits on its "13"
    // pin (GPIO13 = LED) — move it to "SCK". A multimeter on the "SCK"
    // pin should read ~1.6 V avg while this runs (steady 3.3 V = wire
    // not arriving; that's the chip's internal pullup).
    Serial.println(F("[2b] CS beacon 4 s — watch the HUZZAH32 red LED /"
                     " meter the \"SCK\" pin"));
    uint32_t bEnd = millis() + 4000;
    while (millis() < bEnd) {
      digitalWrite(PIN_CS, LOW);
      delay(20);
      digitalWrite(PIN_CS, HIGH);
      delay(20);
    }
  }

  // 3. GET_FW_VERSION (0x37) via bit-bang, SpiDrv choreography. Runs even
  // after a [2] FAIL — the real driver also proceeds past its 5 ms ack
  // timeout, and the result adds signal either way.
  {
    digitalWrite(PIN_CS, LOW);
    waitReady(true, 5);
    uint8_t junk[4];
    const uint8_t cmd[4] = {0xE0, 0x37, 0x00, 0xEE};
    for (uint8_t i = 0; i < 4; i++) junk[i] = xfer(cmd[i]);
    digitalWrite(PIN_CS, HIGH);
    if (!waitReady(false, 1000)) {
      Serial.println(F("[3] FAIL: READY never re-armed after command"));
      return;
    }
    digitalWrite(PIN_CS, LOW);
    if (!waitReady(true, 5)) { /* ack again; tolerate */ }
    uint8_t rsp[24];
    for (uint8_t i = 0; i < sizeof(rsp); i++) rsp[i] = xfer(0xFF);
    digitalWrite(PIN_CS, HIGH);

    Serial.print(F("[3] response:"));
    for (uint8_t i = 0; i < sizeof(rsp); i++) {
      Serial.print(' ');
      Serial.print(rsp[i], HEX);
    }
    Serial.println();
    bool sawStart = false;
    for (uint8_t i = 0; i + 1 < sizeof(rsp); i++) {
      if (rsp[i] == 0xE0 && rsp[i + 1] == 0xB7) {
        sawStart = true;
        Serial.print(F("[3] PASS: nina-fw answered; version bytes: "));
        for (uint8_t j = i + 4; j < sizeof(rsp) && rsp[j] >= ' ' &&
                                rsp[j] <= '~';
             j++)
          Serial.print((char)rsp[j]);
        Serial.println();
        break;
      }
    }
    if (!sawStart) {
      bool allFF = true, allZero = true;
      for (uint8_t i = 0; i < sizeof(rsp); i++) {
        if (rsp[i] != 0xFF) allFF = false;
        if (rsp[i] != 0x00) allZero = false;
      }
      if (allFF || allZero)
        Serial.println(F("[3] FAIL: MISO flat — MISO wire (M0 MISO ->"
                         " \"SDA\"/GPIO23) most suspect"));
      else
        Serial.println(F("[3] FAIL: garbage — SCK (M0 SCK -> \"MOSI\"/GPIO18)"
                         " or MOSI (M0 MOSI -> \"14\"/GPIO14) suspect"));
    }
  }
}

}  // namespace

void setup() {
  Serial.begin(115200);
  uint32_t t0 = millis();
  while (!Serial && millis() - t0 < 3000) delay(10);
  Serial.println();
  Serial.println(F("=== HUZZAH32 wire probe (Appendix A.2 rig) ==="));

  pinMode(PIN_CS, OUTPUT);
  digitalWrite(PIN_CS, HIGH);
  pinMode(PIN_RST, OUTPUT);
  digitalWrite(PIN_RST, HIGH);
  pinMode(PIN_READY, INPUT);
  pinMode(PIN_SCK_BB, OUTPUT);
  digitalWrite(PIN_SCK_BB, LOW);  // SPI mode 0 idle
  pinMode(PIN_MOSI_BB, OUTPUT);
  digitalWrite(PIN_MOSI_BB, LOW);
  pinMode(PIN_MISO_BB, INPUT);
}

void loop() {
  probe();
  delay(5000);  // wiggle wires between passes
}

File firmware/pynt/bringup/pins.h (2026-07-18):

// Pynt pin map — every number here traces to a cited source; the bring-up
// tests are the ground-truth verification (docs/hardware/checklists.md).
#pragma once

#include <Arduino.h>

// ---- TFT: ILI9341 on the 8-bit parallel bus ----
// Values from Adafruit's own graphicstest_pyportal.ino (Adafruit_ILI9341
// examples) — the reference for the tft8bitbus constructor.
#define TFT_D0        34   // first of 8 contiguous data pins (PA16-PA23)
#define TFT_WR        26
#define TFT_DC        10
#define TFT_CS        11
#define TFT_RST       24
#define TFT_RD         9
#define TFT_BACKLIGHT 25

// ---- Resistive touch (4-wire, raw ADC) ----
// Pin numbers from Adafruit's official "Adafruit PyPortal Pynt Pinout.pdf"
// (github.com/adafruit/Adafruit-PyPortal-PCB) — the pyportal_m4
// variant.cpp comments alone are misleading here; this repo previously had
// all four off by one (16/17/18/19-style shift), confirmed against the
// official diagram and the bring-up 'y' raw-pin test (2026-07-17: Y-axis
// gradient never formed because the "YD" pin wasn't actually the YD
// electrode). Electrode polarity (XP vs XM etc.) is still a convention
// guess — the 'p'/'y' raw-dump tests validate; if axes mirror, swap the
// pair and record it in checklists.md.
#define TOUCH_YD 18  // PB00
#define TOUCH_XL 19  // PB01
#define TOUCH_YU 20  // PA06 (also SERCOM0/PAD2 — unused by our UART)
#define TOUCH_XR 21  // PB08

// ---- microSD (shared SPI with the AirLift; SERCOM2) ----
#define SD_CS 32

// ---- ESP32 AirLift (WiFiNINA over the shared SPI) ----
// The pyportal_m4 variant defines these; #ifndef keeps us compatible if
// the macro names differ between core versions.
#ifndef SPIWIFI_SS
#define SPIWIFI_SS   8
#endif
#ifndef SPIWIFI_ACK
#define SPIWIFI_ACK  5
#endif
#ifndef ESP32_RESETN
#define ESP32_RESETN 7
#endif
#ifndef ESP32_GPIO0
#define ESP32_GPIO0  6
#endif
#define SPIWIFI SPI

// ---- GNSS UART: F9P UART1 on D3/D4 via SERCOM0 (docs/hardware/wiring.md) ----
// D3 = PA04 = SERCOM0/PAD0 (ALT) = TX (SAMD51 TX must be pad 0)
// D4 = PA05 = SERCOM0/PAD1 (ALT) = RX
// NOTE the physical-socket label swap risk (wiring.md) — pin numbers are
// firmware-side and correct regardless; only the *sockets* may be
// mislabeled on the silkscreen.
#define GNSS_TX_PIN 3
#define GNSS_RX_PIN 4
#define GNSS_BAUD   115200

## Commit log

2026-07-12 Project kickoff: plan, decisions, and open questions
    Third RTK build: PyPortal Pynt (SAMD51 + AirLift + TFT touch) driving a
    simpleRTK2B Lite over F9P UART1, UART2 reserved for a future radio.
    Decisions locked: PlatformIO C++, Rover+logging+Base in v1, SW Maps over
    WiFi TCP, public repo. Open items tracked in docs/QUESTIONS.md.
2026-07-12 Answer hardware inventory questions from owner photos
    Lite + HC977 antenna move over from the Feather rig; PNY Elite 32GB U1
    microSD; cabling on hand; enclosure after electronics, portrait UI.
2026-07-12 Phase 0: hardware verification pack
    wiring.md (4-wire Pynt<->Lite plan, D3/D4 label-swap check, SERCOM0 UART
    recipe, never-connect list), power.md (shape A single-bank vs shape B
    two-feed, blocking checks P1-P4), platform.md (bus map, SPI contention
    math, TFT parallel driver, touch, RAM budget), ucenter-config.md
    (re-verification for the moved F9P), checklists.md (per-board bring-up
    + integration gates).
2026-07-12 Phase 1: bring-up test suite, compiling clean
    Serial-menu bench tool (firmware/pynt/bringup/): TFT fills + portrait
    rotation pick, touch raw dump, AirLift version/scan/join + TCP echo on
    :10110, SD 4MB append with latency histogram, D3/D4 UART loopback +
    TX-socket identify (label-swap tests), live NMEA echo, free-RAM report.
    PlatformIO env pynt-bringup: RAM 2.3%, flash 4.6%. Not yet run on
    hardware.
    [main_bringup.cpp, pins.h]
2026-07-12 Phase 2: Rover firmware, compiling clean
    Single-core superloop replacing the Feather two-MCU split: NTRIP polled
    state machine (WiFiNINA) -> direct RTCM injection; SparkFun v3 file
    buffer -> SD .ubx logger (M0 pipeline rules kept: one bounded write per
    pass, preallocation, boot-only FAT scan, collision guard, 8s sync);
    portrait 240x320 touch UI (fix header, POS/SYS pages, LOG/PAGE/PWR with
    two-tap shutdown); SW Maps TCP NMEA on :10110; SD /config.txt settings
    + serial menu. pynt-rover: RAM 9.7%, flash 10.3%. Not hardware-run yet.
    [gnss.cpp, gnss_config.cpp, main.cpp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]
2026-07-12 Code review fixes: SD extract bool-return bug + logubx boot order + LOG button refresh
    extractFileBufferData returns bool (not a count) and fails when asked
    for more than is buffered -- gnssLogExtract now requests exactly
    min(available, chunk), matching the PaulZC pattern. Without this the
    logger wrote 1-byte chunks or nothing. Also: logubx from /config.txt is
    now applied after settingsLoad (it was latched before the card was
    read), and the LOG touch button refreshes when the file opens
    asynchronously on GNSS time-valid.
    [gnss.cpp, main.cpp, sd_logger.cpp]
2026-07-12 Phase 3: Base mode (survey-in / fixed, RTCM3-on-UART2 config only)
    TMODE survey-in (svindur/svinacc settings) or fixed-LLH (fixedlat/lon/
    alt); RTCM3 MSM4 set configured on UART2 only -- socket stays empty,
    baud untouched (future radio decides). NAV-SVIN callback -> header
    states (BASE/SVIN.../BASE OK) + SVIN progress line; b_ log prefix;
    mode=base|rover live-applies via the serial menu. RAM 9.7%, flash 11.1%.
    [gnss.cpp, gnss_config.cpp, sd_logger.cpp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]
2026-07-12 Code review round 2: AirLift CS at boot, F9P reconnect, SD write checking
    - Deselect the AirLift SS before SD init (floating CS on the shared SPI
    bus could let the NINA drive MISO during the very first SD access)
    - Retry the F9P connect every 5 s if not detected at boot (Feather
    behavior; a reseated Lite must not require a reboot)
    - Check logFile.write() returns; on failure close + mark SD failed
    loudly instead of counting bytes that never landed
    - Correct the WiFi.begin stall figure in ntrip.cpp (up to ~10 s)
    [gnss.cpp, main.cpp, ntrip.cpp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]
2026-07-12 Q18: simultaneous WiFi+BLE on the AirLift -- researched, not viable yet
    Arduino nina-fw 3.0.x moved BLE HCI onto SPI (simultaneous WiFi+BLE on
    official NINA-W102 boards); verified Adafruit fork v3.3.0 has not
    adopted it (HCI still UART-only, mode-exclusive). BLE stays out;
    re-evaluate when adafruit/nina-fw merges HCI-over-SPI.
2026-07-18 Bench pass: bring-up log + raw touch-pin diagnostic test
    Recording live bring-up results (power, TFT rotation, WiFi, SD latency,
    D3/D4 label-swap resolution, free RAM) in docs/hardware/bringup-log.md.
    Added 'y' bring-up test: drives each touch axis and reads both
    opposite-axis electrodes simultaneously, to isolate a dead sense pin
    from a dead drive pin -- the stock 'p' test only exposes the library's
    already-computed x/y, which was masking a stuck Y reading during bench
    testing.
    [main_bringup.cpp]
2026-07-18 Fix touch pin off-by-one bug (TOUCH_YD/XL/YU/XR were all one pin low)
    Bench testing found Y-axis touch stuck at 0. The bring-up sketch's new
    'y' raw-pin diagnostic showed both sense pins pinning to the drive rail
    on touch instead of a graded value -- the signature of a broken ground
    reference, not a dead sense pin.
    Cross-checked against Adafruit's official "Adafruit PyPortal Pynt
    Pinout.pdf" (github.com/adafruit/Adafruit-PyPortal-PCB): chip ports in
    pins.h were correct (PB00/PB01/PA06/PB08) but every Arduino pin number
    was off by exactly one (17/18/19/20 instead of 18/19/20/21). TOUCH_YD
    was actually toggling an unrelated pin, so the Y-axis drive never
    grounded the real electrode. TOUCH_XL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
    [pins.h]
2026-07-18 Confirm touch pin fix on hardware; record real corner calibration values
    Re-ran the bring-up sketch's 'p' test after the off-by-one pin fix:
    Y now varies across the full range with touch position instead of
    pinning at 0. Recorded real 4-corner raw values for Phase 2 ui.cpp
    calibration -- both axes read inverted vs. typical screen convention
    at rotation 2, noted for when that mapping code gets written.
    Section 2 (Pynt) of the bring-up log is now fully closed out.
2026-07-19 Close section 1: Lite u-center re-verification, config fixed on hardware
    The Feather-era config on this Lite was not actually correct for this
    project's Rover/RAWX-logging needs: RTCM3X-out and NMEA-in were both
    backwards, RAWX/SFRBX logging was entirely off, and elevation mask +
    QZSS were off-target. Walked the VALGET/VALSET/VALGET loop from
    docs/hardware/ucenter-config.md end to end -- every key group now
    confirmed correct in Flash and survives a power cycle.
2026-07-19 Source Lite power/ground from D3/D4 JST instead of I2C STEMMA
    D3 and D4 VCC pins measured 5V on hardware (bring-up P1), same as the
    I2C STEMMA port (P2). Since D4 already carries a signal wire to the
    Lite and this project has no I2C use, route power+ground off D4's own
    VCC/GND pins instead of a separate STEMMA connection -- one fewer
    connector to wire, STEMMA stays fully unpopulated.
    Updated wiring.md's wire list and diagram accordingly, and power.md's
    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
2026-07-19 Close section 3: integration gates all passed, wiring confirmed on hardware
    Power under load: 4.77V at Lite JST pin 1 (>= 4.5V floor). 30-min soak
    clean, no brownout resets. Data union confirmed via the 'n' live-echo
    test -- NMEA sentences plus UBX-RXM-RAWX/SFRBX binary interleaved,
    which is the expected signature of both configured message types
    actually flowing, not corruption.
    Gate 4 (1-hour full-stack soak with NTRIP+logging+backlight) deferred
    to Phase 2 rover firmware -- out of scope for the bring-up sketch.
2026-07-27 Pre-flight for the rover soak: real touch calibration + soak runbook
    ui.cpp now uses the bench-captured corner values (rotation 2, both axes
    inverted, 10-bit range) instead of the provisional 12-bit constants, and
    sets the bench-chosen rotation 2. Soak runbook added to bringup-log.md
    gate 4; README phase status updated (Phase 1 bench pass complete).
2026-07-27 Log integration gates 1-3 passed: power union (P3/P4) + data union
    NMEA live in the Pynt console via the n test; interleaved UBX binary
    also seen, which is the expected RAWX/SFRBX output from the section-1
    UART1 config, not corruption. Only gate 4 (1-hour soak) remains.
2026-07-27 Mid-soak findings: caster DNS fix, TCP accept fixes, Phase 5 scope
    - settings.h: acorn-gnss.net apex lost its DNS A record; default caster
    is now www.acorn-gnss.net (verified listening on :2101).
    - tcp_nmea.cpp: dedup compared WiFiClient via operator bool (the fork
    has no operator==), blocking every accept after the first; compare
    remote IP:port instead.
    - QUESTIONS.md Q19 (new): iOS SW Maps is BLE-only — TCP phone app must
    be QField/Survey123 class; nina-fw accept is data-gated (client must
    send a byte), confirmed live during the soak.
    - README + Q18: Phase 5 scoped — port Arduino nina-fw 3.x (HCI-over-SPI
    WiFi+BLE coexistence) to the AirLift for SW Maps over BLE NUS.
    Co-Au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
    [settings.h, tcp_nmea.cpp]
2026-07-27 Phases 2-3 complete: 1-hour soak PASS, base-mode spot check PASS
    Soak (66 min): zero resets, RTK FIX from minute 2 to end, NTRIP
    uninterrupted, 10.8 MB RAWX (~10 MB/h), SD clean. A ~25 min mid-run
    serial gap was host-side USB buffering; the device never blinked.
    Base spot check: mode=base applied live, survey-in valid at exactly
    300 s / 1.46 m mean acc, live switch back to rover, UART2 untouched.
    Found: the b_ log prefix never appeared (prefix chosen only at file
    open) — serial_menu.cpp now cycles the logger on a mode= change so
    each mode gets its own file. Flashed; rotation re-check next bench sit.
    Carried forward: iOS app choice (Q19), WiFi.begin measured 10.9 s vs
    the 4 s ring sizing,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
    [serial_menu.cpp]
2026-07-27 Close post-soak items: IP on display, MON-VER report, 32K ring, QField
    - SYS page shows the WiFi IP and TCP port (field request: the phone app
    needs ip:port and there was no way to see it without a terminal);
    serial status prints ip=addr:port too.
    - gnssInit queries MON-VER and prints module/fw/protver — u-center
    cannot coexist with the Pynt on UART1, so the firmware reports it.
    Recorded: ZED-F9P HPG 1.51, protver 27.50 (section-1 item closed).
    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
2026-07-27 Log: touch buttons verified; SD corruption + safe-eject procedure
    All three touch buttons work — the bench calibration and inverted-axis
    mapping are confirmed on hardware, closing the last Phase 2 unknown.
    SD card read back corrupted after the first bench day (card likely
    pulled with a log file open); documented the PWR-two-tap safe-eject
    procedure and the card-swap escalation if it recurs on clean shutdowns.
2026-07-27 Bring-up log fully closed: .ubx parse verified in u-center
    Fresh 4-min capture (823 KB, closed via log off) played back clean:
    RAWX 1688-1720 B at 1 Hz + SFRBX, all well-formed. Clean close ->
    clean read supports the unsafe-eject theory for the earlier corruption.
    Every gate and carried-forward hardware item is now green except BUFH
    (read off the SYS page whenever convenient).
2026-07-27 BUFH recorded (9-14K of 32K) + convbin RINEX verification: zero gaps
    Owner read BUFH off the SYS page: 9,000-14,000 B typical against the
    32 KiB file buffer (~43% peak) — platform.md budget confirmed with
    real data. convbin (demo5 v2.5.1) converted the 823 KB capture to
    RINEX 3.04: 304 obs epochs in a 304 s span (no dropped epochs at
    1 Hz), dual-freq on all four constellations, 38 nav messages, with
    NTRIP + TCP active during capture. Every bring-up item is now closed.
2026-07-27 Field note: SD card must be present at boot (no hot-insert retry)
    sd.begin() runs once in setup with no retry path, so a card inserted
    after power-on is never initialized until a power cycle. Documented
    alongside the safe-eject procedure; hot-insert retry noted as a
    Phase 4 candidate.
2026-07-27 Coex spike pack: custom nina-fw 3.0.1-airlift + upstream WiFi/BLE host stack
    Opens the simultaneous-WiFi+BLE path Q18 parked. Module side: vendor
    arduino/nina-fw 3.0.1 (firmware/nina-fw-airlift/, ESP-IDF v4.4.8 Docker
    build) with the single AirLift change, SPI slave MOSI 12->14. Host side:
    upstream WiFiNINA 2.1.1 (git-tag pin) + vendored Arduino_SpiNINA 0.0.2 +
    vendored ArduinoBLE 2.1.0 with a 2-line gate patch exposing its NINA SPI
    HCI transport to non-Arduino boards via -DBLE_NINA_SPI_TRANSPORT.
    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
    [partitions.csv]
2026-07-27 Pin nina-fw subtree to LF checkouts
    The vendored tree checked out CRLF on Windows (core.autocrlf), which
    breaks GNU make + gen_crt_bundle inside the Linux/ESP-IDF build. Force
    LF via .gitattributes so every clone builds regardless of host git
    config; store contents were already normalized.
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2026-07-27 Metro flashed with 3.0.1-airlift; Spike A passes all four gates
    Section 3 flash needed two host-side workarounds on this machine, now
    documented in coex-bench.md and captured in flash_via_bridge.py (parked
    next to the bin — the rollback path depends on it): stock esptool forces
    DTR/RTS low on Windows so the SAMD CDC bridge eats the ROM loader's
    replies, and compressed writes die deterministically mid-stream
    (--no-compress writes clean). Stock firmware backed up to
    metro-stock-backup.bin (local, gitignored) before writing.
    Spike A: NINA 3.0.1 over SPI (MOSI 12->14 patch verified), hotspot
    scanned and joined, 240 s at 5 s cadence with zero drops. Full capture
    log committed alongside the bin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
    [flash_via_bridge.py]
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2026-07-27 FEATURE_BLE: BLE NUS phone link as the rover's seventh polled module
    Port of Spike B's proven service (same NUS UUIDs, same one-sentence-
    per-notification 120-byte framing that streamed 17+ min concurrent with
    TCP on the Metro), advertising as PyntRTK-rover — the Q19 iOS SW Maps
    path, running ALONGSIDE the TCP server, not replacing it.
    Plumbing: tcp_nmea's existing drain tees each sentence into ble_nus's
    8-line drop-oldest ring (including on the WiFi-down path, so the future
    radio-corrections scenario keeps its phone link); bleNusPoll() runs
    after gnss/ntrip/tcp in the superloop and sends at most 3 notifications
    per pass, only while a central is subscribed — bounded SPI work, WiFi/
    NTRI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
    [ble_nus.cpp, main.cpp, serial_menu.cpp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]
2026-07-27 Appendix A.2: HUZZAH32 variant of Spike C (no soldering) + do-not-stack analysis
    A hand-wired HUZZAH32 running the same NINA_W102-3.0.1-airlift.bin
    stands in for the AirLift Wing, making Spike C optionally runnable
    again: same ESP32 silicon family, trivial flashing over its own USB
    (no passthrough/bridge workarounds), and it revalidates the MOSI-14
    patch on a second board. New env feather-soak-coex-huzzah = the soak
    sketch with -DSOAK_FORCE_GPIOIRQ_HIGH: the HUZZAH32 doesn't break out
    GPIO0, so the data-ready IRQ pin (host D10) stays unwired and gets an
    INPUT_PULLUP after driver init — SpiDrv::available() then always does
    the real SPI query. Correct, just chattier; the IRQ-gated path stays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
    [main_feather_soak.cpp]
2026-07-28 feather-wire-probe: pin-by-pin diagnosis for the A.2 HUZZAH32 rig
    Bit-bangs nina-fw's own SPI choreography from the M0 and issues a
    verdict per stage: boot trace (RESET+READY wires, module arming), CS
    ack (slave must drive READY HIGH within 5 ms of CS low — spiSlaveSelect
    contract), and a bit-banged GET_FW_VERSION (SCK/MOSI/MISO). Re-probes
    every 5 s for live wire-wiggling. First field use immediately isolated
    a miswired CS jumper after the soak's WL_NO_MODULE symptom left four
    wires suspect.
    [main_wire_probe.cpp]
2026-07-28 TCP accept is data-gated on ALL nina-fw; use server.accept() on coex stack
    Root cause found from source during the A.2 soak bring-up, correcting
    the Spike B bench note: WiFiServer::available() sends
    availServer(accept=false), so nina-fw's availDataTcp takes its legacy
    data-gated branch on every firmware including 3.0.1 — a listen-only
    client is never surfaced (the soak monitor sat connected-but-unserved
    for minutes). nina-fw 3.x's true-accept branch (accept=1) is reached
    only through upstream WiFiNINA 2.x's new server.accept() API; verified
    live on the HUZZAH32 rig (acc=1 within one loop pass, pure listener).
    Spike B "silent accept works" was a misread — its scripted client
    pinged on con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
    [main_feather_soak.cpp, main_wire_probe.cpp, tcp_nmea.cpp]
2026-07-28 Spike C PASS: 72-min SD+WiFi+BLE soak on the A.2 HUZZAH32 rig
    All A.1 gates green: writes monotonic (4369 writes / 4376 s, zero
    resets), sdErrors=0 with worst write 109.7 ms (same order as the Pynt's
    93.6 ms WiFi-only baseline), wifiDrops=0, one TCP listener held 70+ min
    (4262 lines at 1 Hz, zero reconnects, max gap 1.6 s, silent-accepted
    via server.accept()), and five BLE sessions totaling ~48 min with every
    deliberate bounce recovering cleanly and never perturbing TCP/SD/WiFi.
    Shared-SPI contention is now proven on spare hardware; section 7's Pynt
    soak re-proves on target instead of proving first.
2026-07-29 Web config GUI: foundation + W1 status dashboard, W0 spike, W2-W5 scaffold
    New branch off coex/nina-fw-airlift (W5 BLE card needs the coex stack).
    Everything behind ENABLE_WEB_CONFIG (default 0, #error without
    COEX_UPSTREAM_NINA); only pynt-rover-coex enables it — pynt-rover
    verified byte-identical (140184/120044).
    W1: web_config.{h,cpp} — eighth superloop module, polled last.
    Hand-rolled non-blocking HTTP/1.1 over WiFiServer/WiFiClient:
    server.accept(), one connection at a time, bounded one-read-or-write
    per pass, Connection: close, 2 s/8 s deadlines. Routes: GET / (gzipped
    SPA from PROGMEM via tools/webui/build_assets.py -> gitignored
    web_assets.h; 5720 B -> 2188 B), GET /api/status (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
    [main.cpp, main_web_probe.cpp, settings.cpp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]
2026-07-29 Section 7 complete: Pynt flashed, coexistence soak PASS on target
    7.1/7.2: stock backup (Adafruit nina-fw 1.6.1 — bringup blank filled)
    then NINA_W102-3.0.1-airlift hash-verified. 7.3 green incl. on-target
    silent-accept (106 sentences to a byte-less listener in 10 s). 7.5:
    75-min RAWX+NTRIP+TCP+BLE soak — NTRIP zero teardowns with continuous
    DGPS/FLOAT corrections (RTK-fixed pending open sky), TCP 50,304 lines
    zero reconnects max gap 1.0 s, BLE ~58 min streaming across three
    sessions with clean bounces and 37,628 NUS notifies (bleDrops 0.6%,
    epoch-burst drop-oldest, tunable), SD 5.0 MB single file, 75/75 loop
    reports (no resets, median worst-pass 132 ms / max 512 ms).
    Simultaneous WiFi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
2026-07-29 W0 bench: gzip/accept/throughput/beginAP/AP+BLE pass; WiFi.end() wedges STA
    Scripted run on the Metro. PASS: gzip-from-PROGMEM serve (2197 B wire /
    5719 B page), silent-connect accept, 57.8-71.2 KB/s on /big (3x the
    bar), beginAP -> WL_AP_LISTENING at 192.168.4.1, and the W2 gate:
    BLE.begin() + advertising WHILE the AP is up and serving HTTP — BLE
    need not stop during provisioning. FAIL in spike form: simultaneous
    connects (0/3) against the blocking one-at-a-time handler — re-check
    against the rover's non-blocking module. Phone-side checks (browser
    render, AP join, BLE visibility) pending; board left in AP+BLE.
    Critical finding: WiFi.end() permanently wedges STA rejoin on nina-fw
    3.0.1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
    [main_web_probe.cpp]
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2026-07-29 W2: WiFi provisioning card + on-demand AP mode, built on the W0 findings
    web_config grows the W2 surface: GET/POST /api/wifi (slot list without
    passwords / urlencoded slot+ssid+pass save, empty ssid clears), GET
    /api/scan (bounded blocking scan, same stall class as a rejoin), POST
    /api/reboot (response drains, log file closes, NVIC_SystemReset), and
    POST-body support in the state machine (Content-Length, 320 B cap,
    413 over). Basic-auth expectation now recomputed per request so a
    password change applies instantly. /api/status adds ssid + ap fields.
    AP provisioning mode per the locked decisions + W0 findings: entered
    ONLY by the TFT AP button; enter = WiFi.end() -> beginAP(
    <hostname>-setup,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
    [ntrip.cpp, web_config.cpp]
2026-07-31 W2 benched live on the Pynt; scan gated to AP mode after STA-drop finding
    Full-stack bench (NTRIP + fix + logging + BLE all live): auth 401/200,
    gzipped SPA + status JSON, POST /api/wifi save/clear persisting to SD,
    and the W0.3 open item RESOLVED - 3/3 and 6/6 parallel requests serve
    fine against the non-blocking module (the spike's 0/3 was its own
    blocking handler). New finding: WiFi.scanNetworks() during an active
    STA association drops the association (self-heals ~30-60 s via the
    ntrip retry loop) - /api/scan now returns 409 in STA and works only in
    AP provisioning mode, where it belongs; SPA surfaces the message.
    Verified on hardware post-fix.
    Also recorded: this Pynt's UF2 bootloader w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
    [web_config.cpp]
2026-08-01 W2 complete: AP provisioning round trip verified; both transitions reboot
    Two hardware findings forced the final design, both from live wire
    logs on the Pynt. (1) The NINA socket table doesn't survive WiFi.end():
    live STA->AP switching starves getSocket, WiFiServer::begin() comes up
    CLOSED and accept() floods phantom clients (nina-fw indexes its socket
    arrays with the stale host sock, out of bounds) - so the AP now only
    ever starts at boot on a freshly reset module, via a one-shot bootap
    flag in /config.txt (self-clearing before AP entry; any exit lands in
    STA). (2) scanNetworks() kills whatever network is live in EITHER mode
    - drops STA associations, permanently stops AP beaconing (st wedge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
    [ntrip.cpp, settings.cpp, settings.h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]
2026-08-01 W3: GNSS + Corrections cards live, benched on the Pynt
    /api/gnss GET/POST: measurement rate (1-5 Hz), dynamic model, elevation
    mask, GSV toggle — persisted to SD and applied to the F9P through the
    existing gnssRequestModeApply() full-VALSET path. gnss_config now
    consumes the W3 settings under ENABLE_WEB_CONFIG; the shipping build
    keeps its fixed constants (footprint unchanged, 140184/120044).
    /api/ntrip GET/POST: caster/port/mount/user/password (blank = keep,
    never echoed) + GGA period, with a new gated ntripRequestReconnect()
    so edits take effect promptly — bench showed RTCM flowing again 8 s
    after the POST. SPA gains both cards (receiver selects + caster form
    with live status line). V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
    [gnss_config.cpp, ntrip.cpp, web_config.cpp]
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2026-08-05 Antenna metrology recorded + enclosure design brought into the repo
    Closes team-review P6 ("no ARP, no antenna height, no phase-centre data
    anywhere"). New docs/hardware/antenna-metrology.md, owner-confirmed
    2026-08-04: ARP = the nut-boss underside (print-bed face, the assembly's
    mesh-verified global minimum); stack ARP -17.2 -> HC977 seat +89.1 =
    A 106.3 mm, total case height 107.3; Calian HC977 PCOs L1 32 / L2-L5 37
    (+/-3, distinct phase centers 5 mm apart, per datasheet Rev.202203 +
    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
    [b_band_full.stl, b_band_test.stl, b_base_test.stl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]
